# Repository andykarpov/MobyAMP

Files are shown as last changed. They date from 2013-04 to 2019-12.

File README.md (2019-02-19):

This project is a hobbyst DIY 2.1 amplifier based on TDA2030A and TDA1557Q chips.

The heart of the project is an arduino compatible custom board called "interface board" 
with atmega328 microcontroller and 16x2 (or 20x4) LCD panel, encoder, resistive keyboard and audio processor PT2322.
It is possible to make it even on a breadboard using a standard arduino and couple of wires :)

Some basic boards, such as interface board and amp boards contains both pcb design and electrical schematics.
All drawing (build/pdfs/pngs/etc) are already prepared to be printed on transarent sheets to make a final PCBs 
from the presensitized PCBs at home.

A few other things are not yet described (such as power board, connection between modules, etc, etc).
To be continued...

Custom eagle libraries are located under eagle_libraries folder.
To make a gerber / images from the command line you must have:
1. OSX (could work on other UNIX/Linux boxes)
2. eagle
3. homebrew
4. gerbv

Scripts should be changed to reflect a current Eagle installation path.

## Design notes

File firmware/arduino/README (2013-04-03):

Dependencies:

1. I2C library:  http://dsscircuits.com/articles/arduino-i2c-master-library.html
2. Encoder library: http://www.pjrc.com/teensy/td_libs_Encoder.html
3. Button library: http://playground.arduino.cc/Code/Button

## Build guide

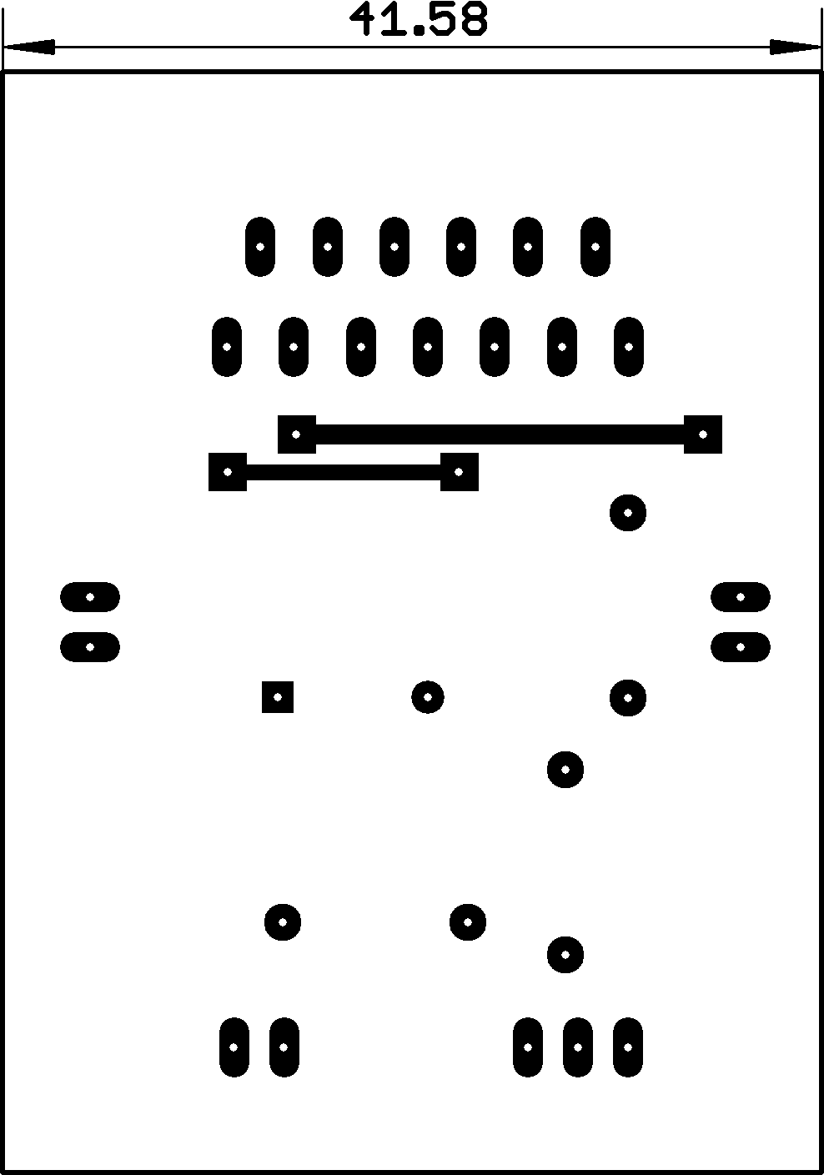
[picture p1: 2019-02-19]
build/png/tda1557q_v_1_0_pcb_top.png

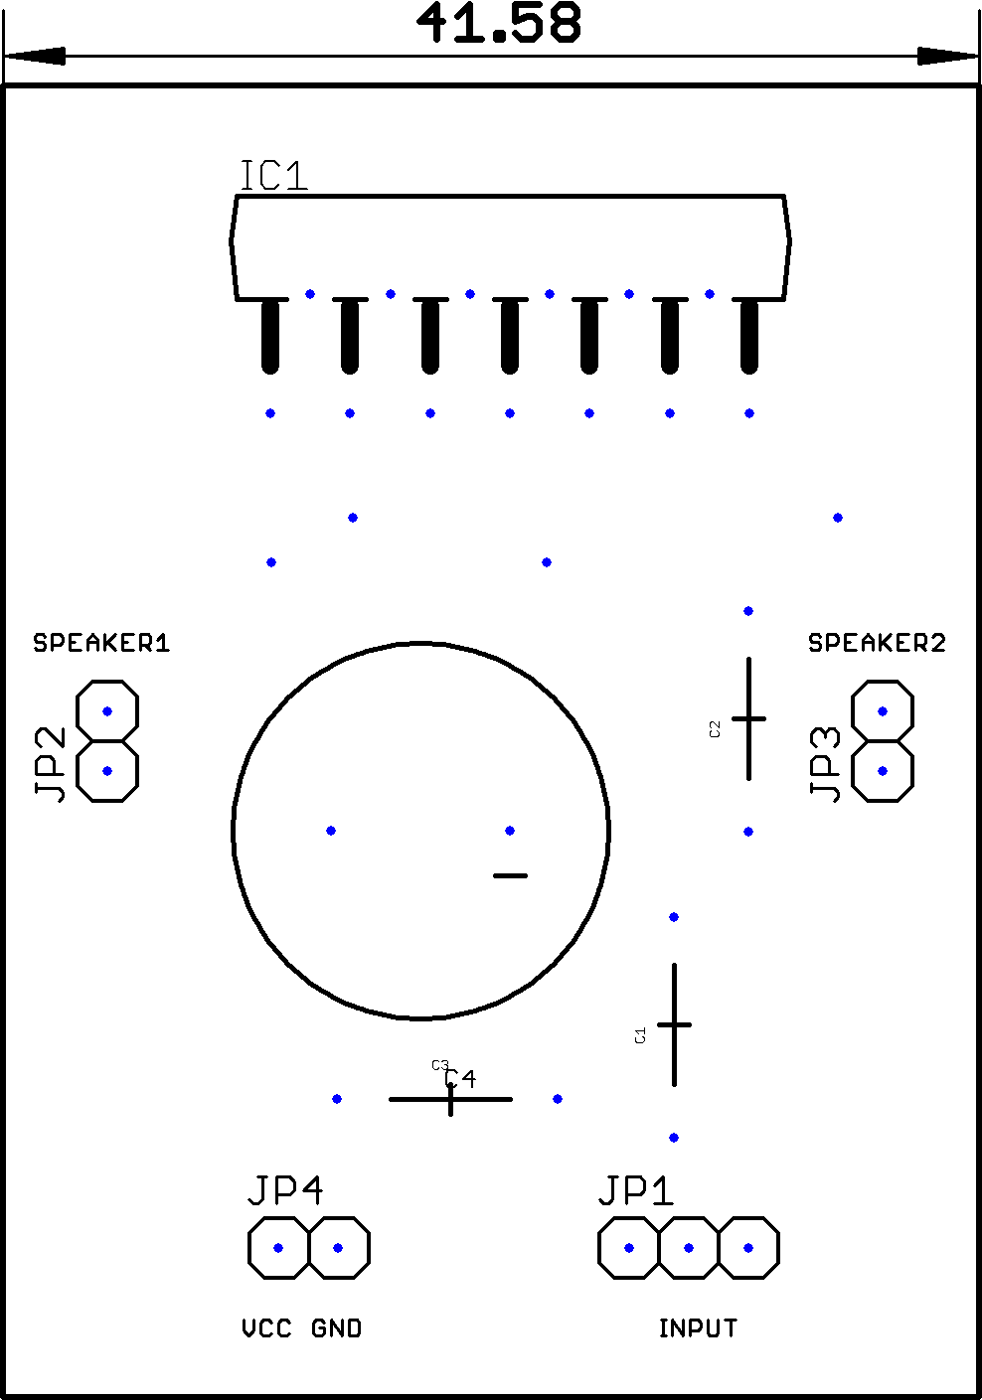
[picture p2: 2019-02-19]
build/png/tda1557q_v_1_0_pcb_cmp.png

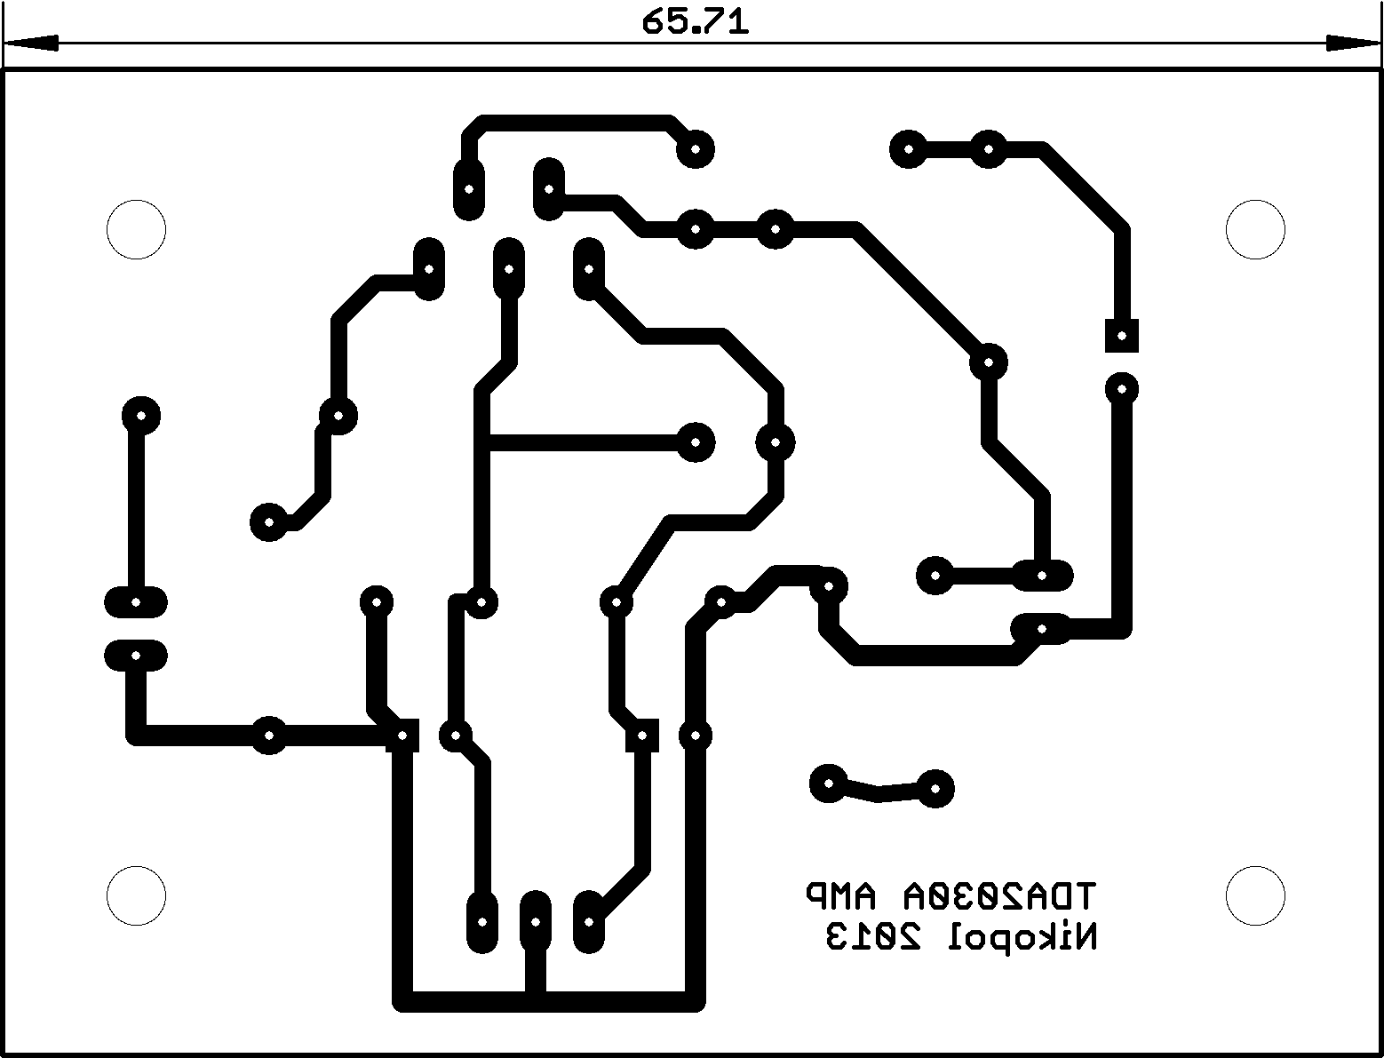
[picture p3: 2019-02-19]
build/png/tda2030a_v_1_0_pcb_bottom.png

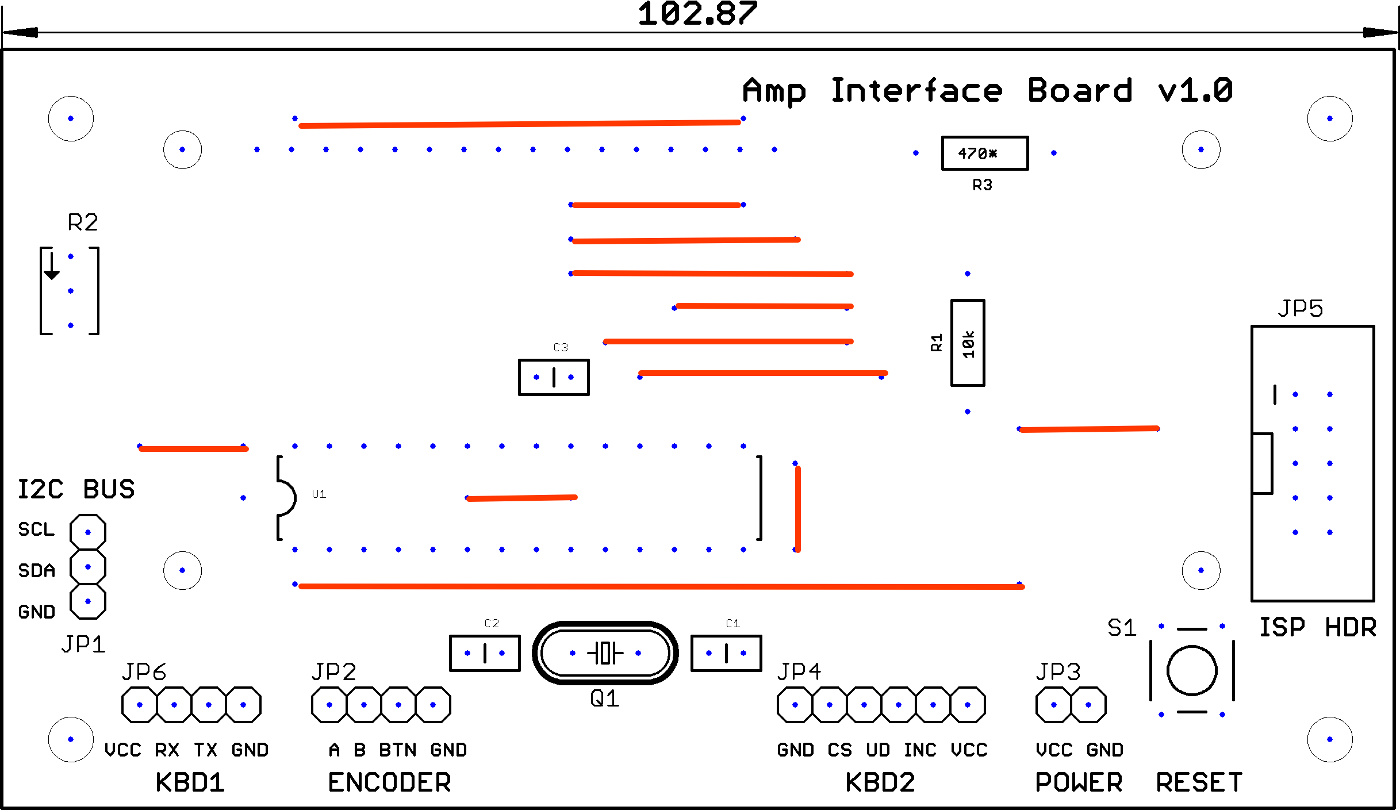
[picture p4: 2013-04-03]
build/png/interface_v_1_0_pcb_cmp_jumpered.png

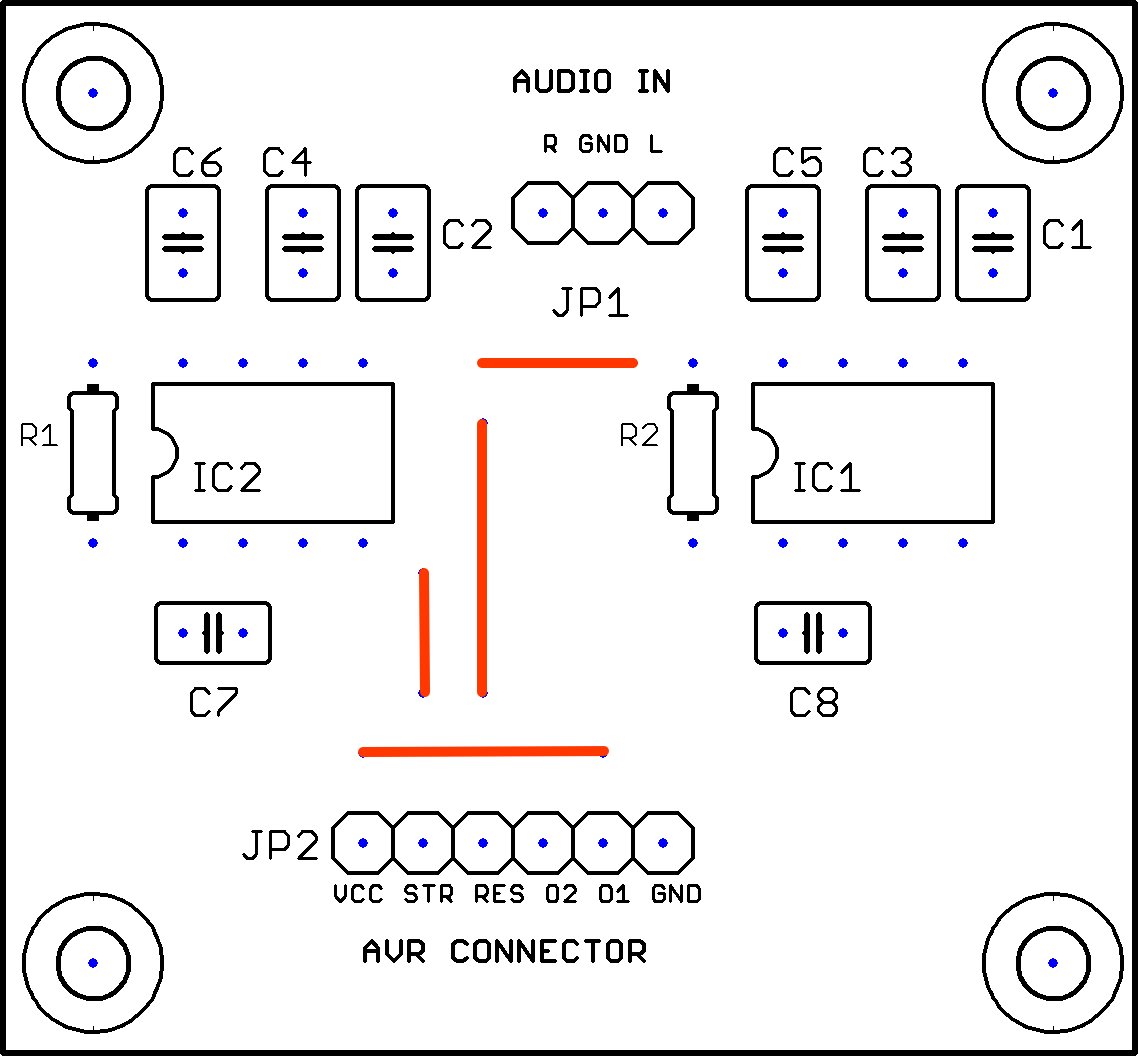
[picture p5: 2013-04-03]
build/png/msgeq7_v_1_0_pcb_cmp_jumpered.png

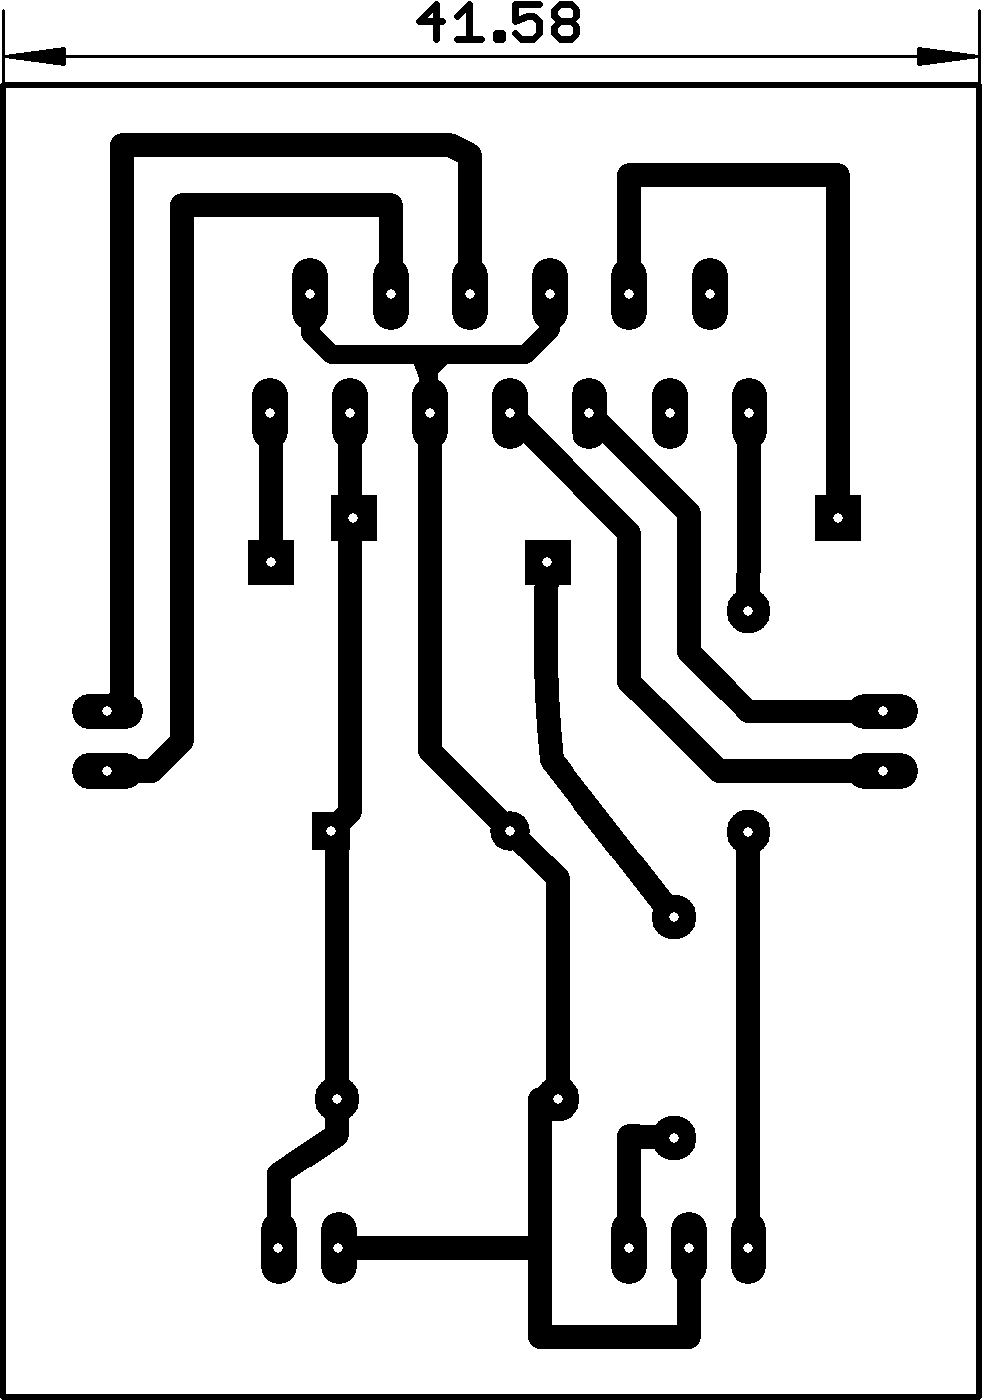
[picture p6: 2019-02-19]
build/png/tda1557q_v_1_0_pcb_bottom.png

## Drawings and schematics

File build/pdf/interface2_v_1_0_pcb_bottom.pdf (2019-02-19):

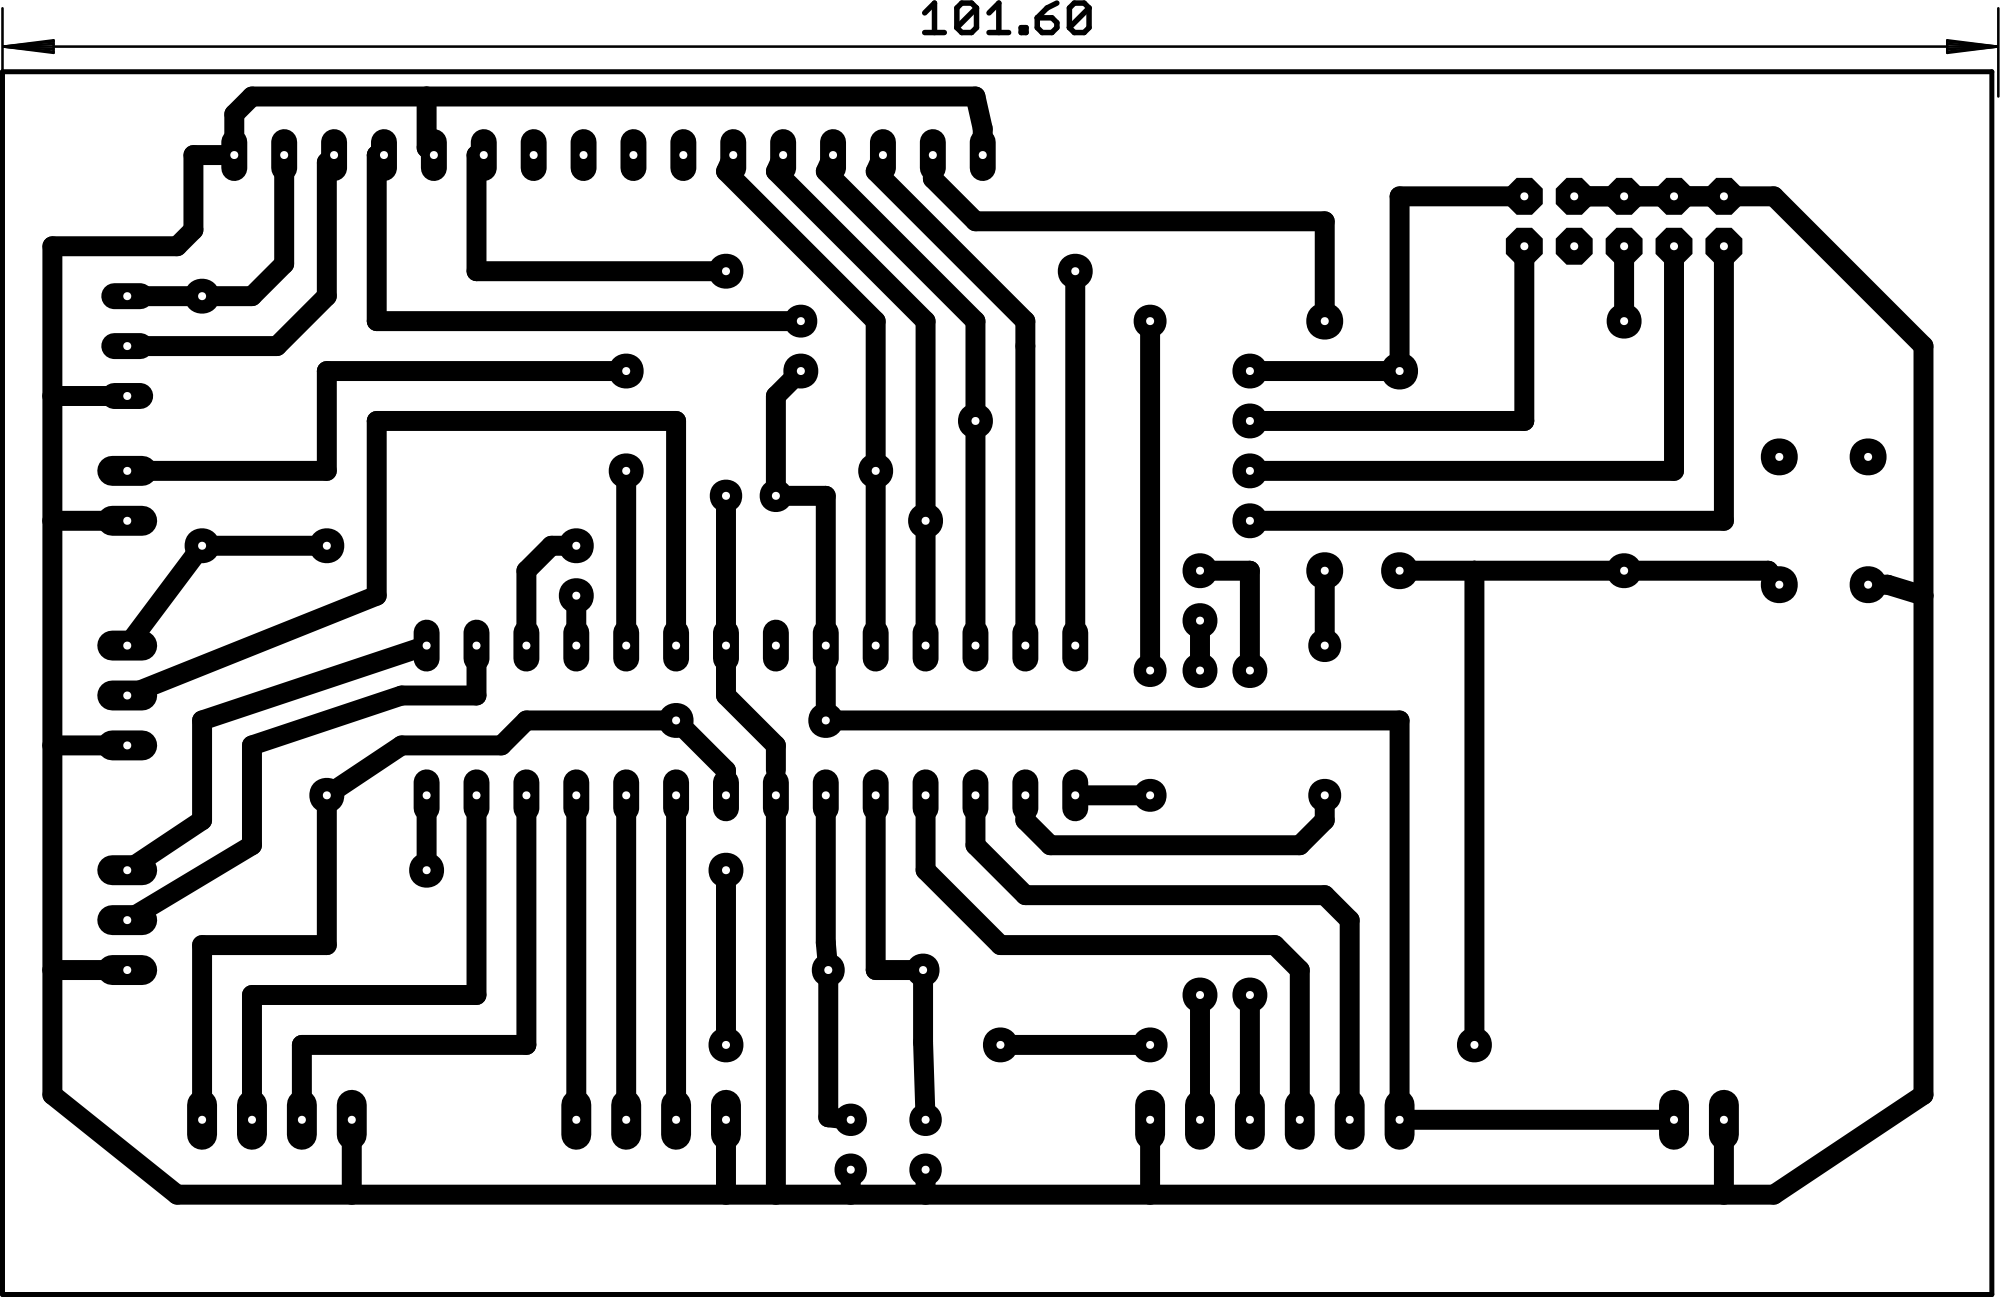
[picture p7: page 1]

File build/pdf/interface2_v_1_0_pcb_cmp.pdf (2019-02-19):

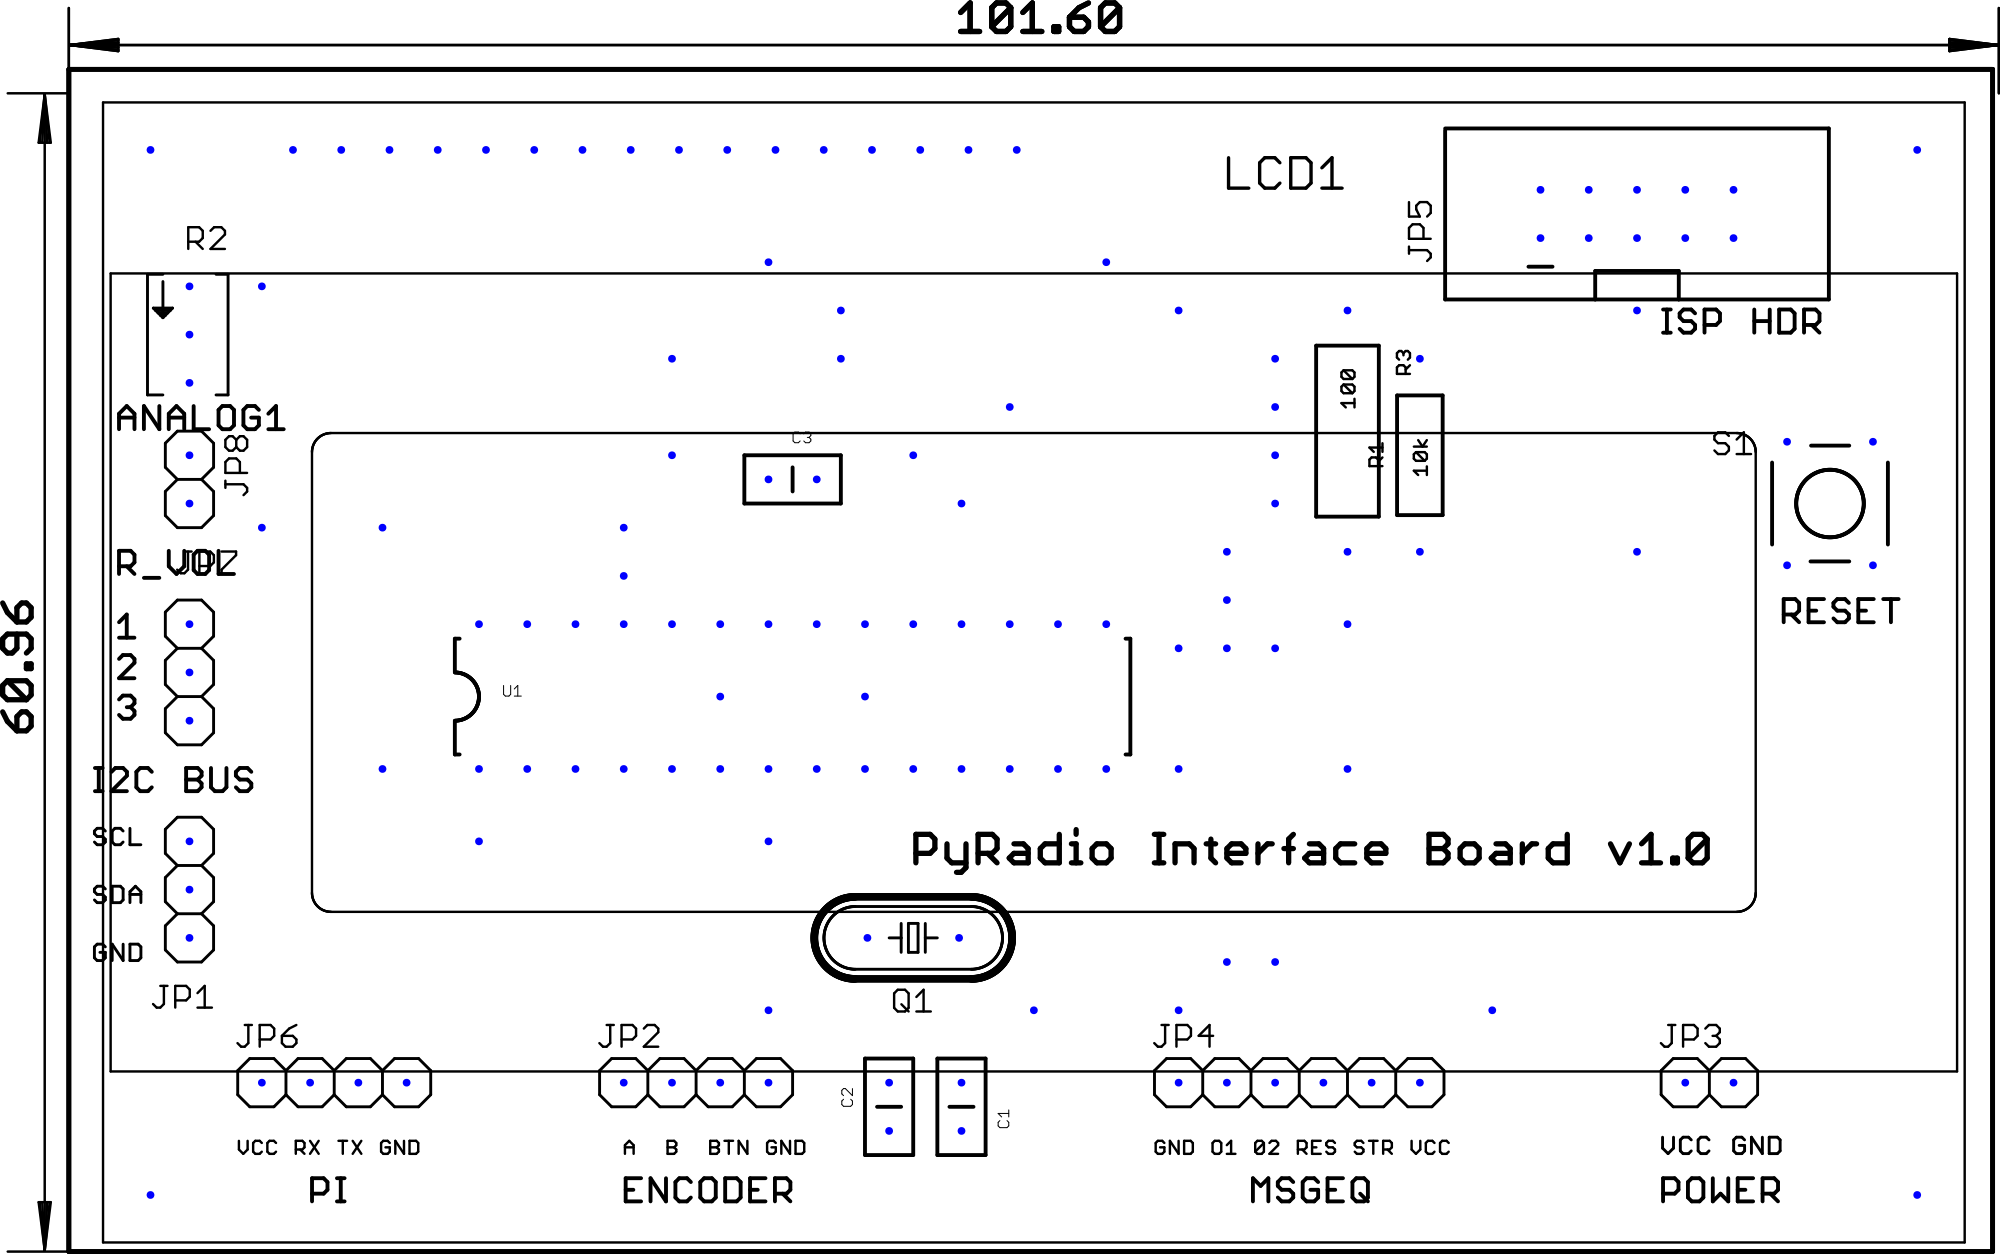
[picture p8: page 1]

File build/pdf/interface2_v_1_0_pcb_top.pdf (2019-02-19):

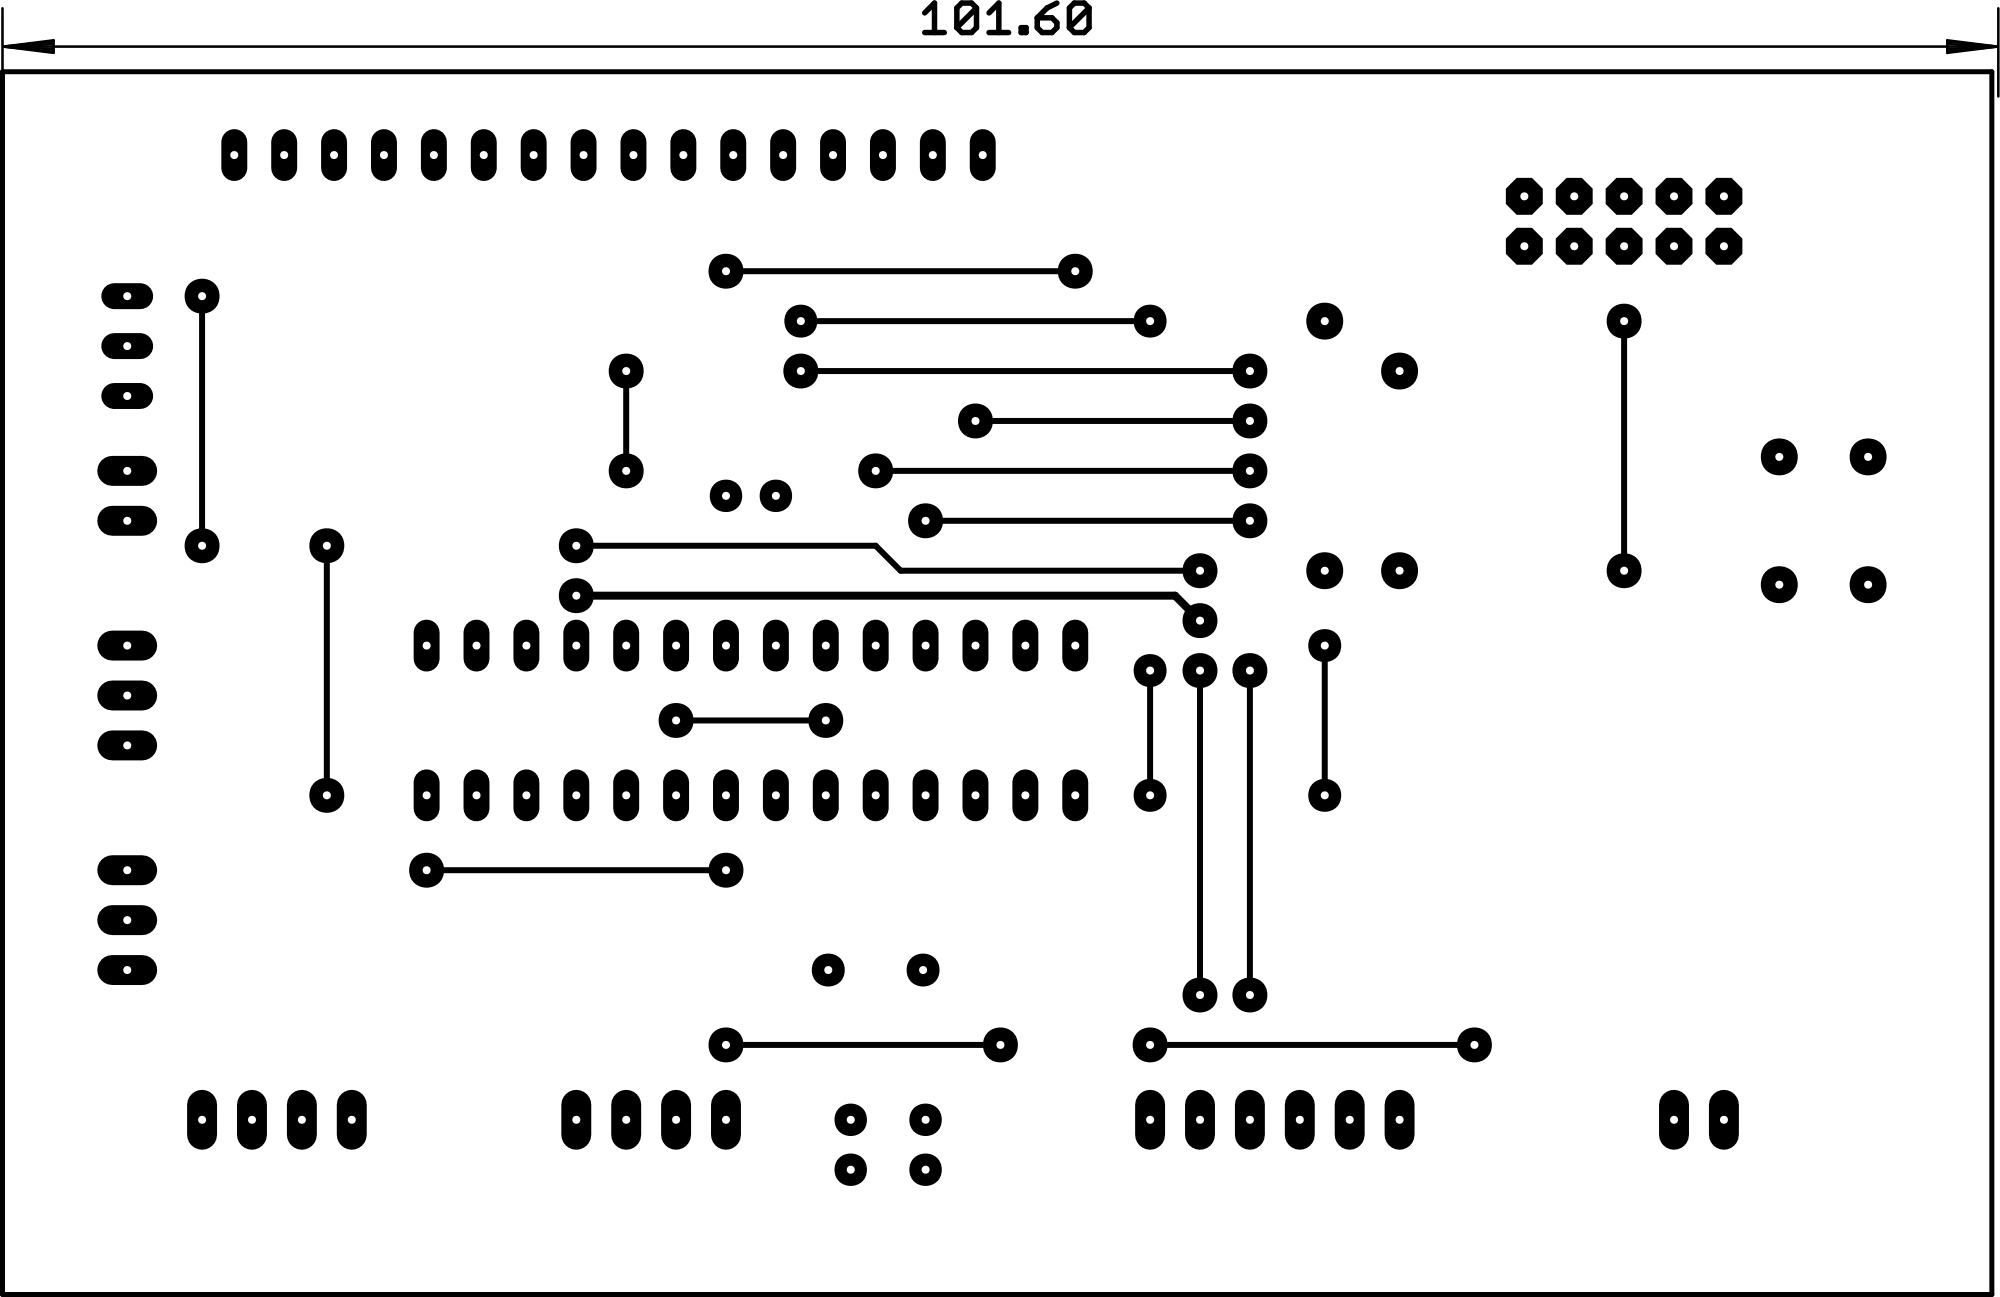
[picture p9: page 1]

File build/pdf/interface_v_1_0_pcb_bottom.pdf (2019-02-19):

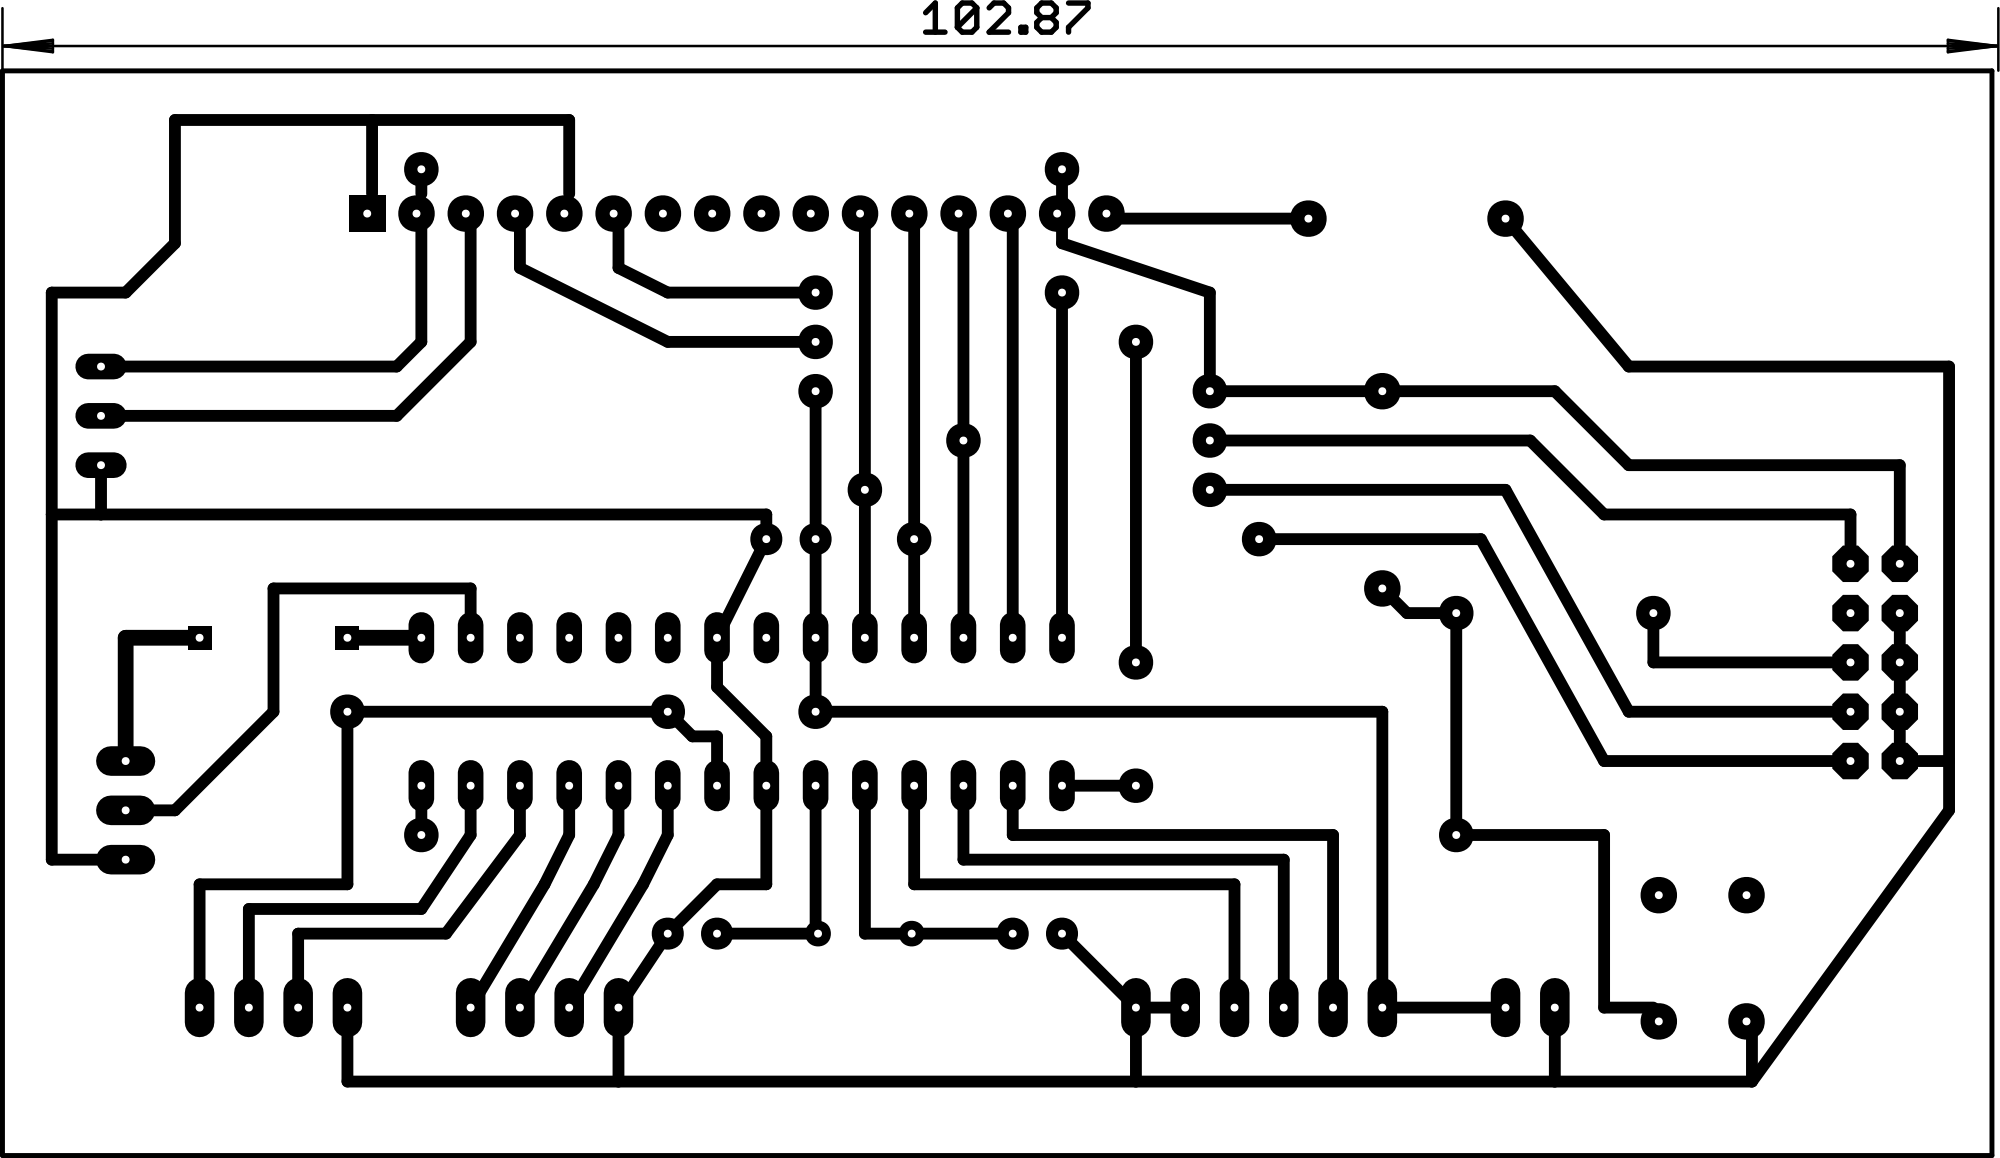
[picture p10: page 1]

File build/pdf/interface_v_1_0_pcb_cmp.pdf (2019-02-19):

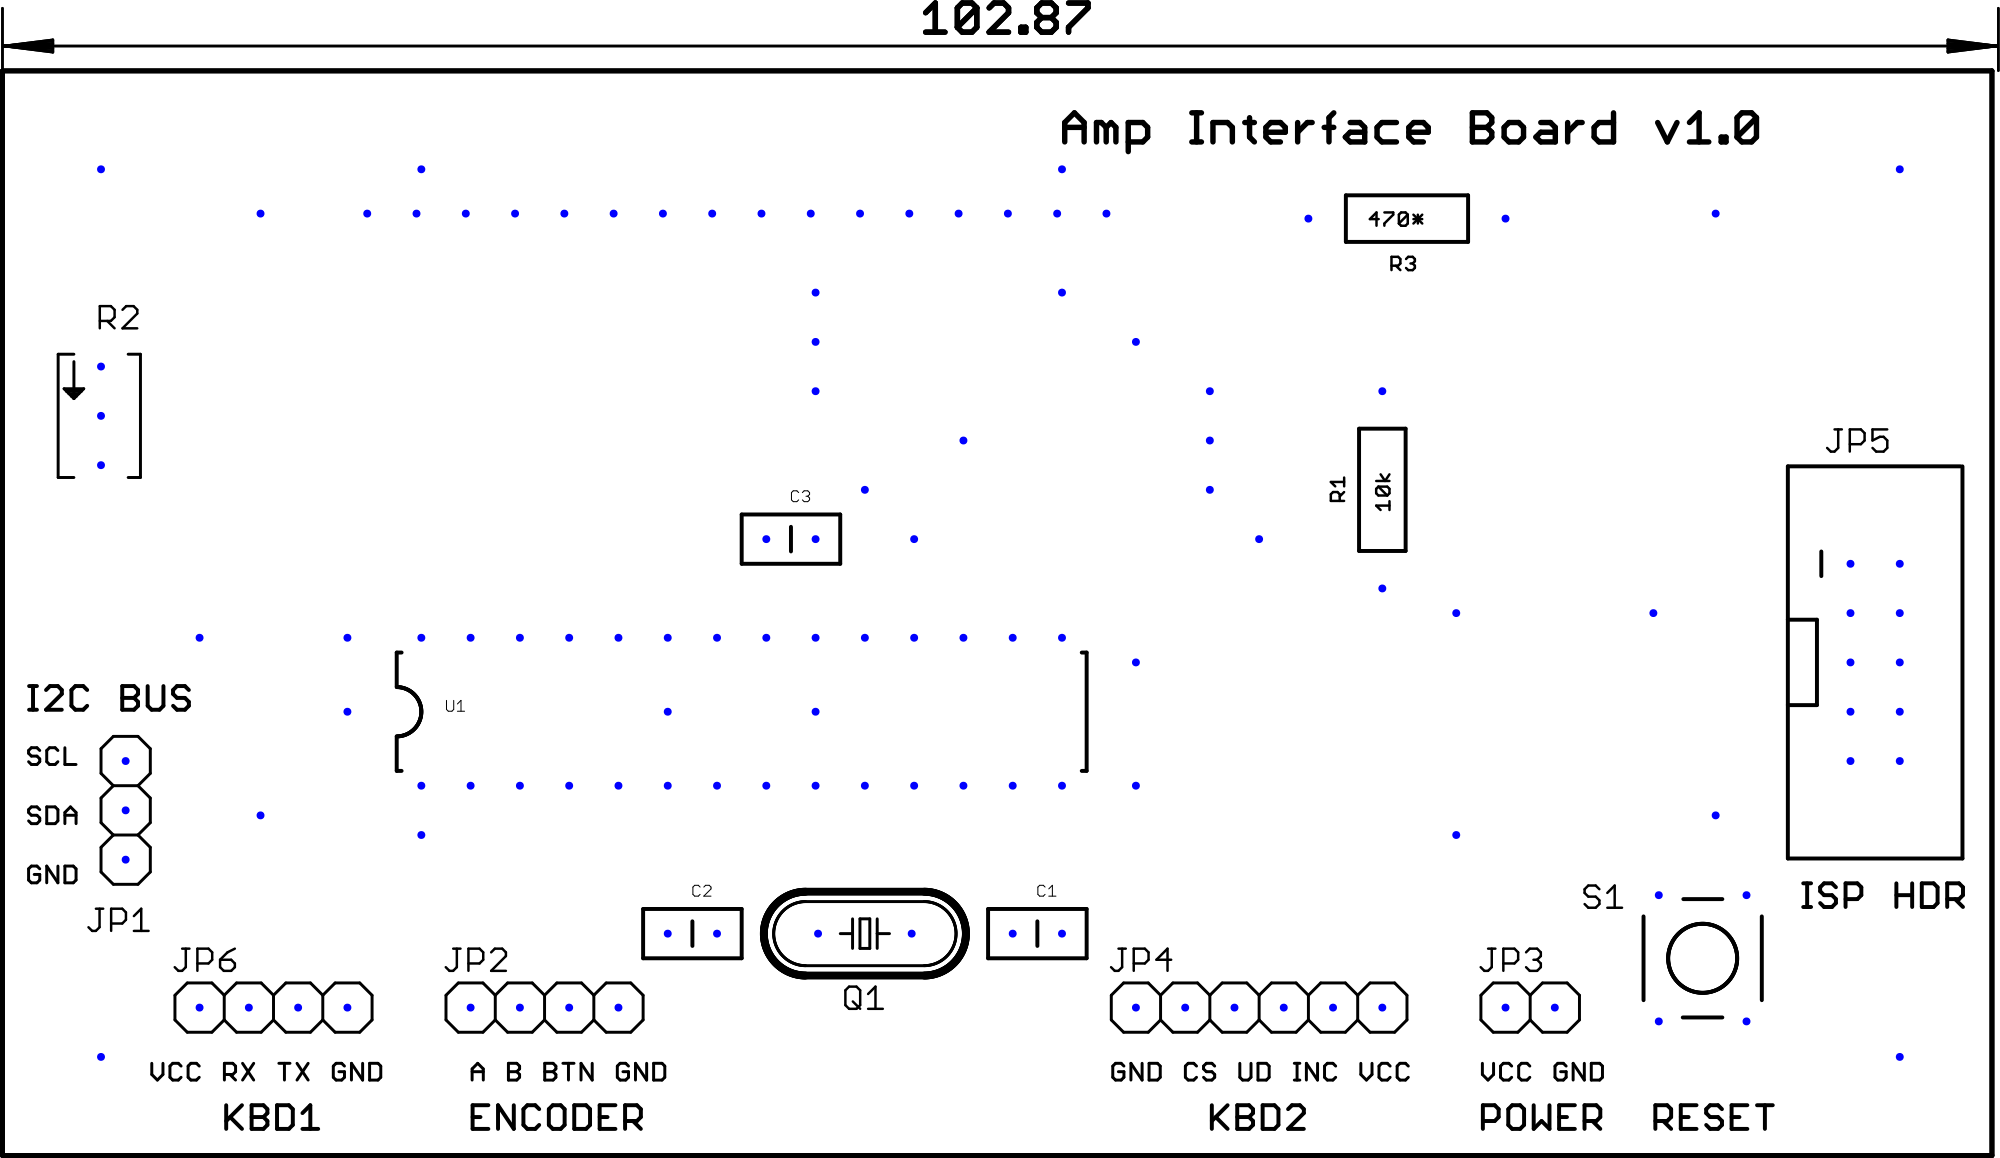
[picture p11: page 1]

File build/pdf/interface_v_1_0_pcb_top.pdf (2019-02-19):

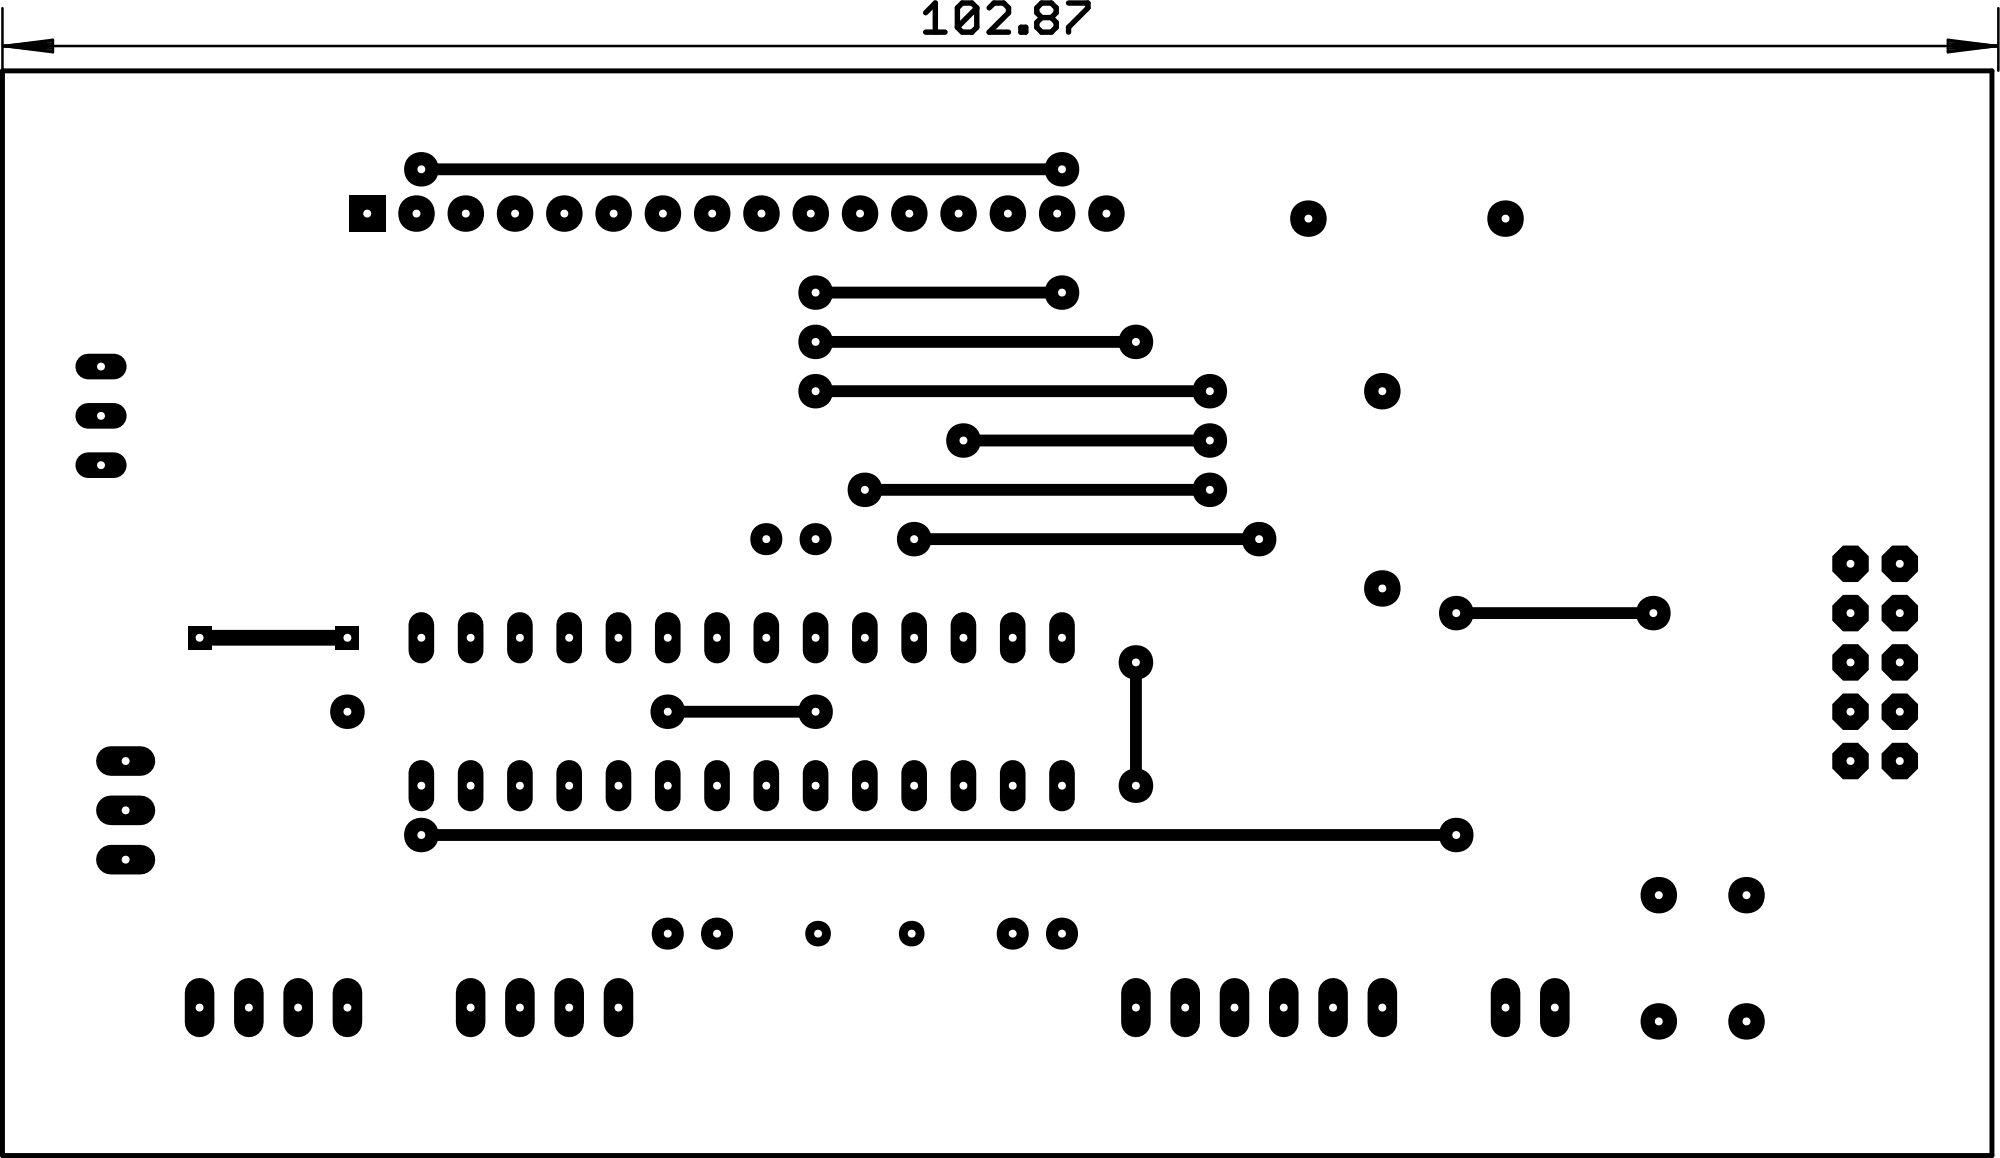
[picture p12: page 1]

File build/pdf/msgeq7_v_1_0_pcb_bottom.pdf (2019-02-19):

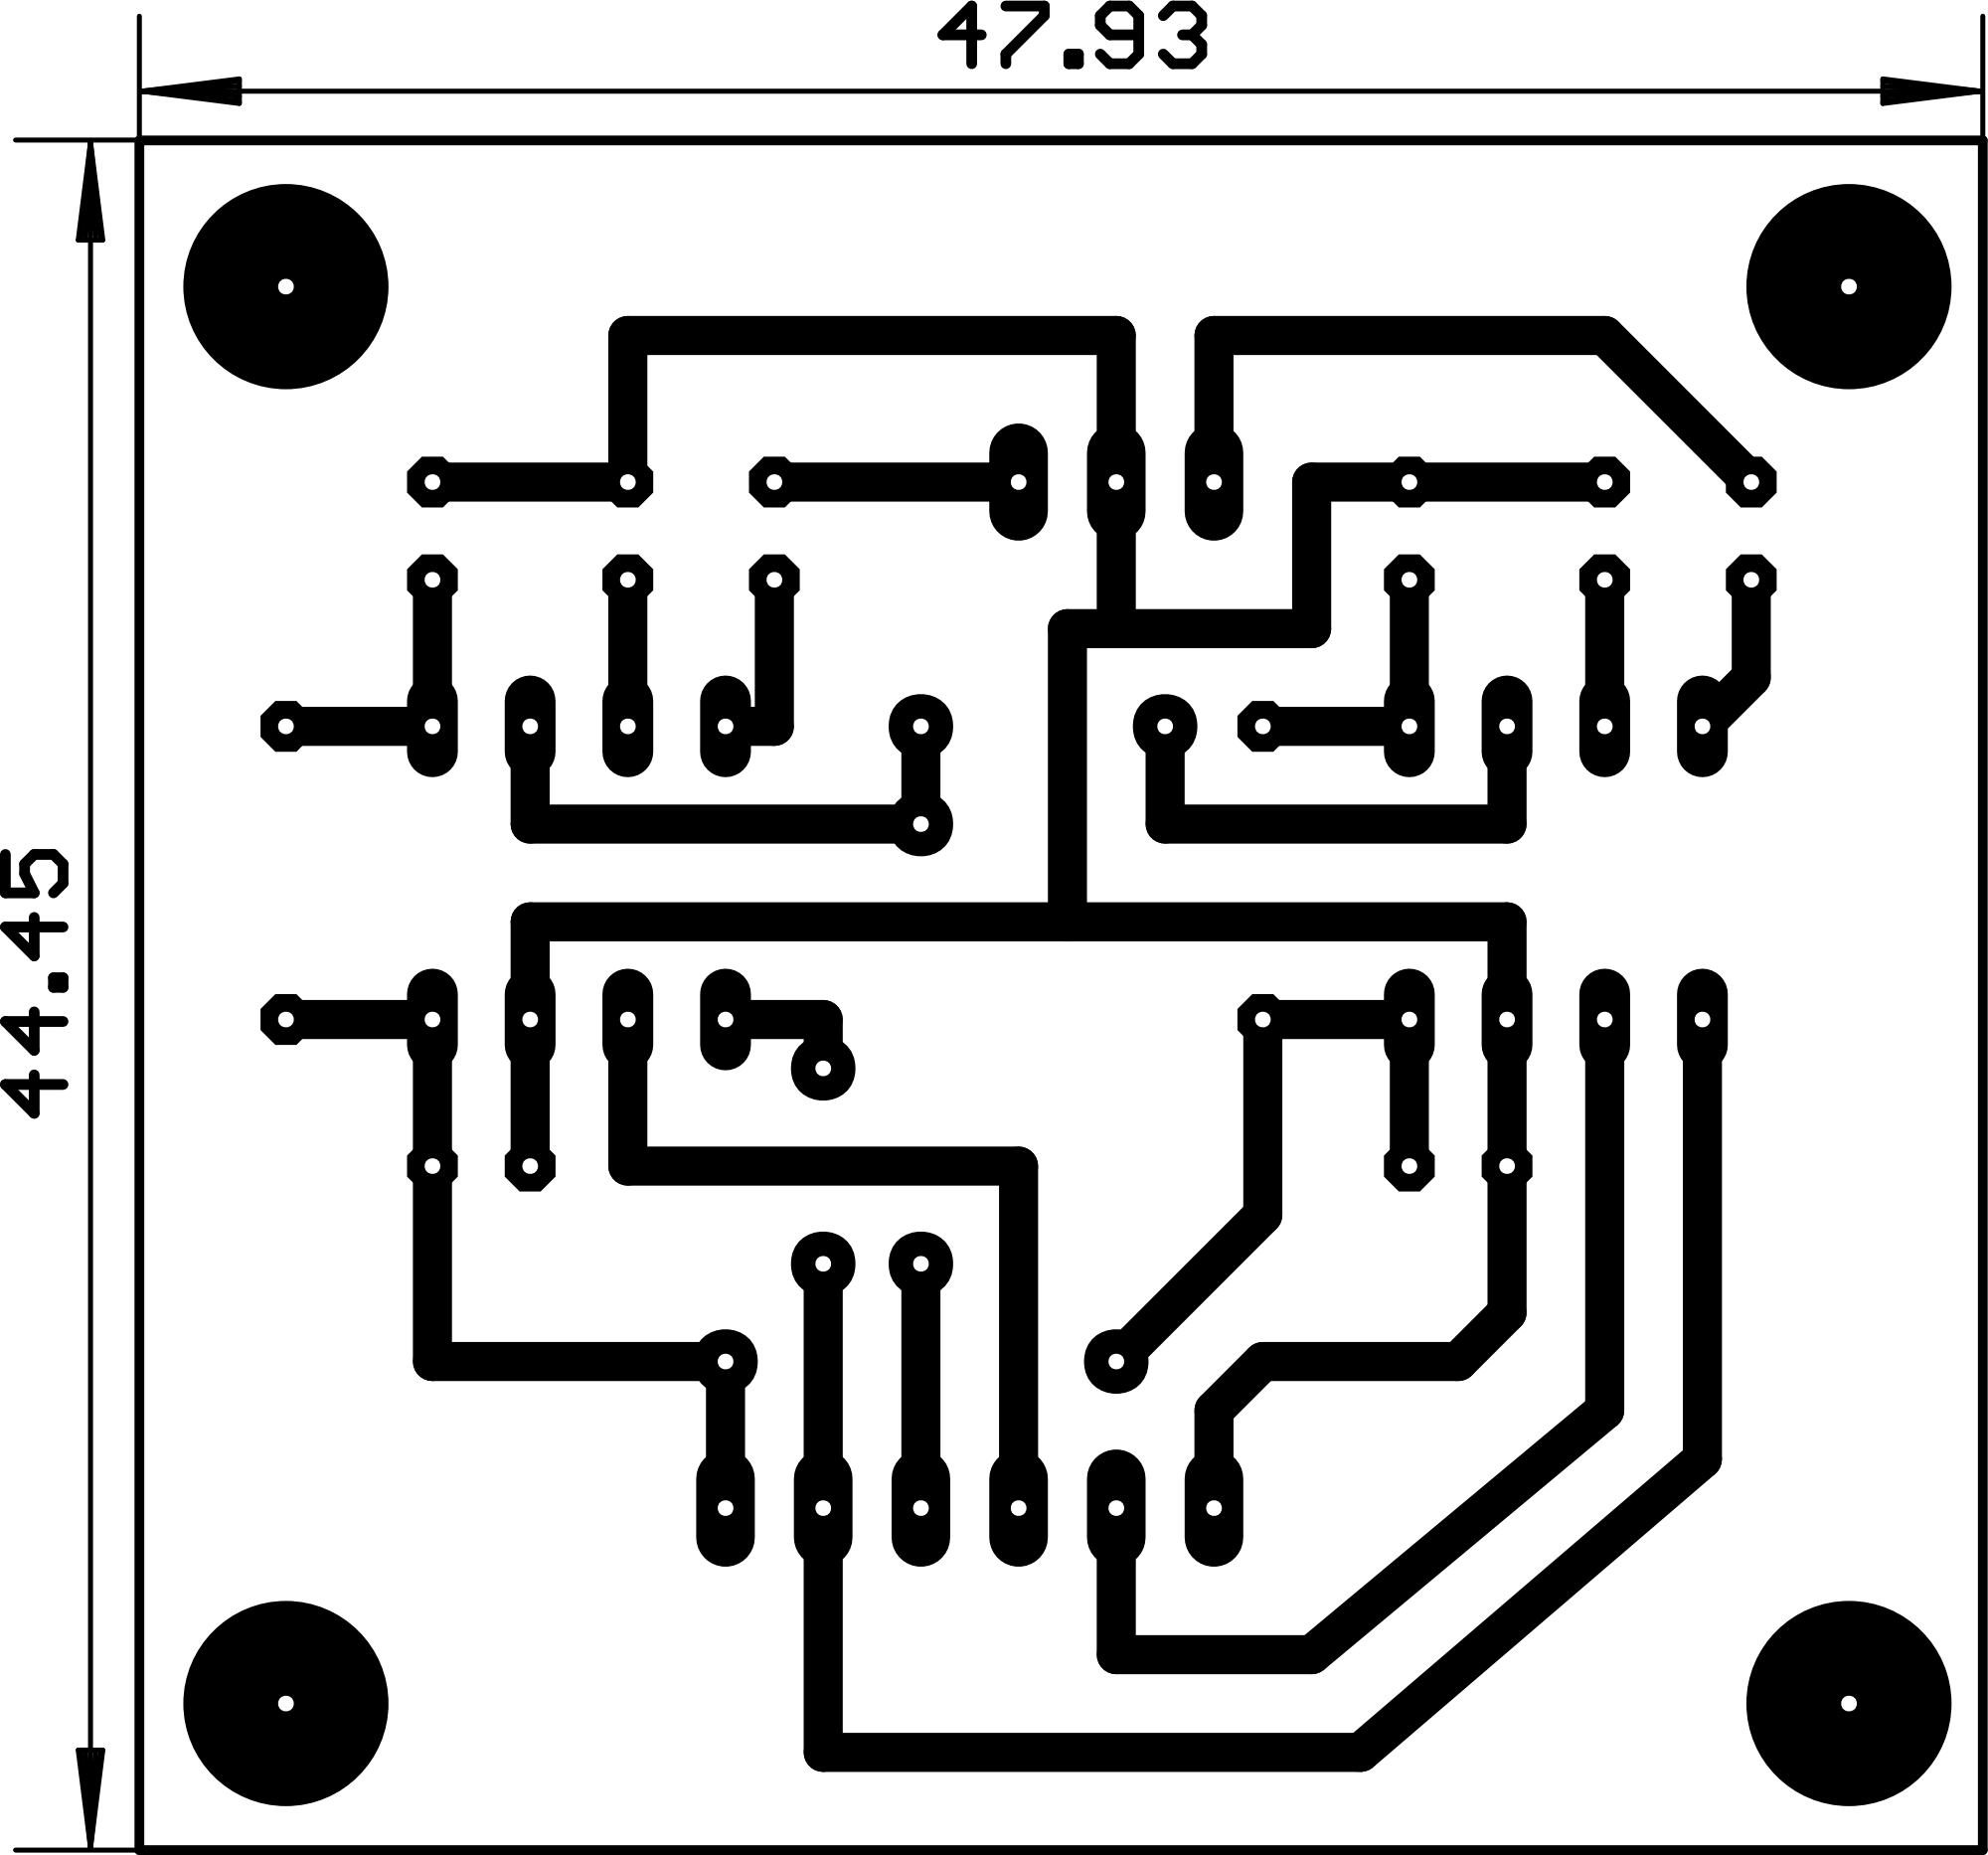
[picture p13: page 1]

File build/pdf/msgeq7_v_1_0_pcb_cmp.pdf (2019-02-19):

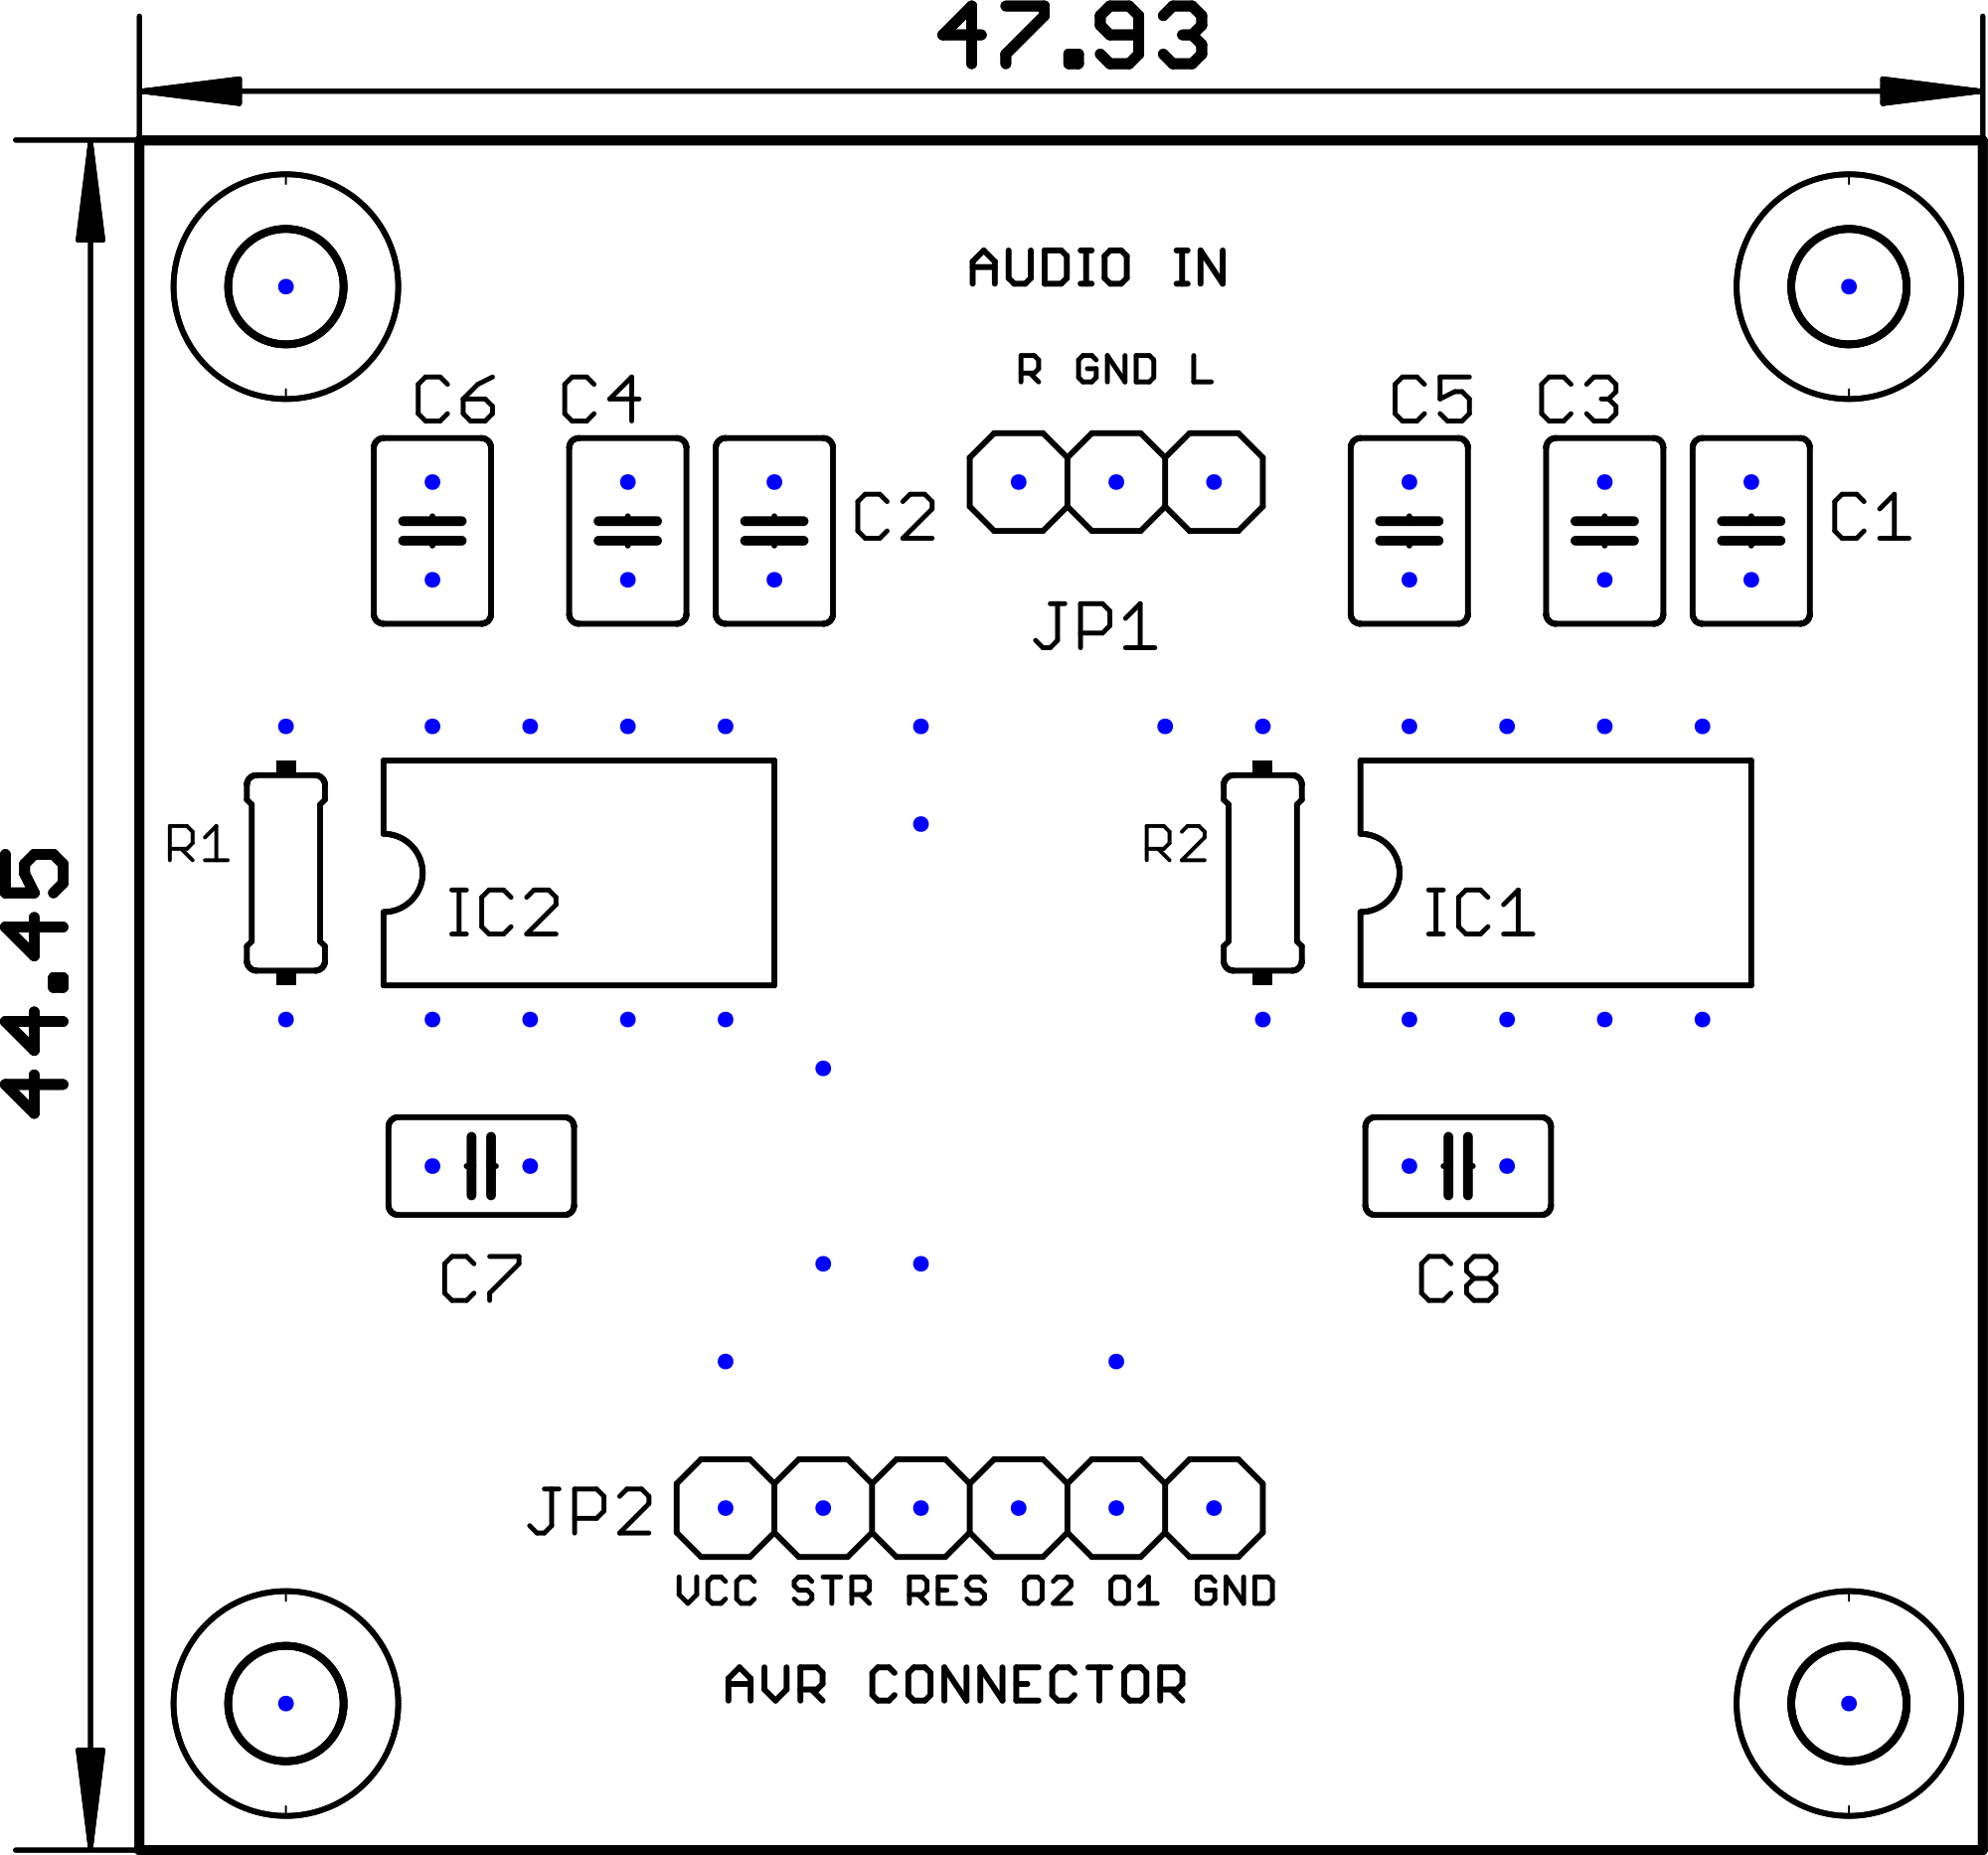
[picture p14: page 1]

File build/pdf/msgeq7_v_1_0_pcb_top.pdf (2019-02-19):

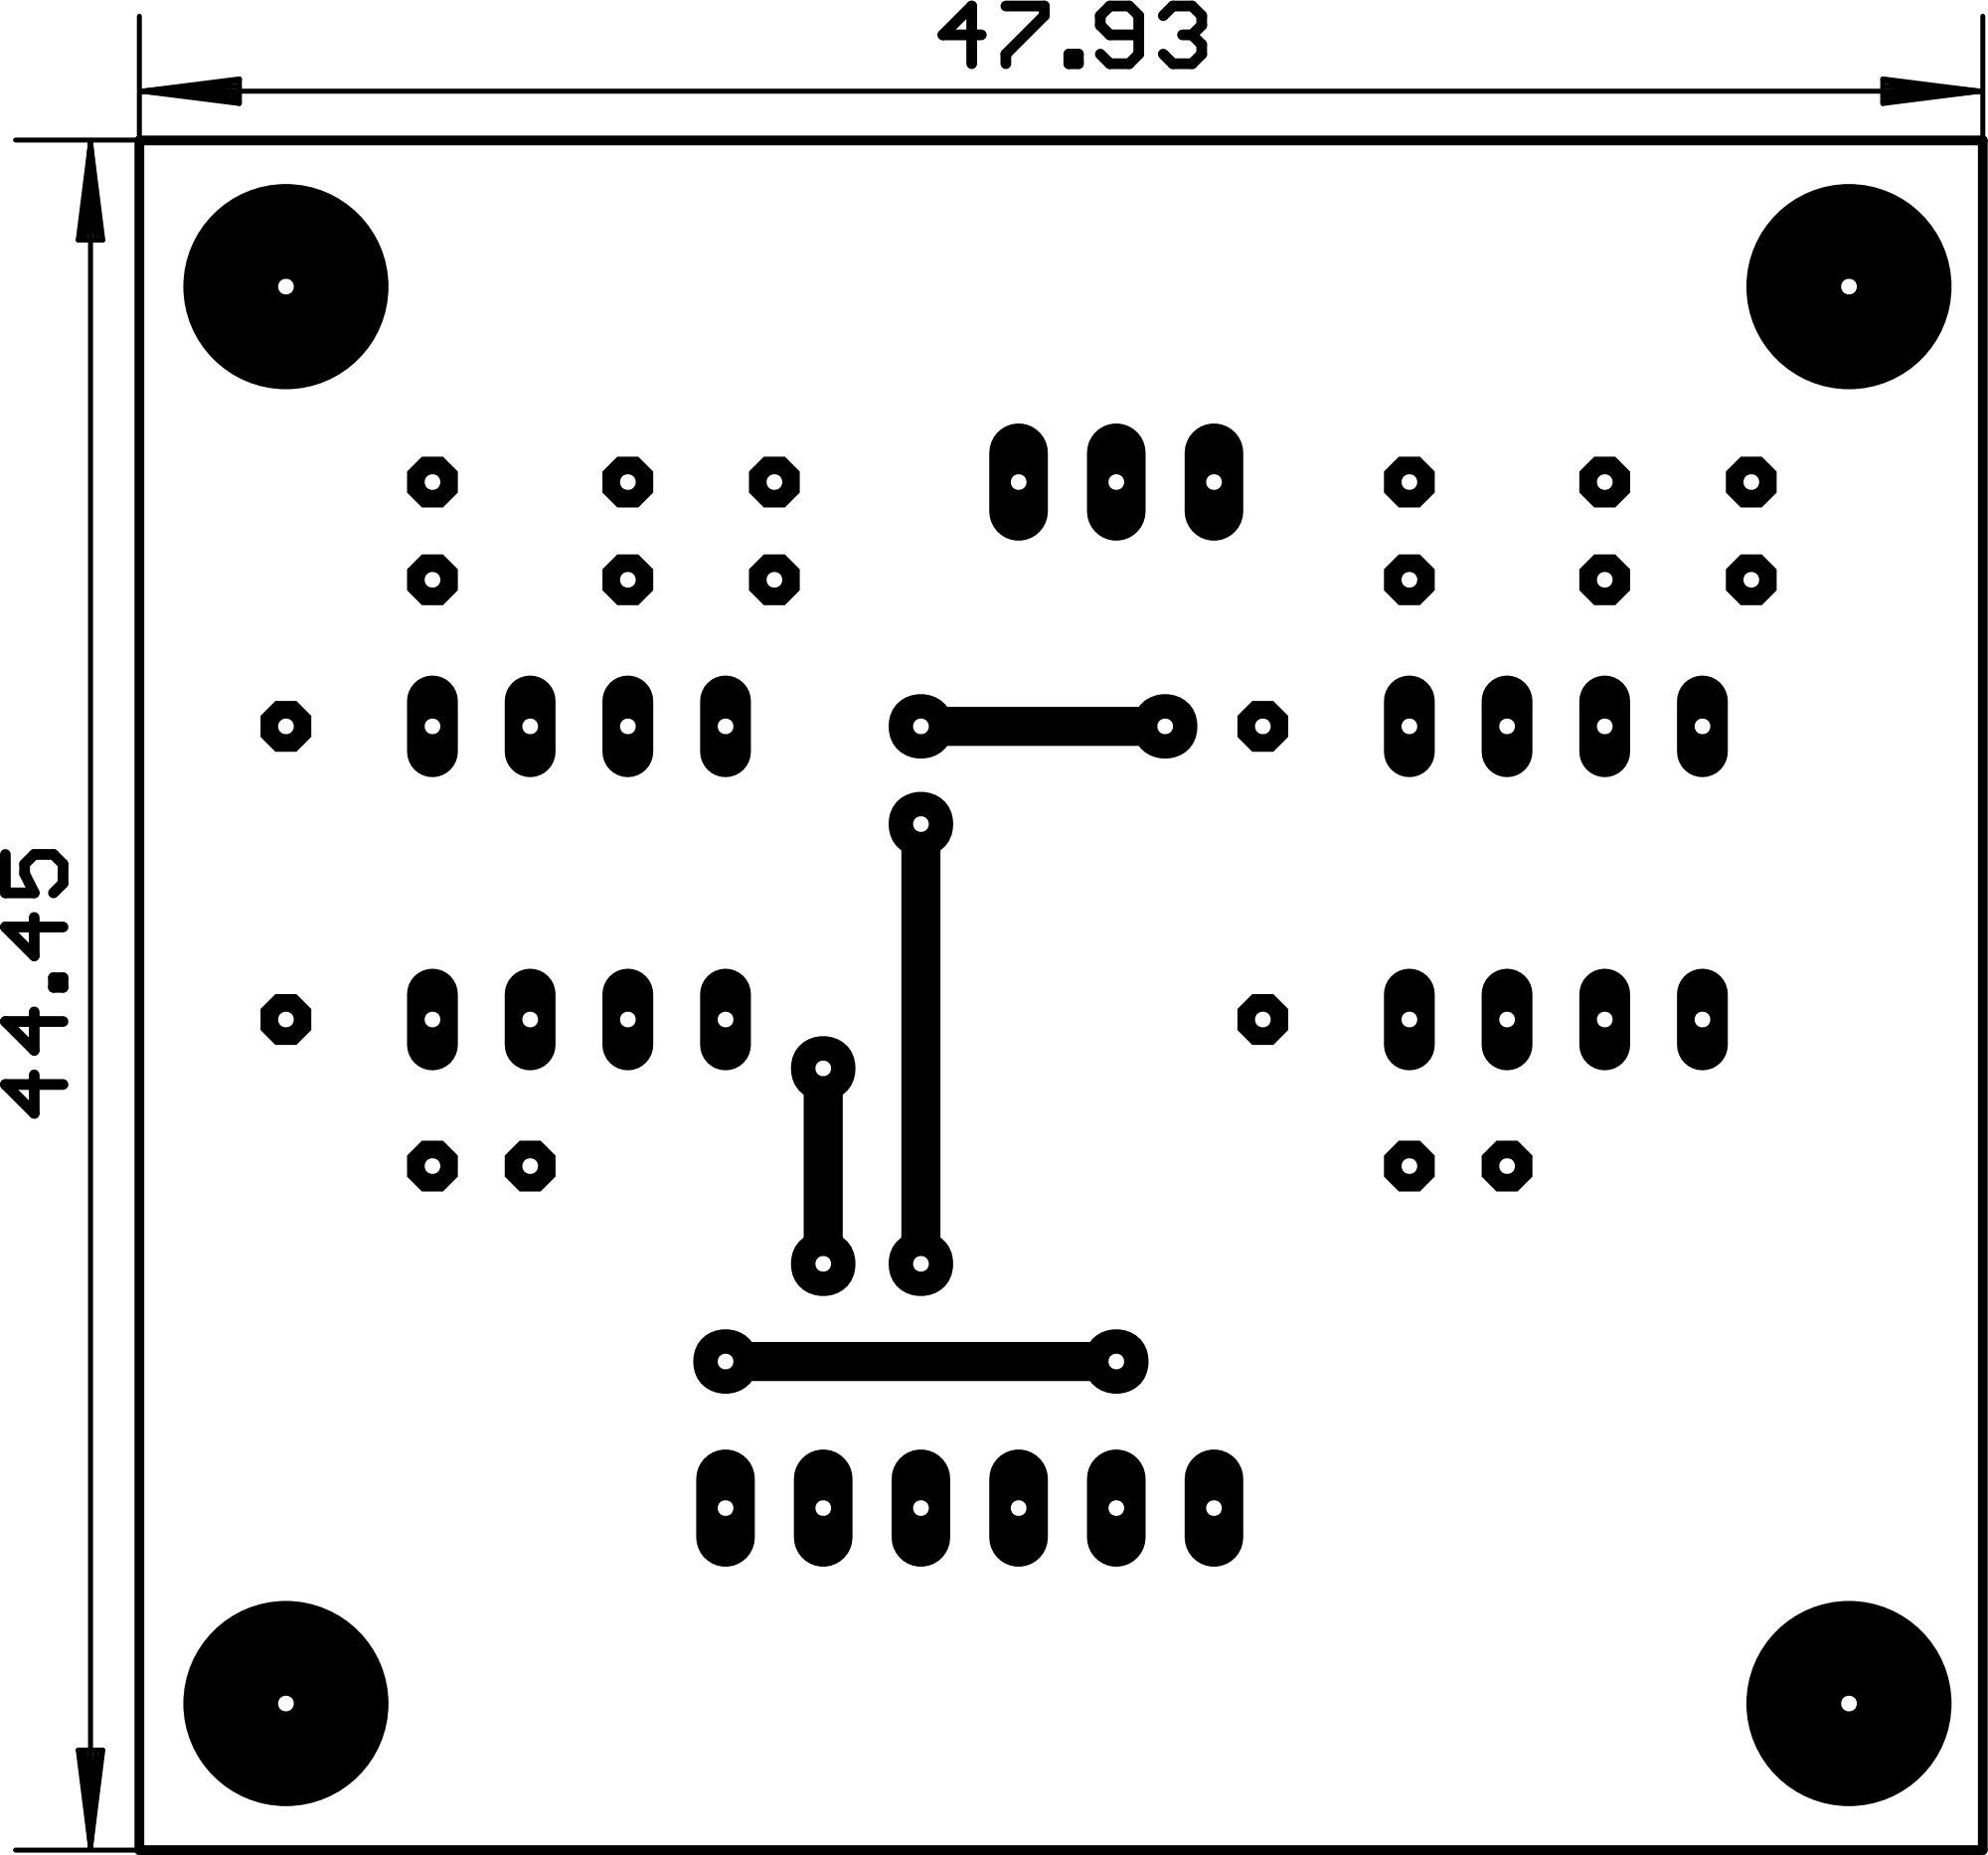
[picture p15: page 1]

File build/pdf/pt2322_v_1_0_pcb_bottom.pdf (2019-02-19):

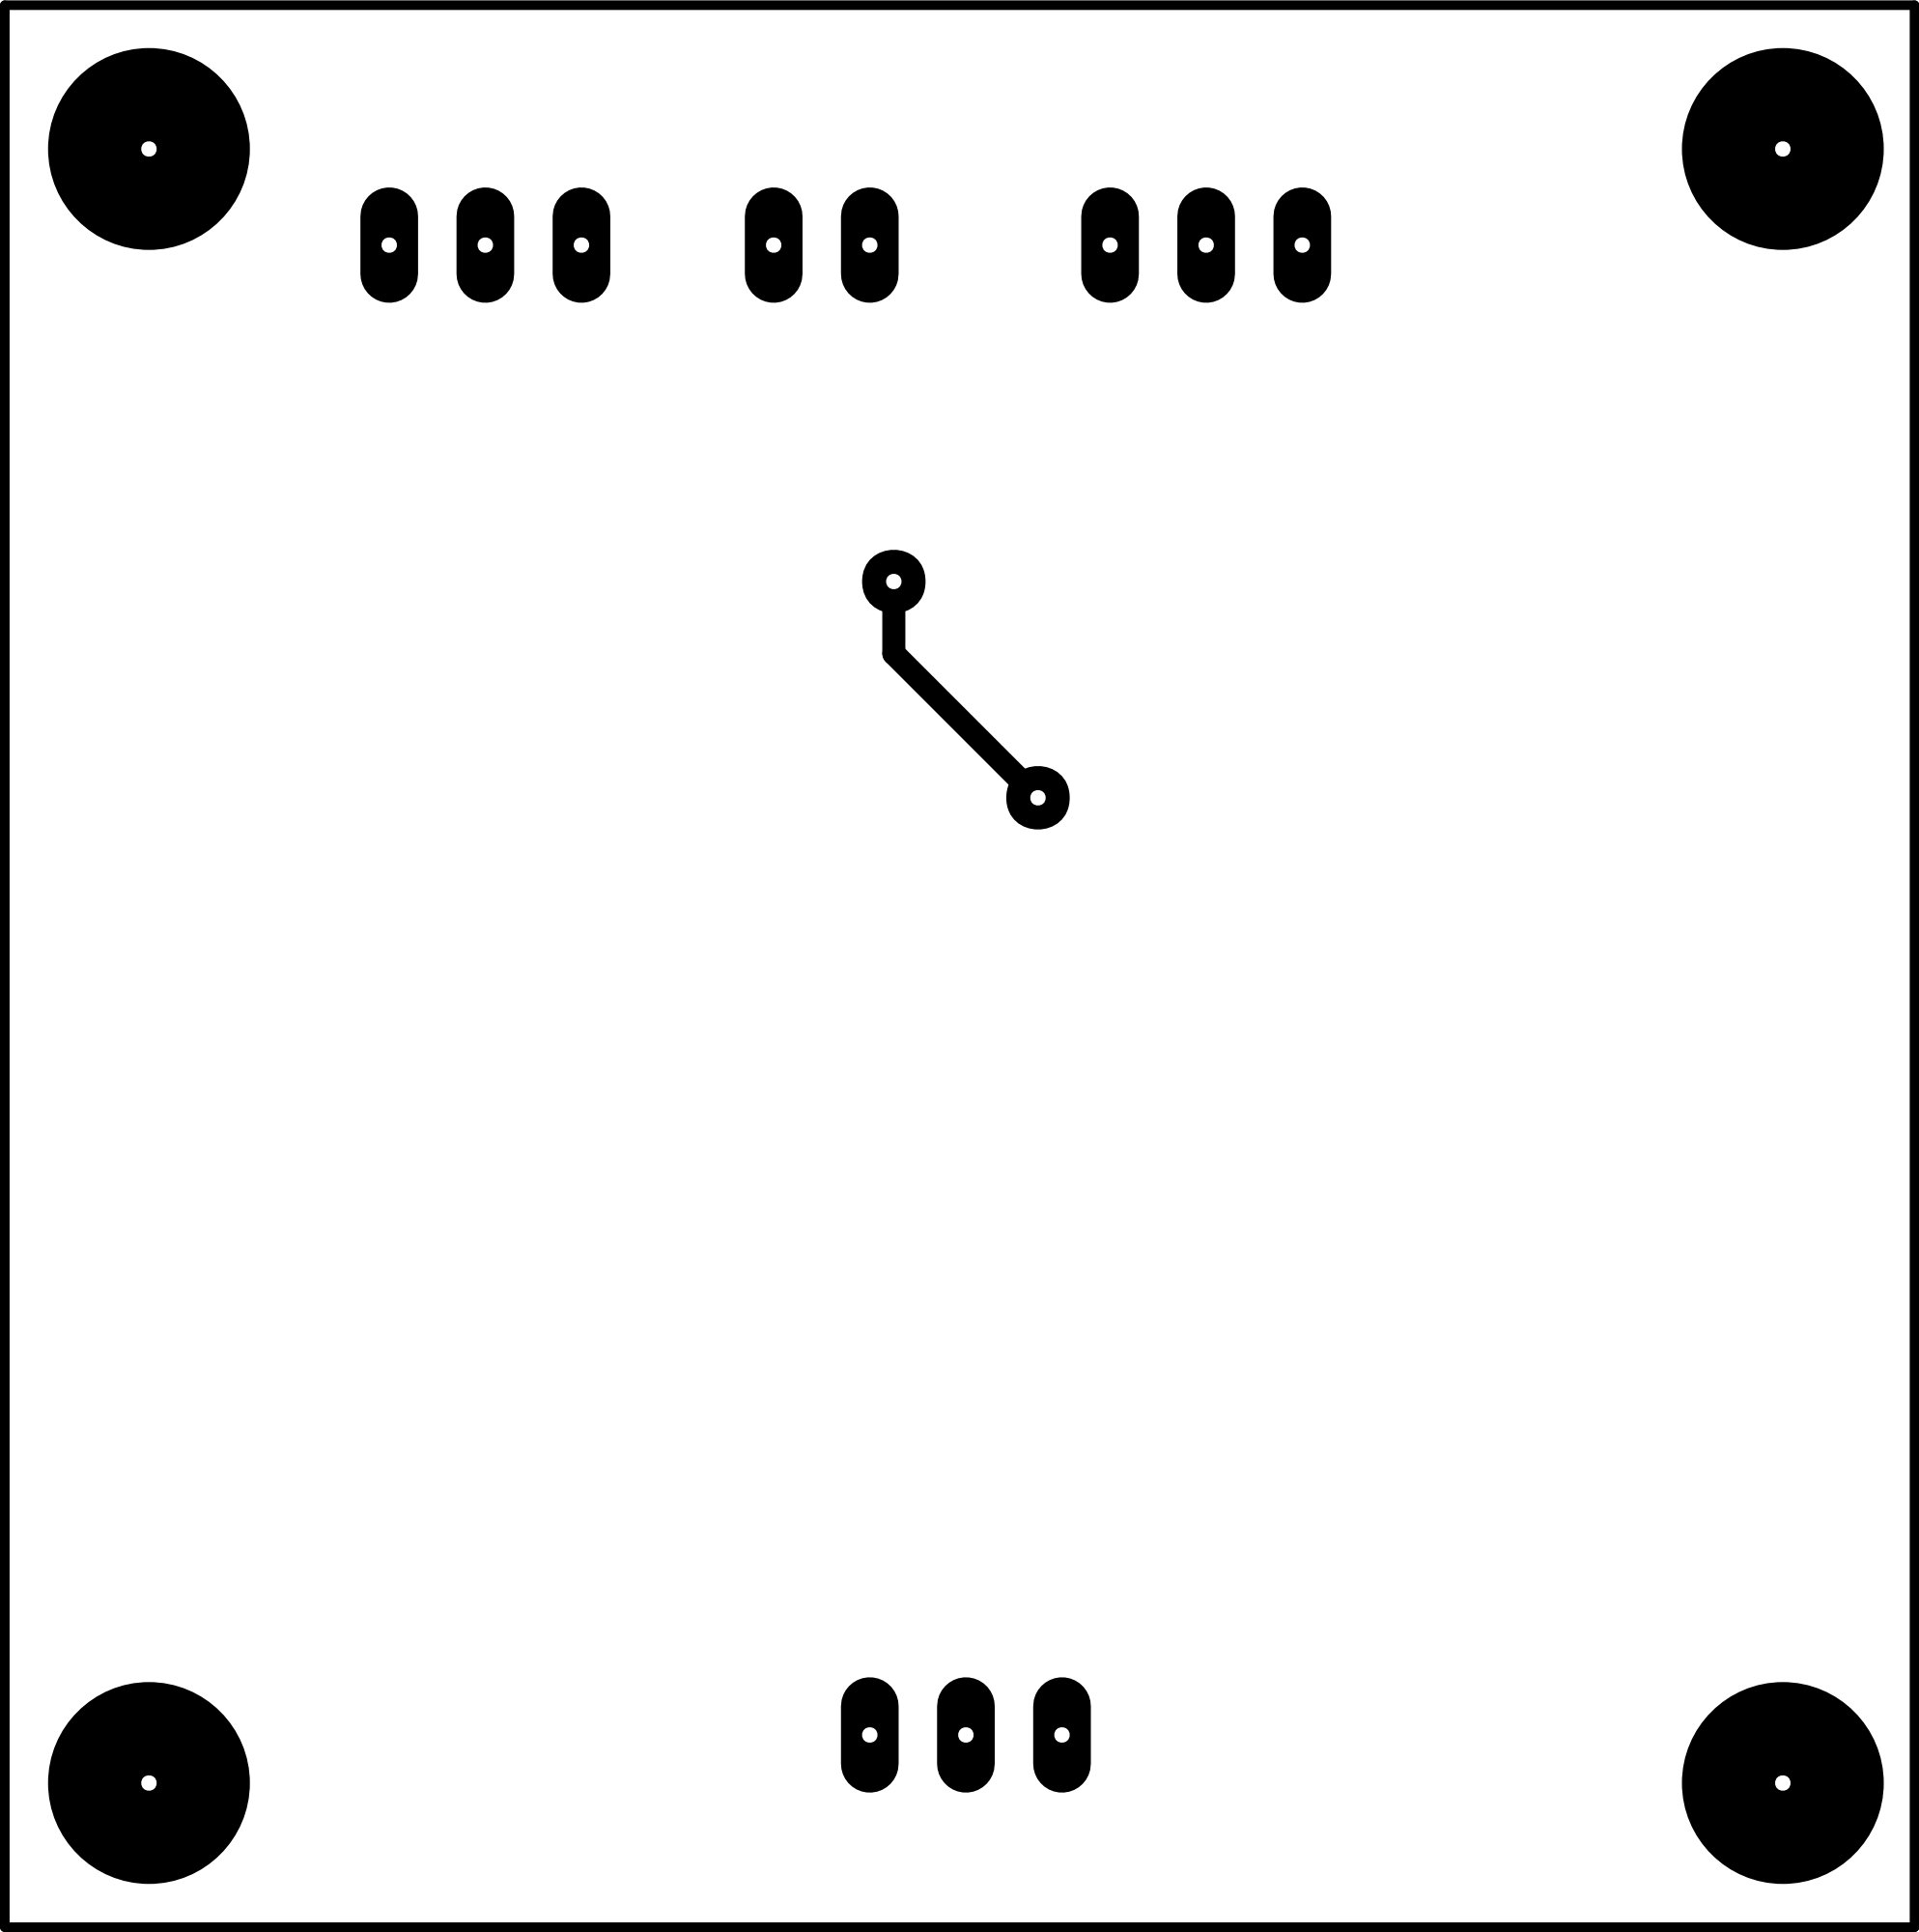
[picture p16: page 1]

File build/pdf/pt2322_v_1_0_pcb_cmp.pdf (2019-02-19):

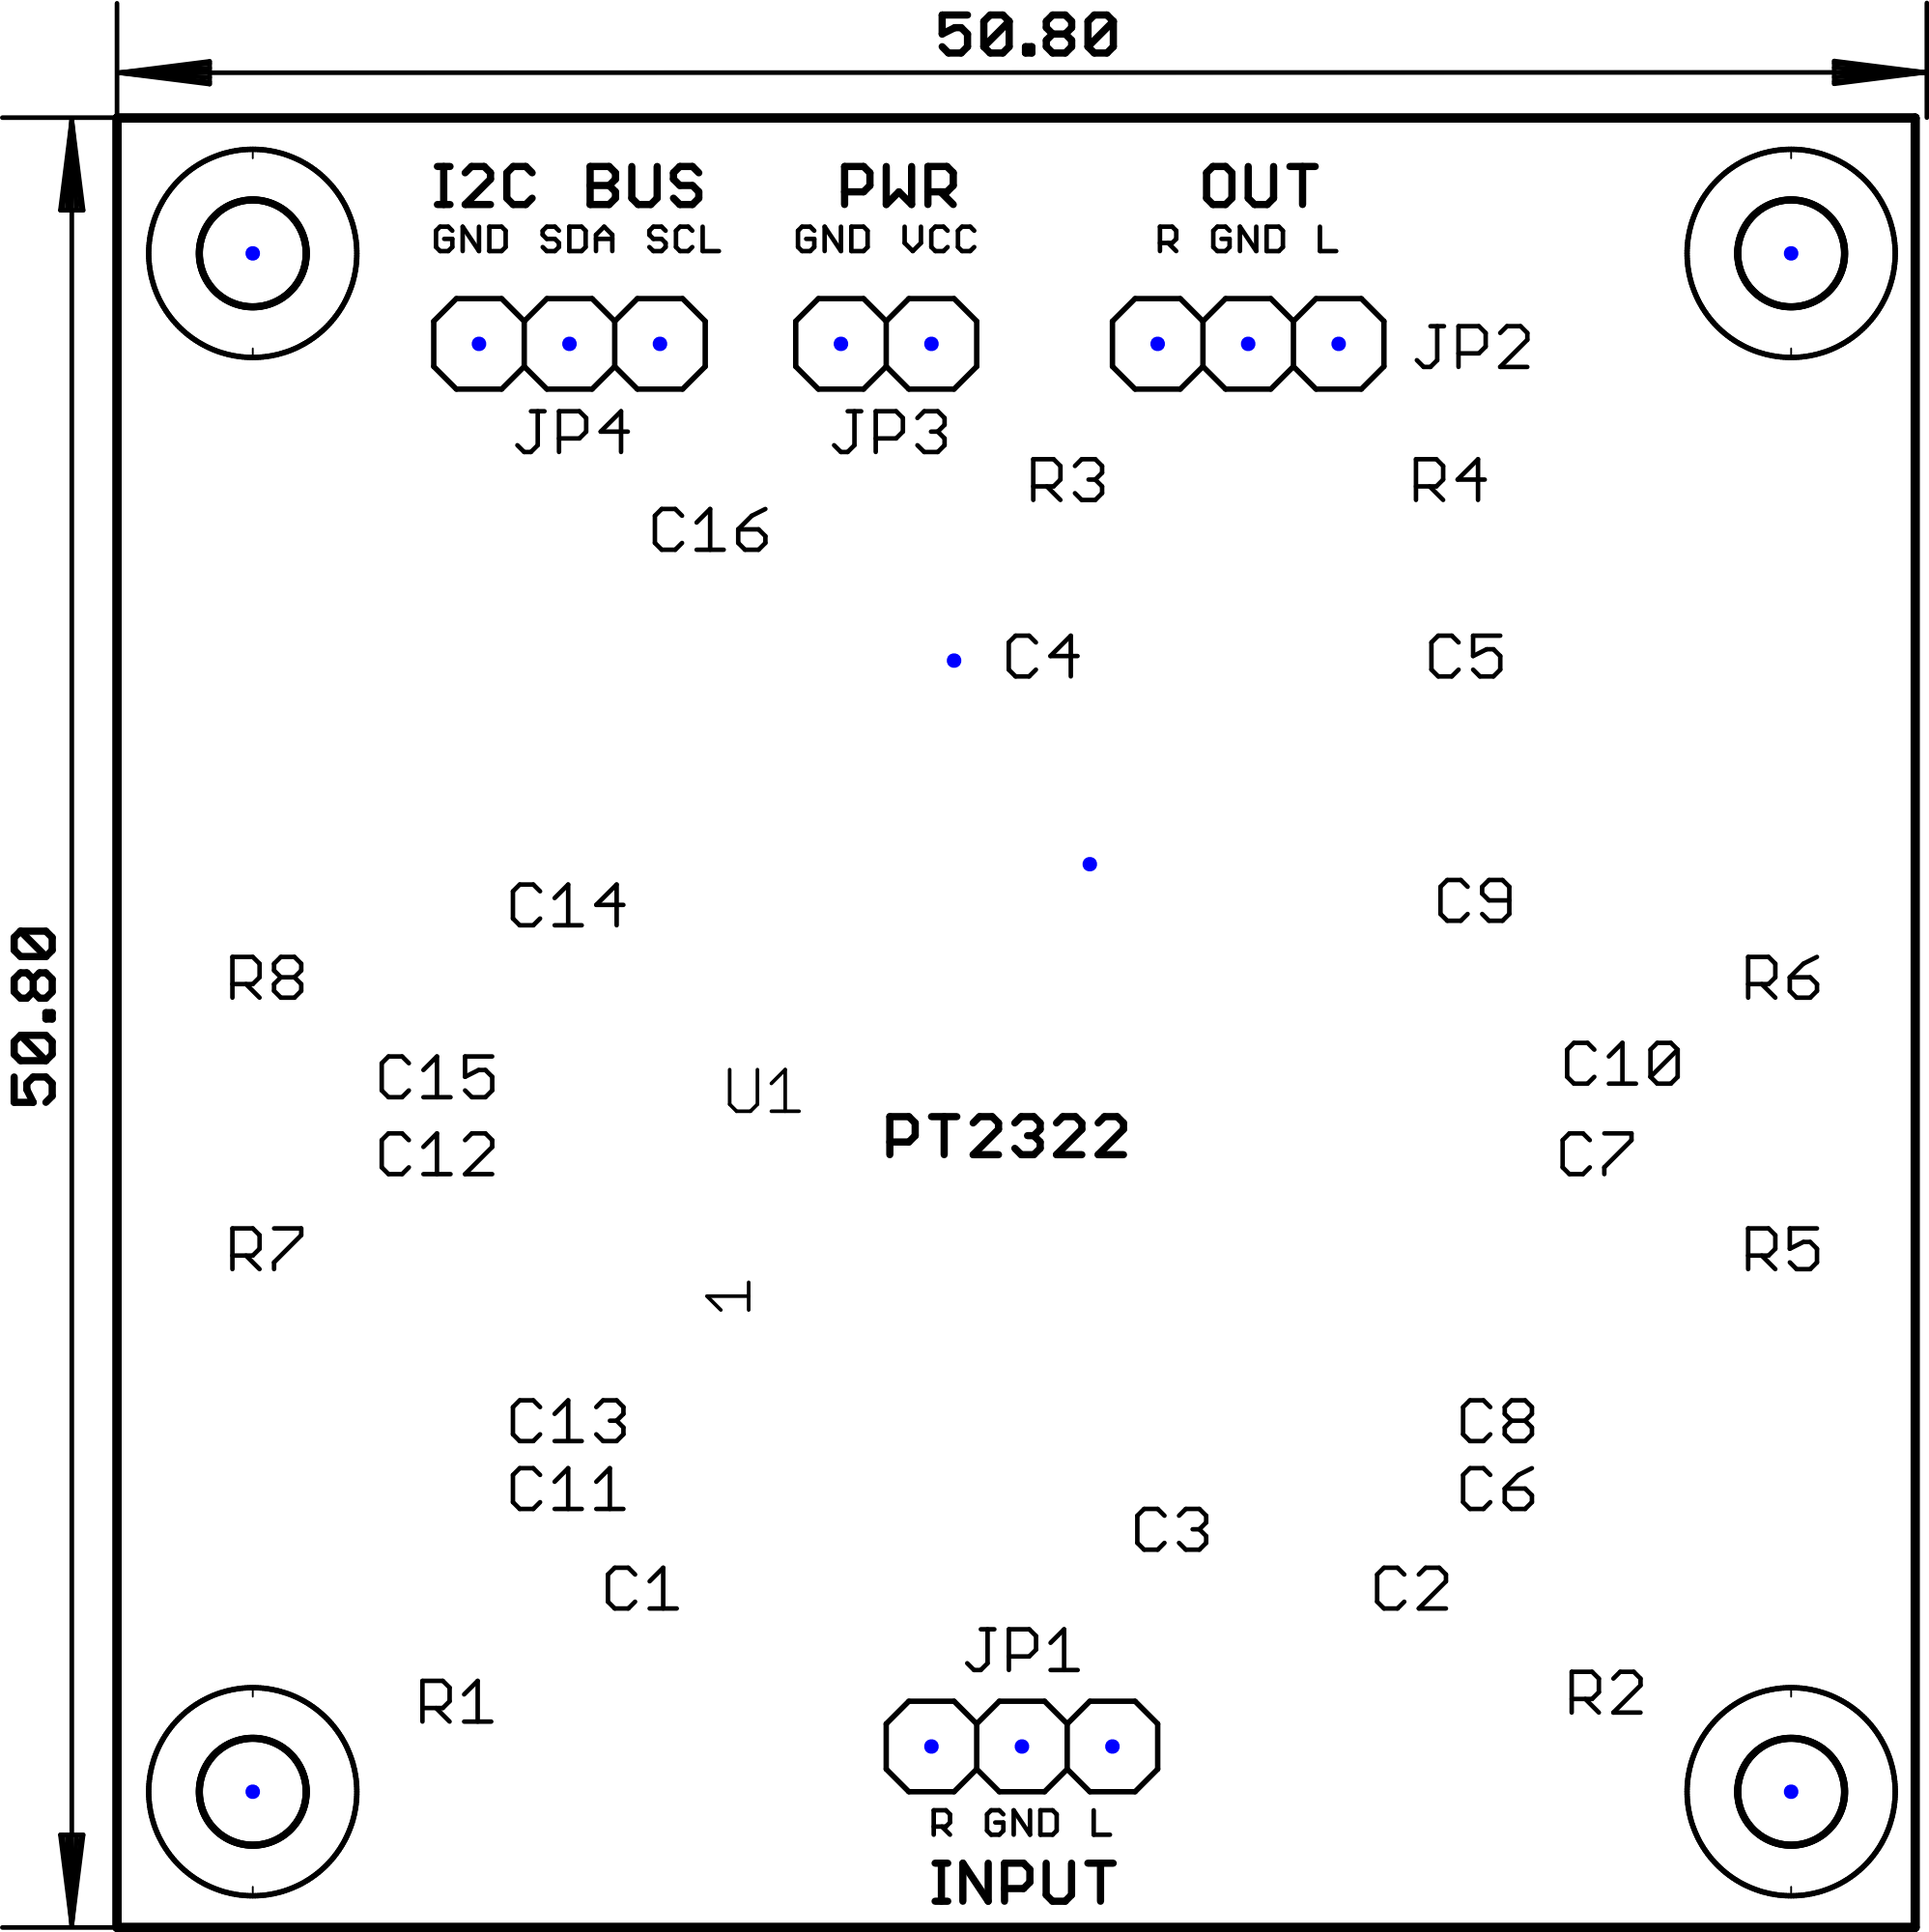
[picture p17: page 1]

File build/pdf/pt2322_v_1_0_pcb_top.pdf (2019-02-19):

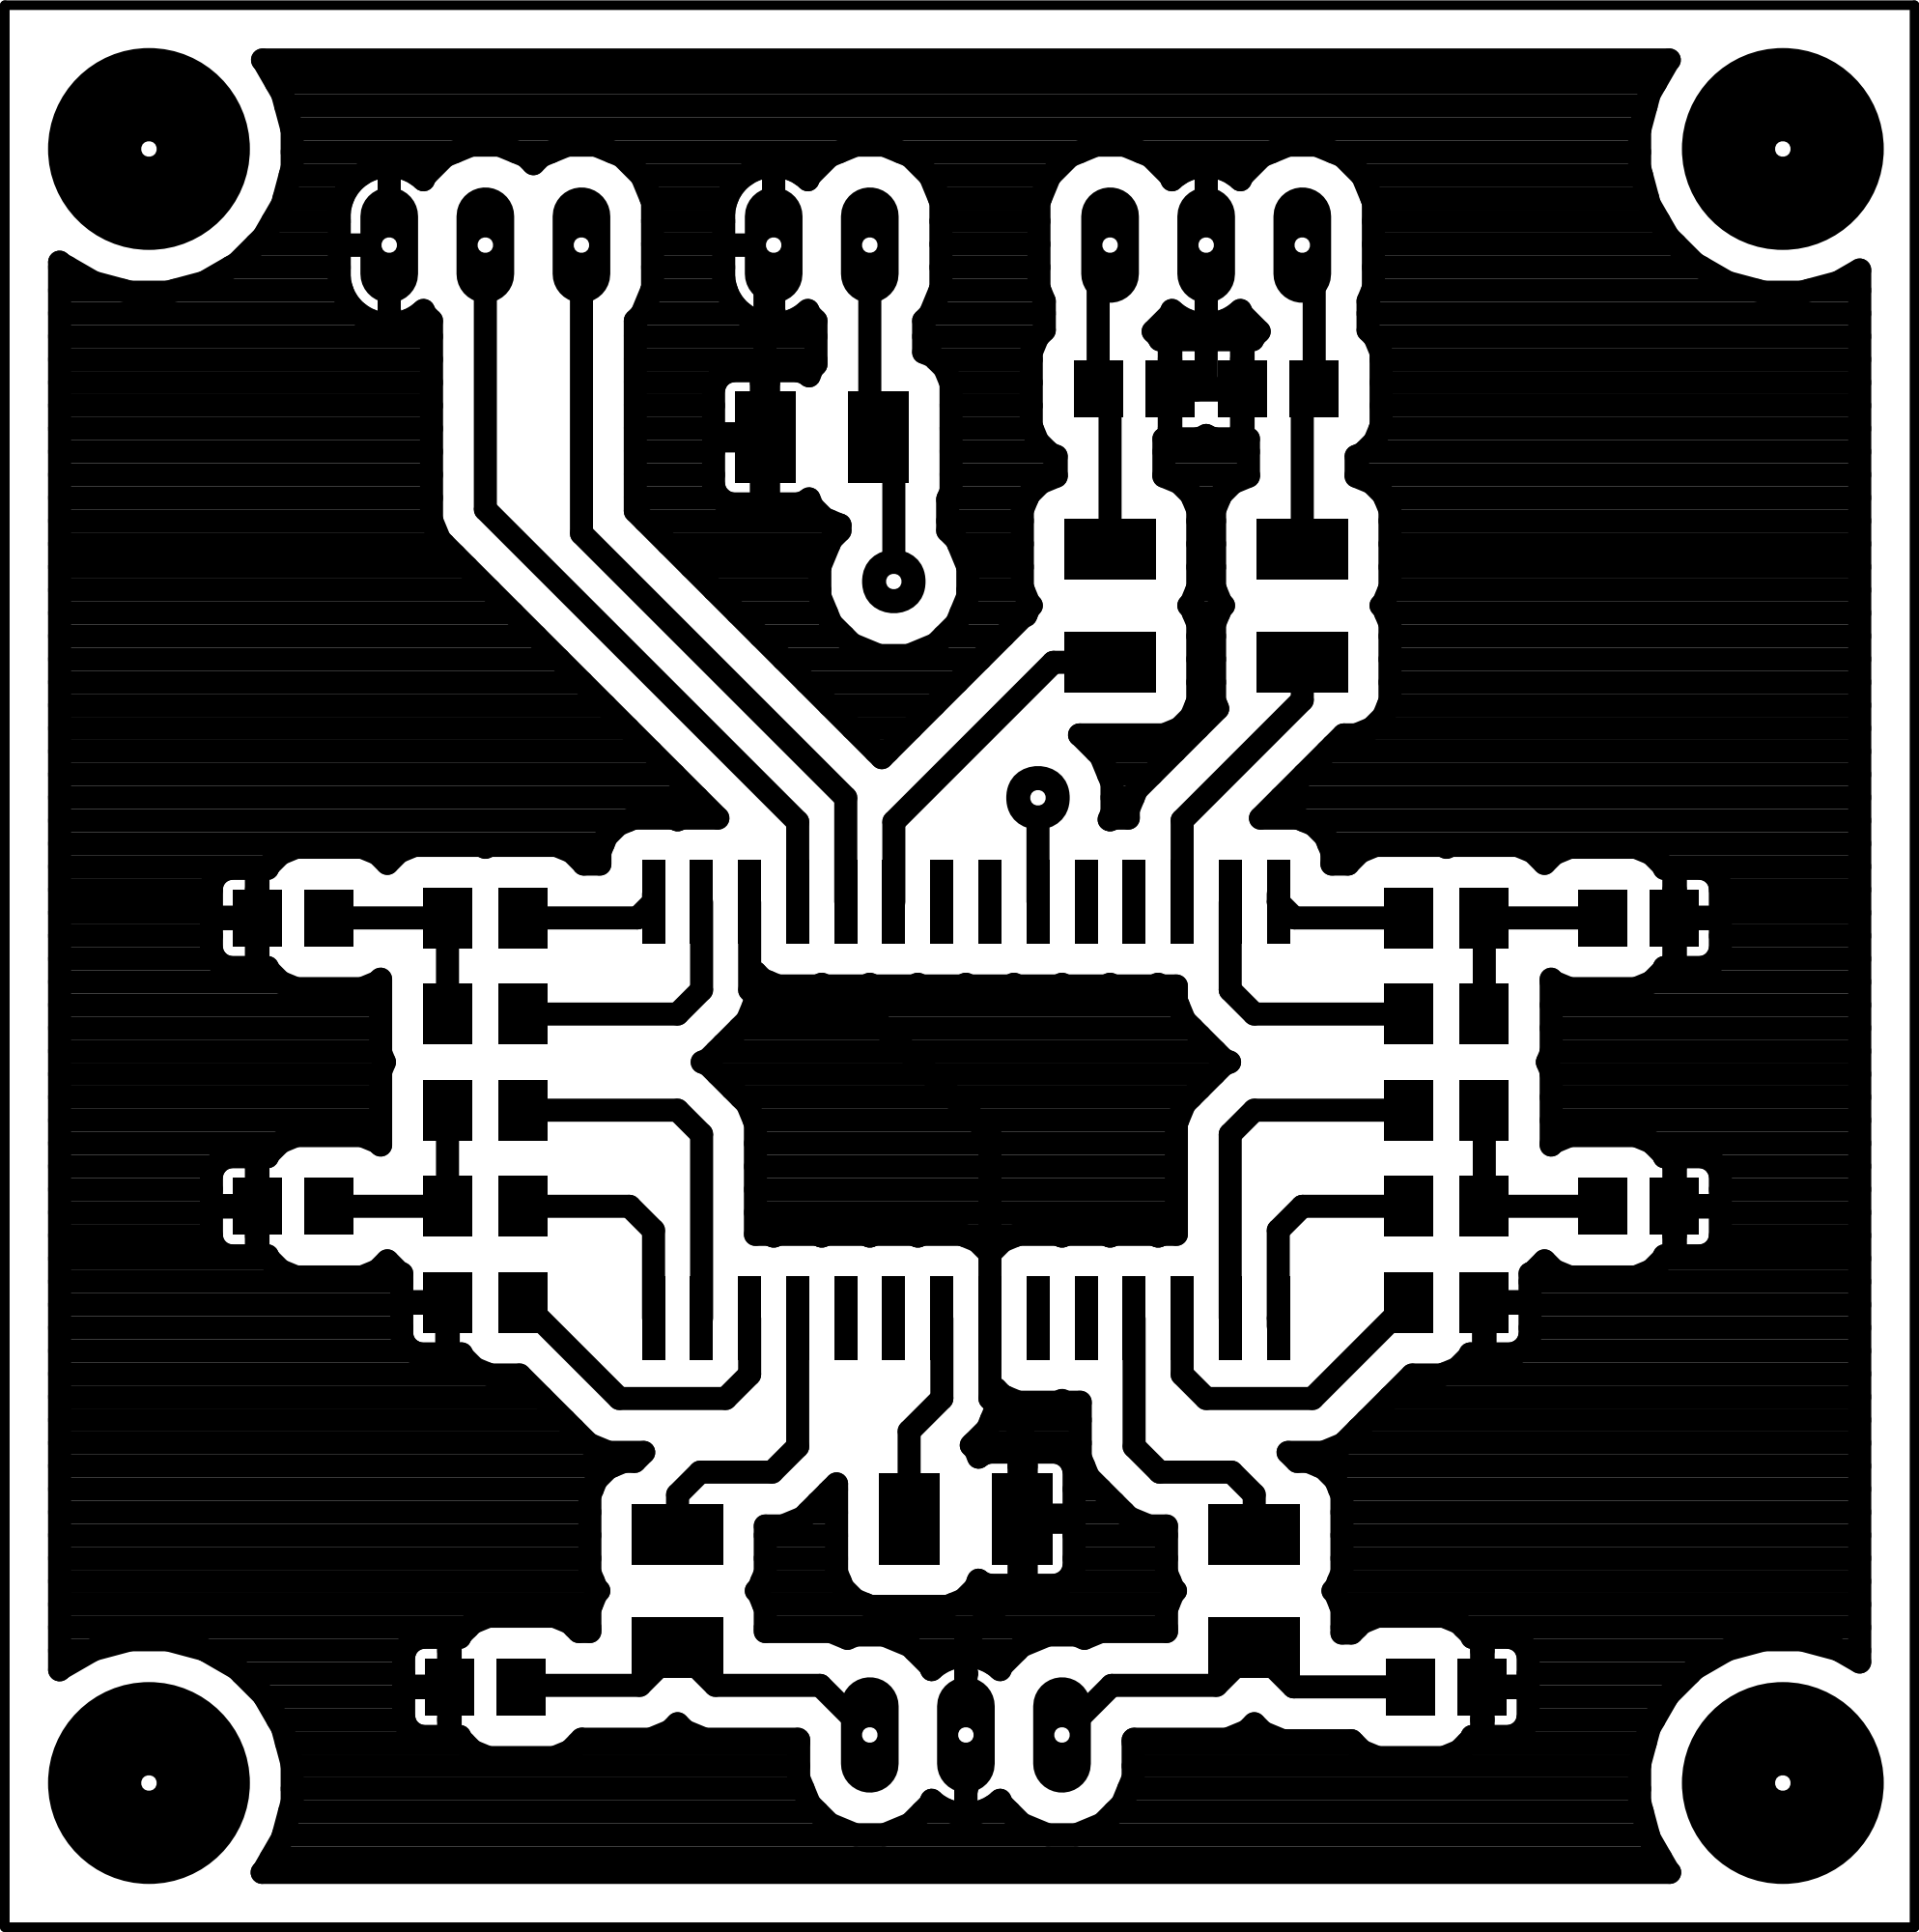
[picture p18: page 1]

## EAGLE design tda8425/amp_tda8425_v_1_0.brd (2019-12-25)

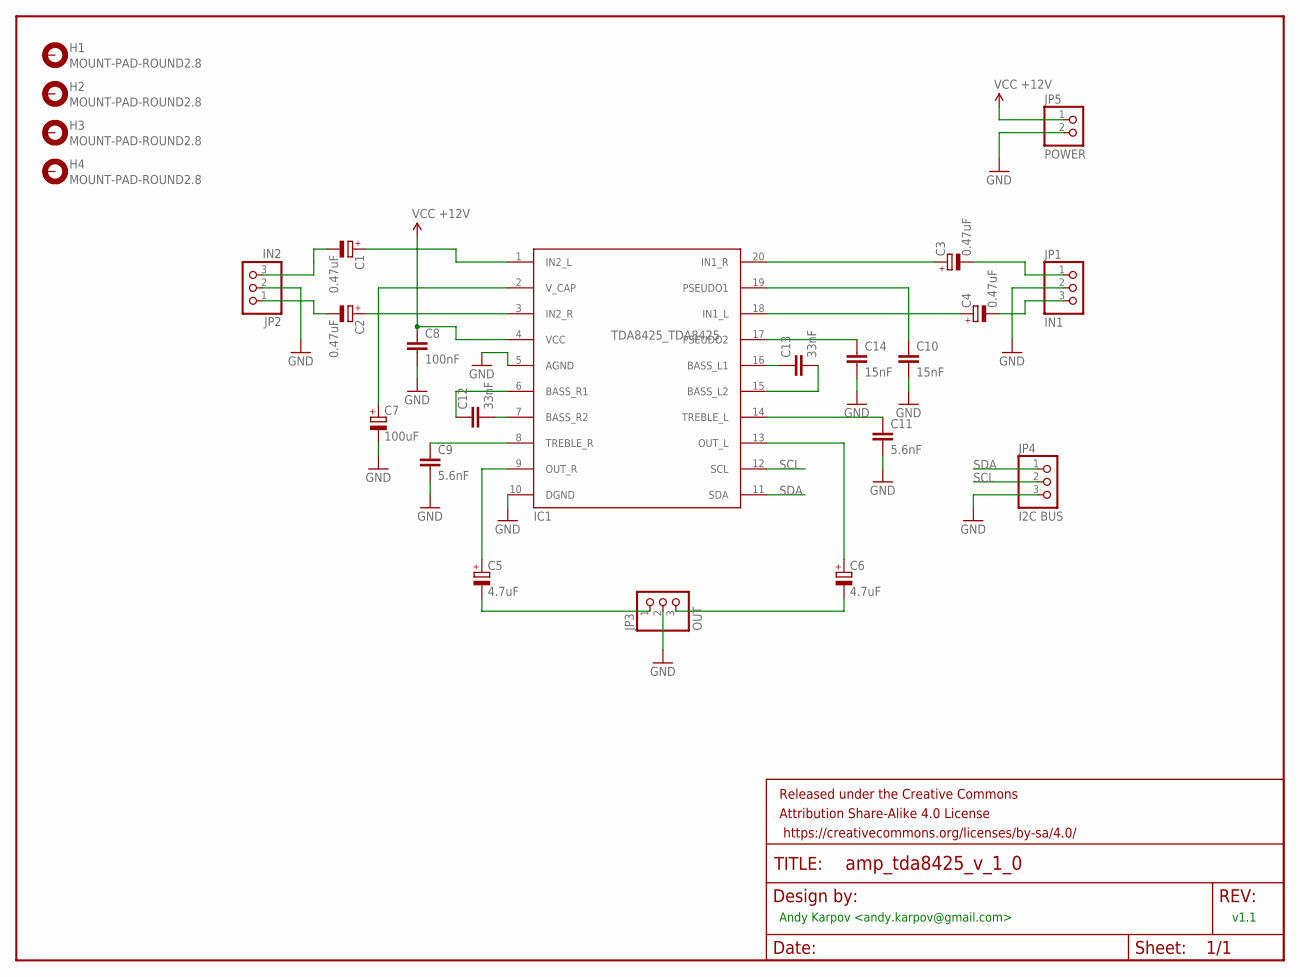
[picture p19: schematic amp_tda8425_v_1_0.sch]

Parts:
C1, C2, C3, C4: 0.47uF; E2,5-6
C5, C6: 4.7uF; E2,5-6
C7: 100uF; E2,5-6
C8: 100nF; C025-025X050
C9, C11: 5.6nF; C025-025X050
C10, C14: 15nF; C025-025X050
C12, C13: 33nF; C025-025X050
FRAME1: FRAME-LETTER; CREATIVE_COMMONS
H1, H2, H3, H4: MOUNT-PAD-ROUND2.8; 2,8-PAD
IC1: TDA8425_TDA8425; TDA8425_DIL20
JP1: IN1; 1X03
JP2: IN2; 1X03
JP3: OUT; 1X03
JP4: I2C BUS; 1X03
JP5: POWER; 1X02

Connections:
GND: C7.-, C8.2, C9.2, C10.2, C11.2, C14.2, IC1.5 (AGND), IC1.10 (DGND), JP1.2, JP2.2, JP3.2, JP4.3, JP5.2
unnamed: C1.+, IC1.1 (IN2_L)
unnamed: C1.-, JP2.3
unnamed: C2.+, IC1.3 (IN2_R)
unnamed: C2.-, JP2.1
unnamed: C3.+, IC1.20 (IN1_R)
unnamed: C4.+, IC1.18 (IN1_L)
unnamed: C3.-, JP1.1
unnamed: C4.-, JP1.3
unnamed: C7.+, IC1.2 (V_CAP)
unnamed: C12.1, IC1.6 (BASS_R1)
unnamed: C12.2, IC1.7 (BASS_R2)
unnamed: C9.1, IC1.8 (TREBLE_R)
unnamed: C5.+, IC1.9 (OUT_R)
unnamed: C5.-, JP3.1
unnamed: C6.+, IC1.13 (OUT_L)
unnamed: C6.-, JP3.3
unnamed: C13.1, IC1.16 (BASS_L1)
unnamed: C13.2, IC1.15 (BASS_L2)
unnamed: C14.1, IC1.17 (PSEUDO2)
unnamed: C11.1, IC1.14 (TREBLE_L)
unnamed: C10.1, IC1.19 (PSEUDO1)
SCL: IC1.12 (SCL), JP4.2
SDA: IC1.11 (SDA), JP4.1
VCC: C8.1, IC1.4 (VCC), JP5.1

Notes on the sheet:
Andy Karpov <andy.karpov@gmail.com>
v1.1

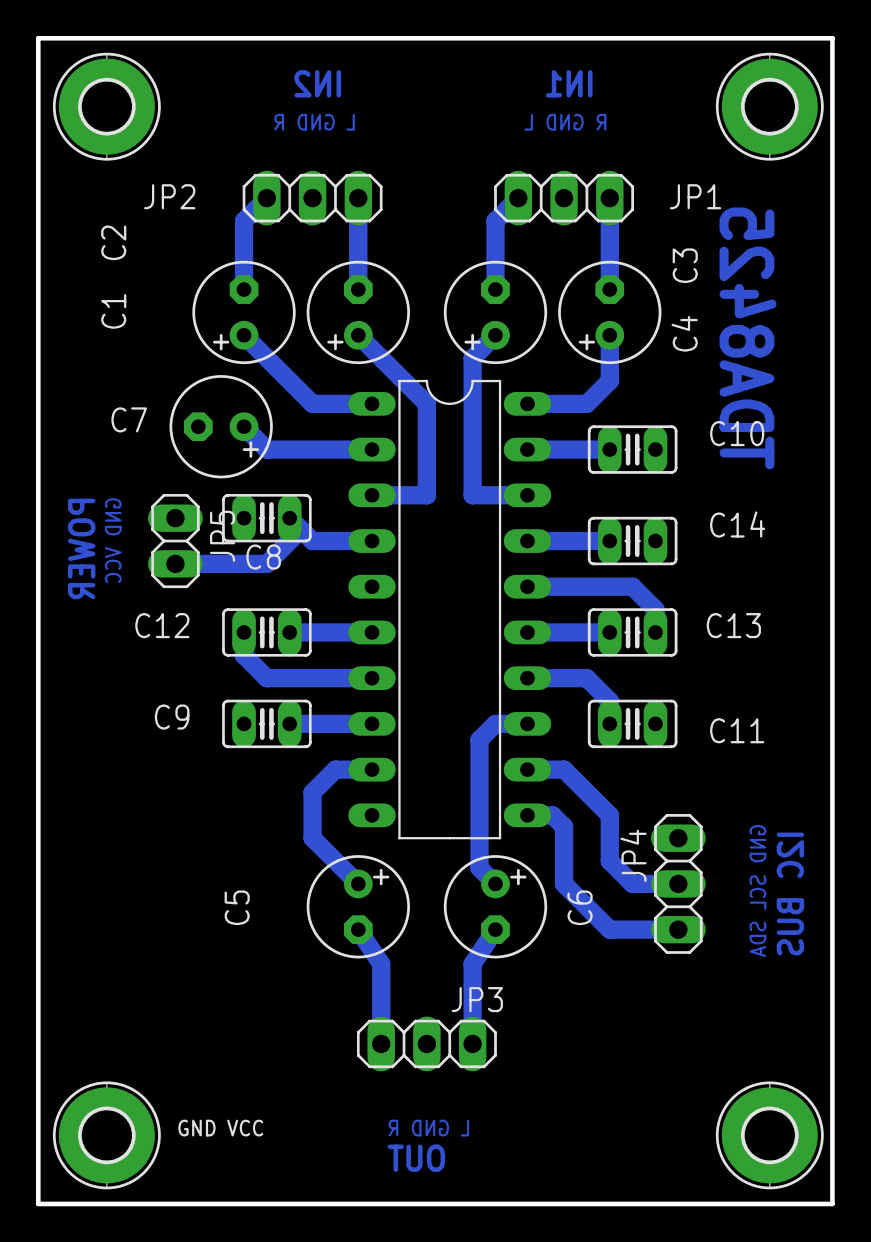
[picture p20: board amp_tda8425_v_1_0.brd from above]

Board: 2 copper layers, 44.1 x 64.8 mm, 25 parts (0 on the bottom side), 25 nets.

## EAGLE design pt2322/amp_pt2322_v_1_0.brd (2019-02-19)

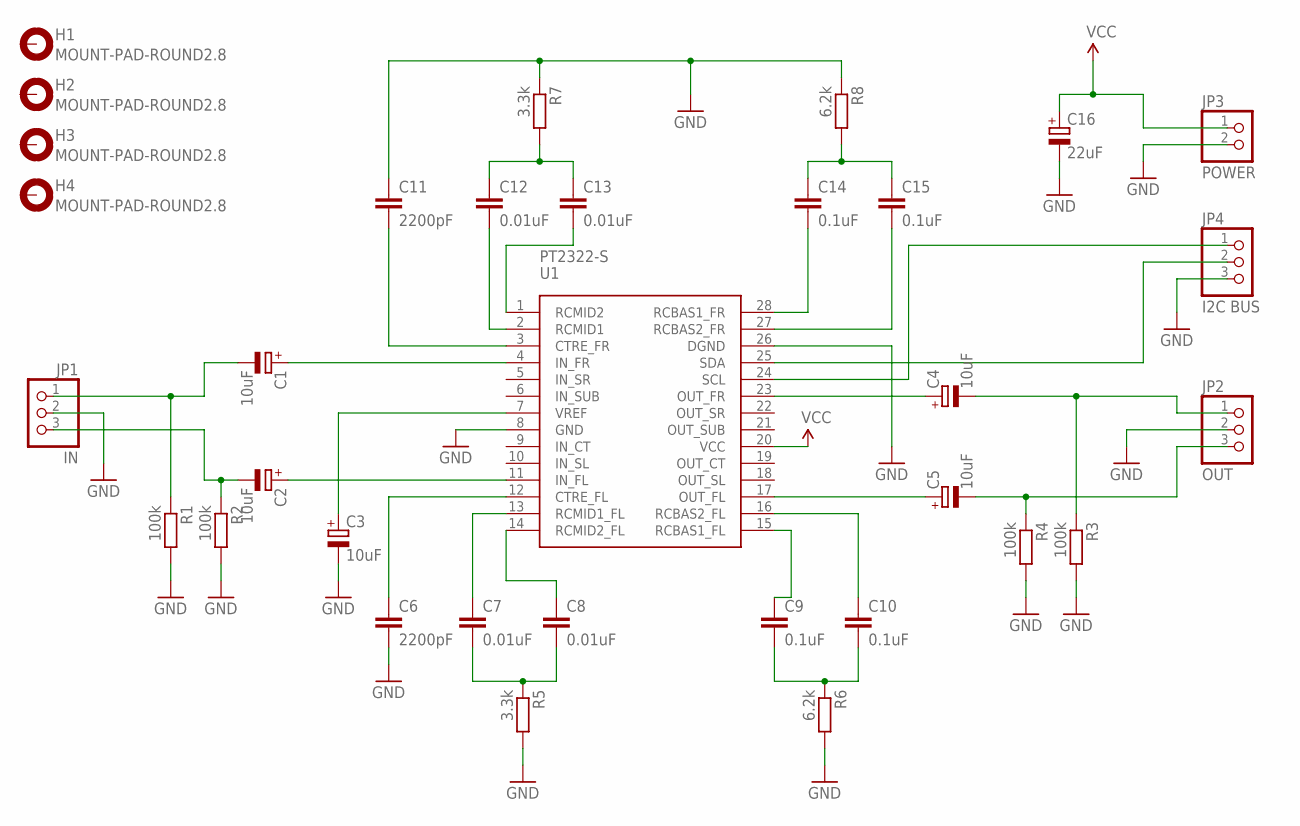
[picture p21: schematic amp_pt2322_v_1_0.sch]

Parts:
C1, C2, C3, C4, C5: 10uF; SMC_B
C6, C11: 2200pF; C0805K
C7, C8, C12, C13: 0.01uF; C0805K
C9, C10, C14, C15: 0.1uF; C0805K
C16: 22uF; SMC_B
H1, H2, H3, H4: MOUNT-PAD-ROUND2.8; 2,8-PAD
JP1: IN; 1X03
JP2: OUT; 1X03
JP3: POWER; 1X02
JP4: I2C BUS; 1X03
R1, R2, R3, R4: 100k; R0805
R5, R7: 3.3k; R0805
R6, R8: 6.2k; R0805
U1: PT2322-S; SOP28

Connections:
GND: C3.-, C6.2, C11.1, C16.-, JP1.2, JP2.2, JP3.2, JP4.3, R1.2, R2.2, R3.2, R4.2, R5.2, R6.2, R7.1, R8.1, U1.8 (GND), U1.26 (DGND)
unnamed: C1.+, U1.4 (IN_FR)
unnamed: C2.+, U1.11 (IN_FL)
unnamed: C1.-, JP1.1, R1.1
unnamed: C2.-, JP1.3, R2.1
unnamed: C3.+, U1.7 (VREF)
unnamed: C6.1, U1.12 (CTRE_FL)
unnamed: C7.1, U1.13 (RCMID1_FL)
unnamed: C8.1, U1.14 (RCMID2_FL)
unnamed: C7.2, C8.2, R5.1
unnamed: C10.1, U1.16 (RCBAS2_FL)
unnamed: C9.1, U1.15 (RCBAS1_FL)
unnamed: C9.2, C10.2, R6.1
unnamed: C13.2, U1.1 (RCMID2)
unnamed: C12.2, U1.2 (RCMID1)
unnamed: C11.2, U1.3 (CTRE_FR)
unnamed: C12.1, C13.1, R7.2
unnamed: C14.2, U1.28 (RCBAS1_FR)
unnamed: C15.2, U1.27 (RCBAS2_FR)
unnamed: C14.1, C15.1, R8.2
unnamed: C4.+, U1.23 (OUT_FR)
unnamed: C5.+, U1.17 (OUT_FL)
unnamed: C4.-, JP2.1, R3.1
unnamed: C5.-, JP2.3, R4.1
unnamed: JP4.1, U1.24 (SCL)
unnamed: JP4.2, U1.25 (SDA)
VCC: C16.+, JP3.1, U1.20 (VCC)

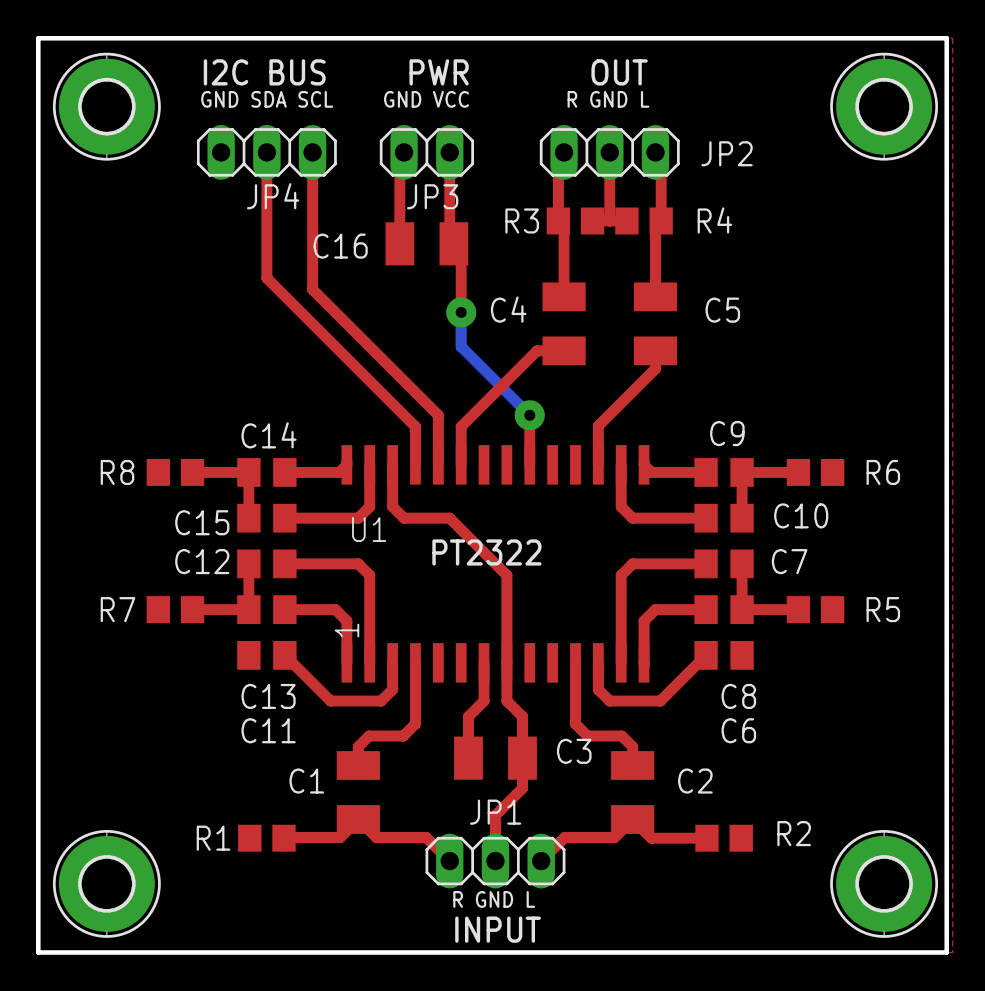
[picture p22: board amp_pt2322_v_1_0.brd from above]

Board: 2 copper layers, 50.5 x 50.8 mm, 33 parts (0 on the bottom side), 27 nets.

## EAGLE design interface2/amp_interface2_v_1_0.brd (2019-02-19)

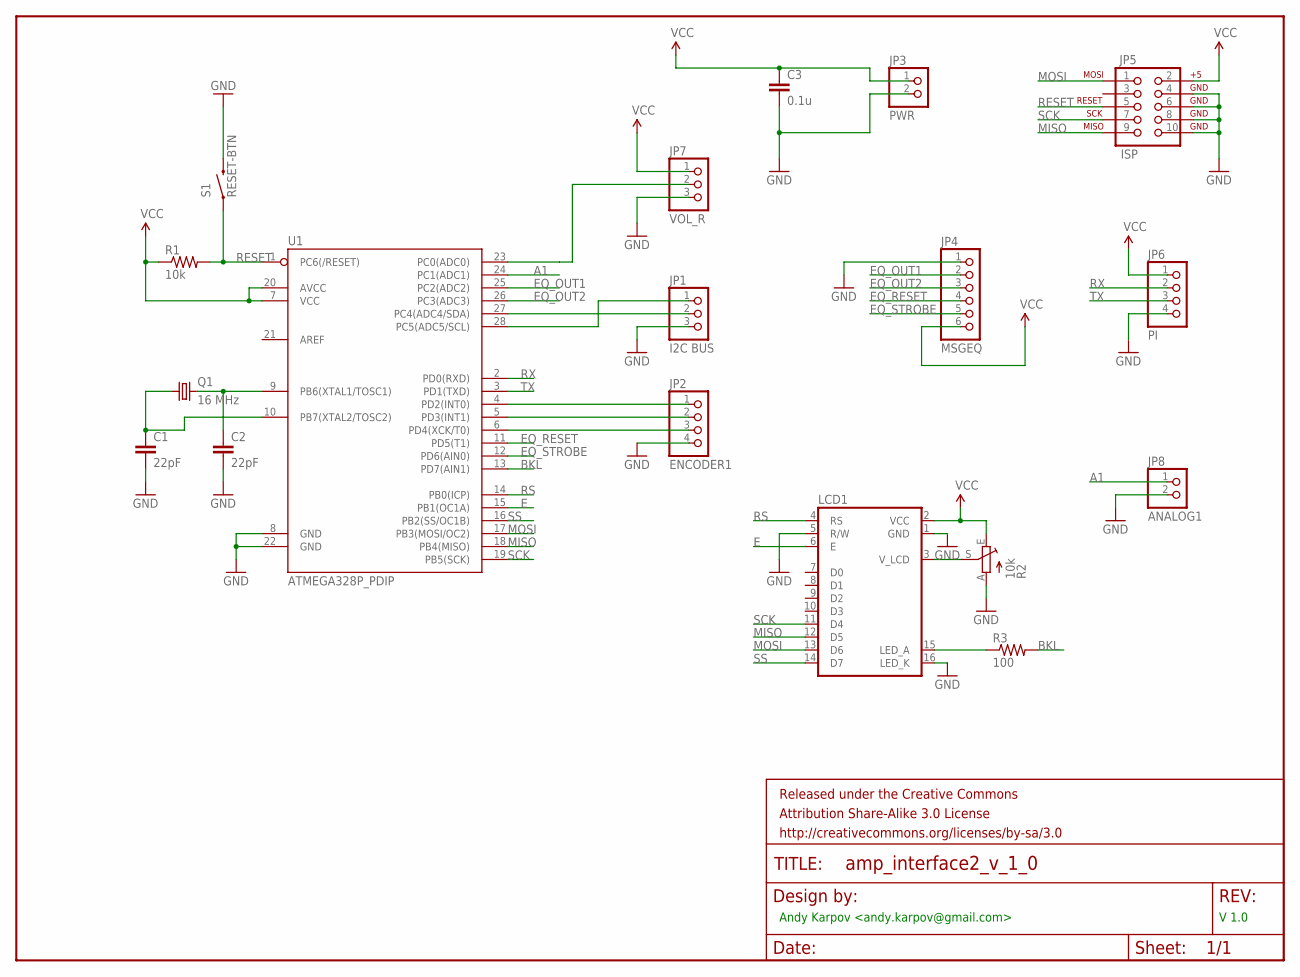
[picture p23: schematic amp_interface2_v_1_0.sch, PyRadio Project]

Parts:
C1, C2: 22pF; CAP-PTH-SMALL2
C3: 0.1u; CAP-PTH-SMALL2
FRAME1: FRAME-LETTER; CREATIVE_COMMONS
JP1: I2C BUS; 1X03
JP2: ENCODER1; 1X04
JP3: PWR; 1X02
JP4: MSGEQ; 1X06
JP5: ISP; 2X5-SHROUDED
JP6: PI; 1X04
JP7: VOL_R; 1X03
JP8: ANALOG1; 1X02
LCD1: LCD-4X20
Q1: 16 MHz; HC49/S
R1: 10k; AXIAL-0.4
R2: 10k; B64Y
R3: 100; AXIAL-0.5
S1: RESET-BTN; TACTILE-PTH
U1: ATMEGA328P_PDIP; DIL28-3

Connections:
A1: JP8.1, U1.24 (PC1(ADC1))
BKL: R3.P$2 (2), U1.13 (PD7(AIN1))
E: LCD1.6 (E), U1.15 (PB1(OC1A))
EQ_OUT1: JP4.2, U1.25 (PC2(ADC2))
EQ_OUT2: JP4.3, U1.26 (PC3(ADC3))
EQ_RESET: JP4.4, U1.11 (PD5(T1))
EQ_STROBE: JP4.5, U1.12 (PD6(AIN0))
GND: C1.2, C2.2, C3.2, JP1.3, JP2.4, JP3.2, JP4.1, JP5.4, JP5.6, JP5.8, JP5.10, JP6.4, JP7.3, JP8.2, LCD1.1 (GND), LCD1.5 (R/W), LCD1.16 (LED_K), R2.A, S1.3 (2), U1.8 (GND), U1.22 (GND)
MISO: JP5.9, LCD1.12 (D5), U1.18 (PB4(MISO))
MOSI: JP5.1, LCD1.13 (D6), U1.17 (PB3(MOSI/OC2))
unnamed: C2.1, Q1.2, U1.9 (PB6(XTAL1/TOSC1))
unnamed: C1.1, Q1.1, U1.10 (PB7(XTAL2/TOSC2))
unnamed: LCD1.3 (V_LCD), R2.S
unnamed: JP1.2, U1.27 (PC4(ADC4/SDA))
unnamed: JP1.1, U1.28 (PC5(ADC5/SCL))
unnamed: LCD1.15 (LED_A), R3.P$1 (1)
unnamed: JP2.3, U1.6 (PD4(XCK/T0))
unnamed: JP2.1, U1.4 (PD2(INT0))
unnamed: JP2.2, U1.5 (PD3(INT1))
PC0: JP7.2, U1.23 (PC0(ADC0))
RESET: JP5.5, R1.P$2 (2), S1.1, U1.1 (PC6(/RESET))
RS: LCD1.4 (RS), U1.14 (PB0(ICP))
RX: JP6.2, U1.2 (PD0(RXD))
SCK: JP5.7, LCD1.11 (D4), U1.19 (PB5(SCK))
SS: LCD1.14 (D7), U1.16 (PB2(SS/OC1B))
TX: JP6.3, U1.3 (PD1(TXD))
VCC: C3.1, JP3.1, JP4.6, JP5.2, JP6.1, JP7.1, LCD1.2 (VCC), R1.P$1 (1), R2.E, U1.7 (VCC), U1.20 (AVCC)

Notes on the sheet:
Andy Karpov <andy.karpov@gmail.com>
V 1.0

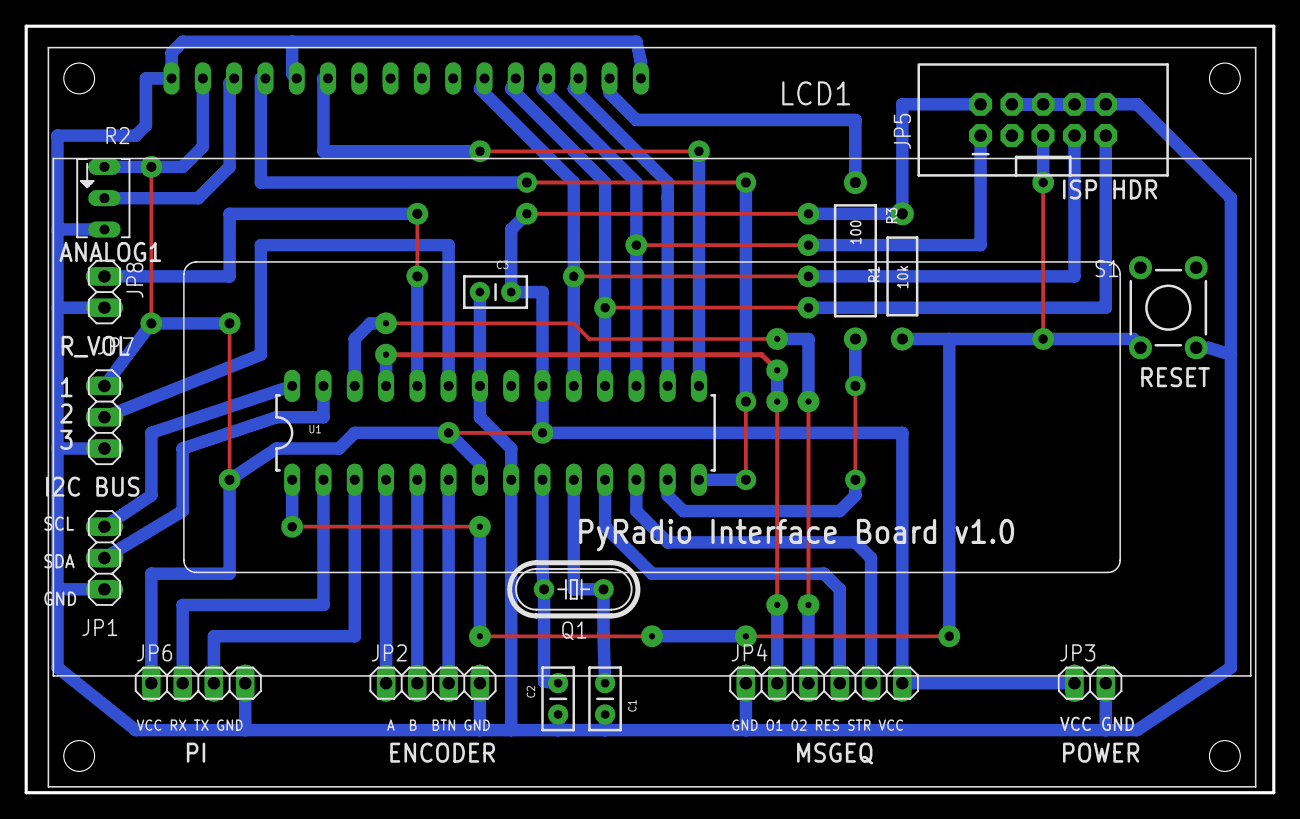
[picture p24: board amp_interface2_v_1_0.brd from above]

Board: 2 copper layers, 101.3 x 62.2 mm, 19 parts (0 on the bottom side), 27 nets.

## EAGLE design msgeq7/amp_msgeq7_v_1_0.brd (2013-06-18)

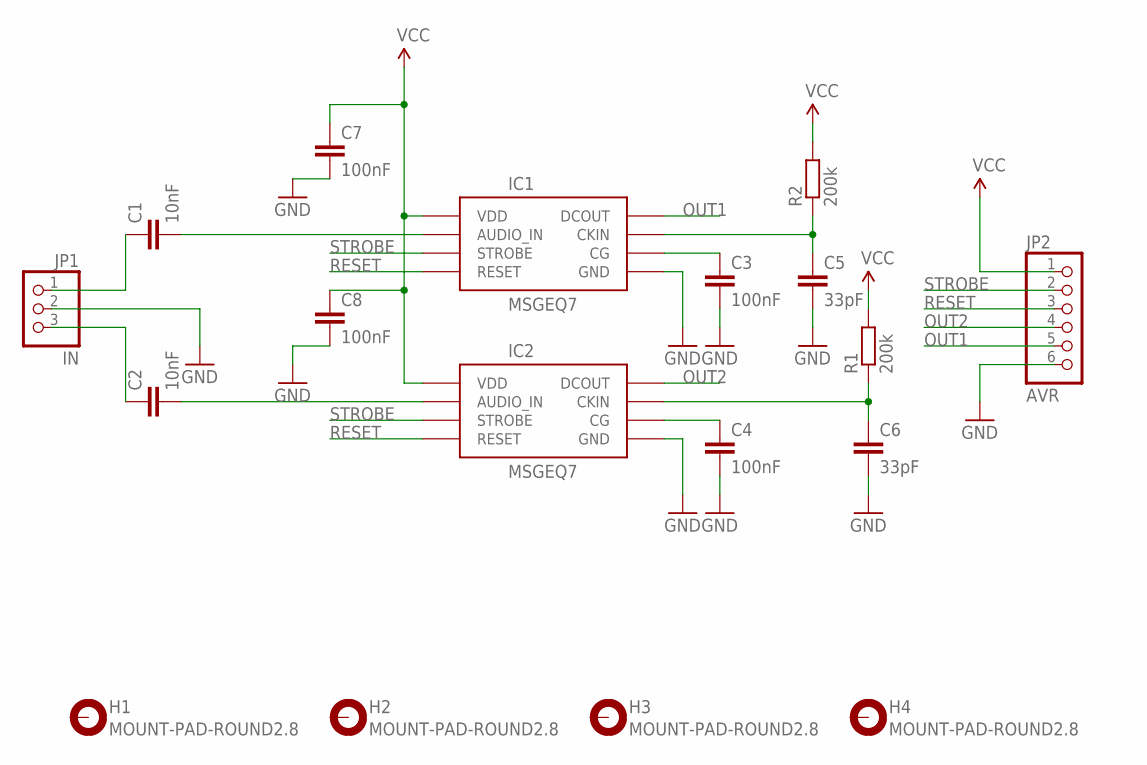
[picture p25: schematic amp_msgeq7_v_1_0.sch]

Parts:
C1, C2: 10nF; C025-030X050
C3, C4: 100nF; C025-030X050
C5, C6: 33pF; C025-030X050
C7, C8: 100nF; C025-025X050
H1, H2, H3, H4: MOUNT-PAD-ROUND2.8; 2,8-PAD
IC1, IC2: MSGEQ7DIP; DIL08
JP1: IN; 1X03
JP2: AVR; 1X06
R1, R2: 200k; 0204/7

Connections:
GND: C3.2, C4.2, C5.2, C6.2, C7.2, C8.2, IC1.2 (GND), IC2.2 (GND), JP1.2, JP2.6
unnamed: C1.1, JP1.1
unnamed: C1.2, IC1.5 (AUDIO_IN)
unnamed: C2.1, JP1.3
unnamed: C2.2, IC2.5 (AUDIO_IN)
unnamed: C3.1, IC1.6 (CG)
unnamed: C4.1, IC2.6 (CG)
unnamed: C5.1, IC1.8 (CKIN), R2.1
unnamed: C6.1, IC2.8 (CKIN), R1.1
OUT1: IC1.3 (DCOUT), JP2.5
OUT2: IC2.3 (DCOUT), JP2.4
RESET: IC1.7 (RESET), IC2.7 (RESET), JP2.3
STROBE: IC1.4 (STROBE), IC2.4 (STROBE), JP2.2
VCC: C7.1, C8.1, IC1.1 (VDD), IC2.1 (VDD), JP2.1, R1.2, R2.2

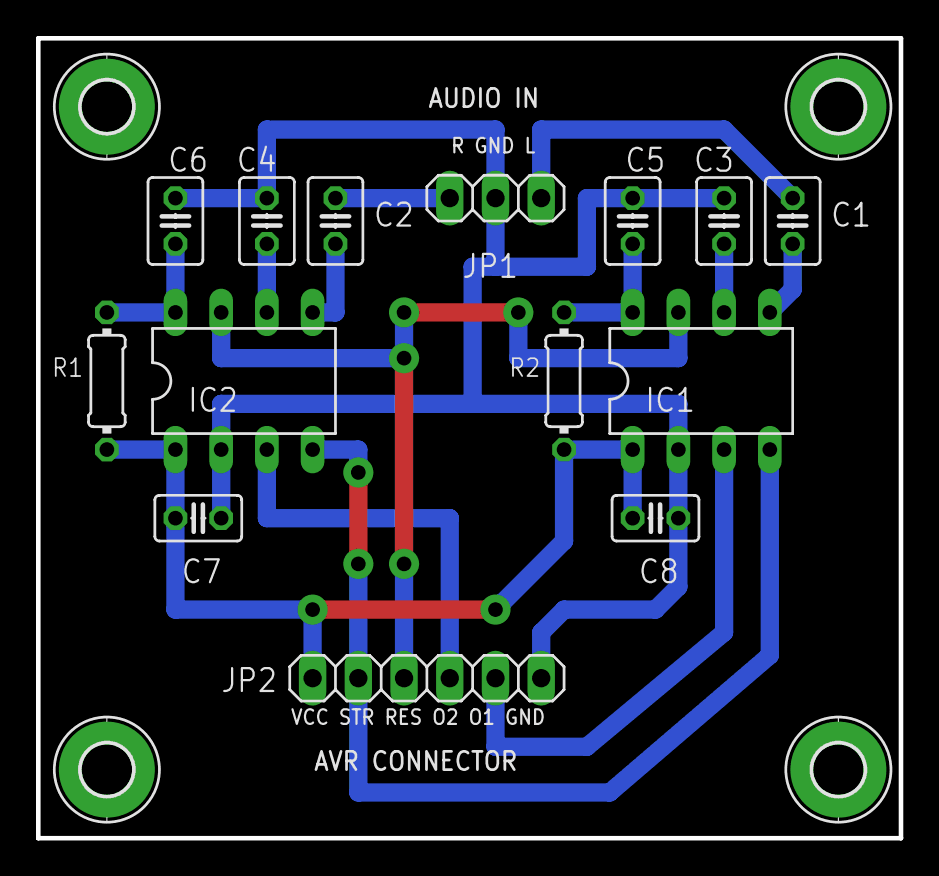
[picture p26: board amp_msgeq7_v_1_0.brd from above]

Board: 2 copper layers, 47.9 x 44.4 mm, 18 parts (0 on the bottom side), 14 nets.

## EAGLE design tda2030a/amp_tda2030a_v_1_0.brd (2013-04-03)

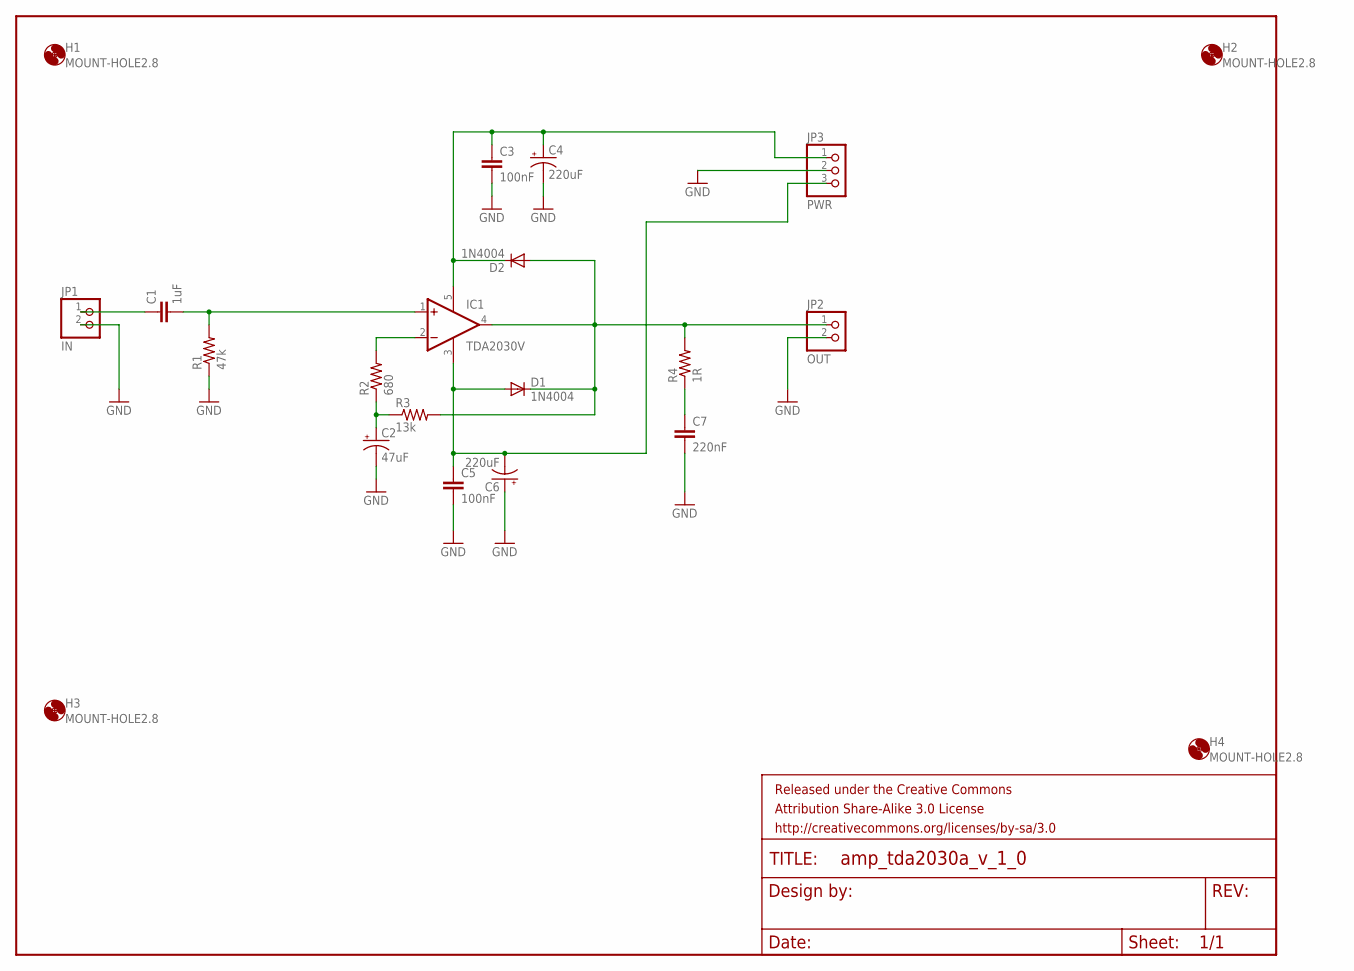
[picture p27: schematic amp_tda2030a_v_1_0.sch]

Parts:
C1: 1uF; CAP-PTH-LARGE
C2: 47uF; CPOL-RADIAL-100UF-25V
C3, C5: 100nF; CAP-PTH-5MM
C4, C6: 220uF; CPOL-RADIAL-100UF-25V
C7: 220nF; CAP-PTH-LARGE
D1, D2: 1N4004; DO41-10
FRAME1: FRAME-LETTER; CREATIVE_COMMONS
H1, H2, H3, H4: MOUNT-HOLE2.8; 2,8
IC1: TDA2030V; CB360
JP1: IN; 1X02
JP2: OUT; 1X02
JP3: PWR; 1X03
R1: 47k; AXIAL-0.4
R2: 680; AXIAL-0.4
R3: 13k; AXIAL-0.4
R4: 1R; AXIAL-0.4

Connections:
GND: C2.2 (-), C3.2, C4.2 (-), C5.2, C6.1 (+), C7.2, JP1.2, JP2.2, JP3.2, R1.P$1 (1)
unnamed: C1.1, JP1.1
unnamed: C1.2, IC1.1 (+IN), R1.P$2 (2)
unnamed: IC1.2 (-IN), R2.P$2 (2)
unnamed: C2.1 (+), R2.P$1 (1), R3.P$1 (1)
unnamed: C5.1, C6.2 (-), D1.A, IC1.3 (GND), JP3.3
unnamed: D1.C, D2.A, IC1.4 (OUT), JP2.1, R3.P$2 (2), R4.P$2 (2)
unnamed: C7.1, R4.P$1 (1)
unnamed: C3.1, C4.1 (+), D2.C, IC1.5 (V+), JP3.1

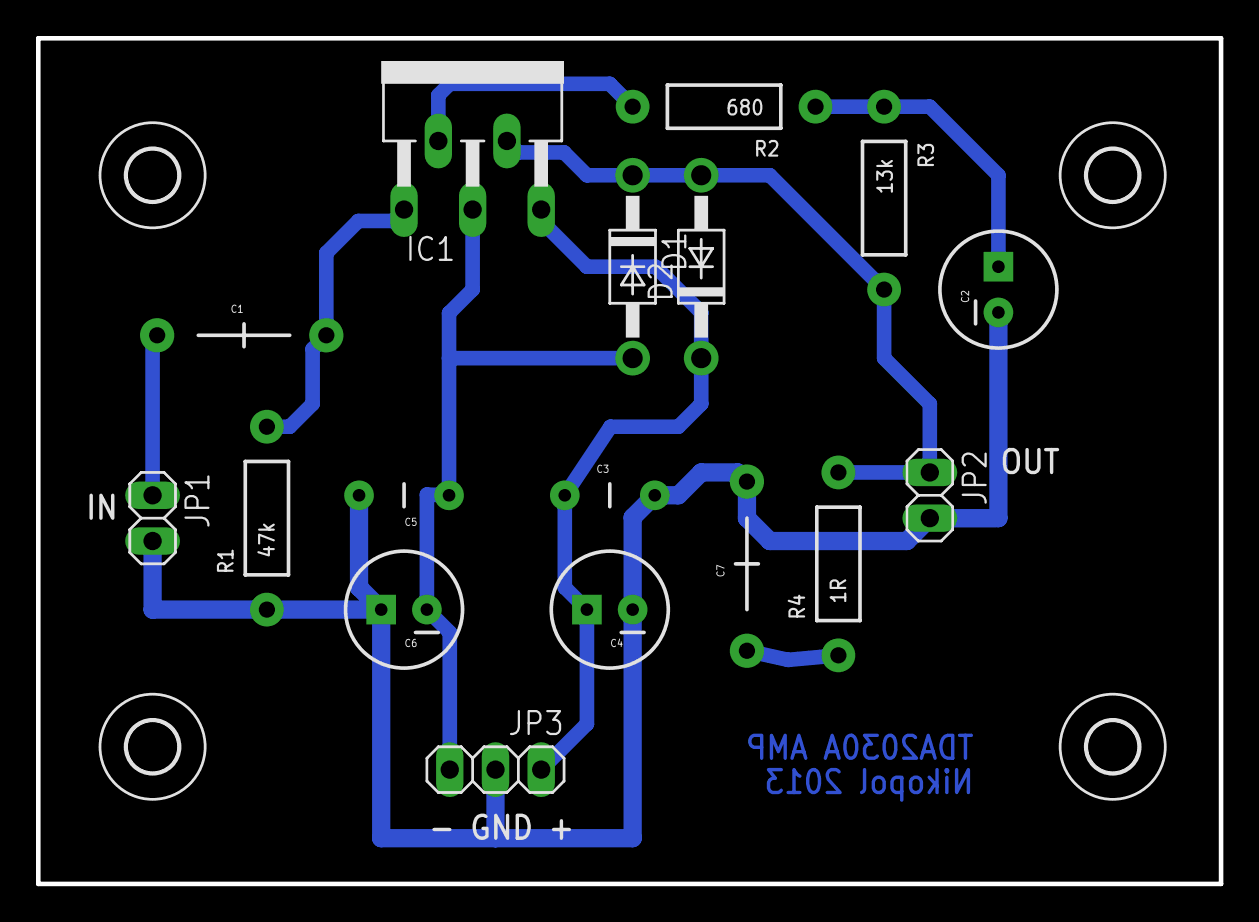
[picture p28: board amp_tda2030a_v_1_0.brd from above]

Board: 2 copper layers, 65.7 x 47.0 mm, 22 parts (0 on the bottom side), 9 nets.

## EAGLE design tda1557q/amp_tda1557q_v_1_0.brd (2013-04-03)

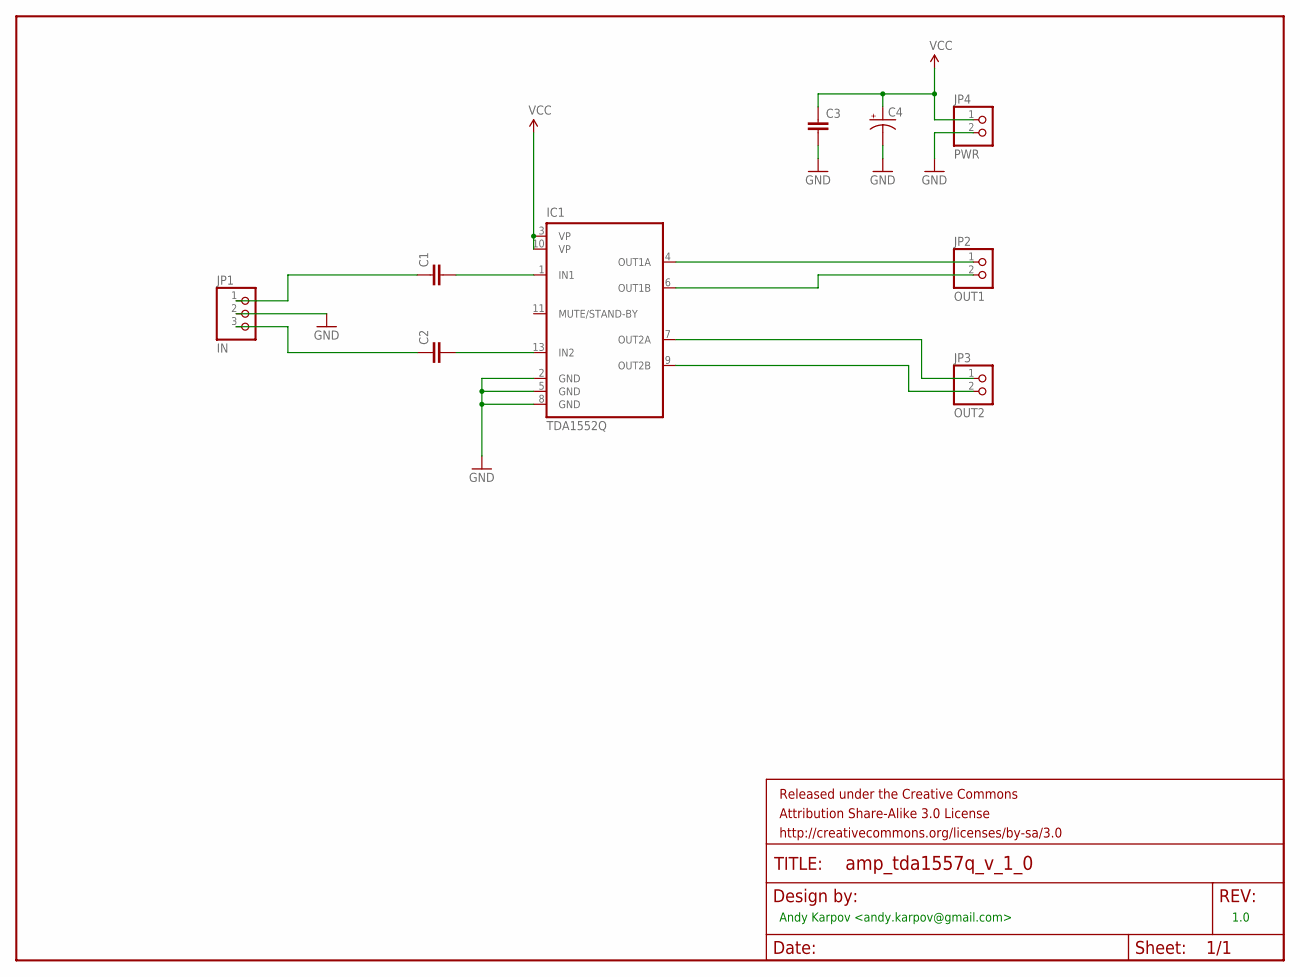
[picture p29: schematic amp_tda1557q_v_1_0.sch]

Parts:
C1, C2, C3: CAPPTH3; CAP-PTH-LARGE
C4: CAP_POLPTH3; CPOL-RADIAL-1000UF-63V
FRAME1: FRAME-LETTER; CREATIVE_COMMONS
IC1: TDA1552Q; MULTIWAT-SIL13
JP1: IN; 1X03
JP2: OUT1; 1X02
JP3: OUT2; 1X02
JP4: PWR; 1X02

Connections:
GND: C3.2, C4.2 (-), IC1.2 (GND), IC1.5 (GND), IC1.8 (GND), JP1.2, JP4.2
unnamed: C1.1, JP1.1
unnamed: C1.2, IC1.1 (IN1)
unnamed: C2.1, JP1.3
unnamed: C2.2, IC1.13 (IN2)
unnamed: IC1.4 (OUT1A), JP2.1
unnamed: IC1.6 (OUT1B), JP2.2
unnamed: IC1.7 (OUT2A), JP3.1
unnamed: IC1.9 (OUT2B), JP3.2
VCC: C3.1, C4.1 (+), IC1.3 (VP), IC1.10 (VP), JP4.1

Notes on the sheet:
Andy Karpov <andy.karpov@gmail.com>
1.0

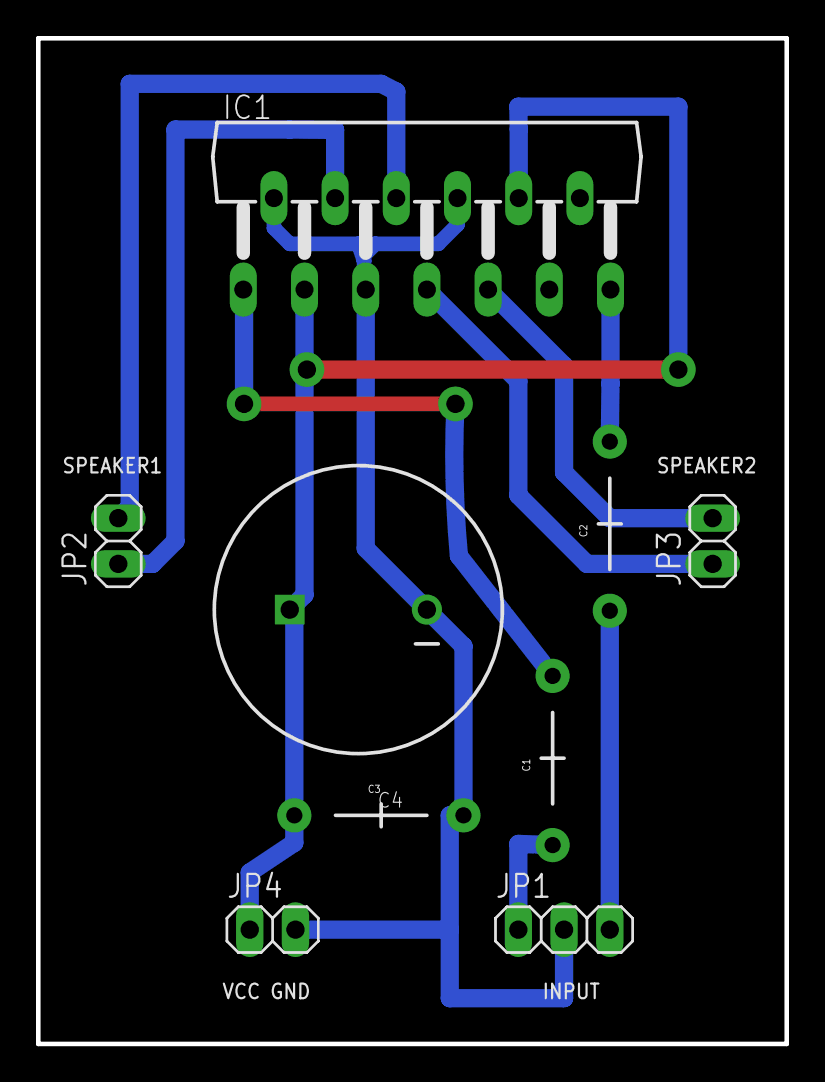
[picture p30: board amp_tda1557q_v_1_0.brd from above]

Board: 2 copper layers, 41.6 x 55.9 mm, 10 parts (0 on the bottom side), 10 nets.

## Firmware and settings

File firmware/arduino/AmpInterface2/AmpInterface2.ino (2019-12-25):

/*
   Moby AMP interface 2.53

   Arduino based front-end using 20x4 LCD, encoder, 5 push buttons, 2x MSGEQ7 ics,
   PT2322 audio processor, PCF8574 with additional signals for input multiplexer and relay switches,
   HT16k33 led matrix to drive 4 digit 7 segment display, etc.

   @author Andrey Karpov <andy.karpov@gmail.com>
   @copyright 2013, 2019 Andrey Karpov
*/

#include <LiquidCrystal.h>
#include <NewEncoder.h>
#include <Button.h>
#include <Led.h>
#include <EEPROM.h>
#include <Wire.h>
#include <PT2322.h>
#include <jm_PCF8574.h>
#include <Adafruit_GFX.h>
#include "Adafruit_LEDBackpack.h"

const uint8_t ROWS = 4; // number of display rows
const uint8_t COLS = 20; // number of display columns

const uint8_t ENC_INCREMENT = 5; // encoder increment
#define ENC_PINA 2
#define ENC_PINB 3
#define ENC_TYPE FULL_PULSE

#define MSGEQ_STROBE 6 // В6
#define MSGEQ_RESET 5 // D5
#define MSGEQ_OUT_L 2 // A2
#define MSGEQ_OUT_R 3 // A3

#define PIN_RELAY1 0 // D0
#define PIN_RELAY2 1 // D1

const unsigned long BOOT_DELAY = 5000; // ms

#define PT2322_MIN_VOLUME -79 // dB
#define PT2322_MAX_VOLUME 0 // dB
#define PT2322_MIN_TONE -14 // db
#define PT2322_MAX_TONE 14 // db

#define NUM_MODES 9 // number of app modes

#define EEPROM_ADDRESS_OFFSET 400 // address offset to start reading/wring to the EEPROM 

const int DELAY_MODE = 400; // mode switch debounce delay
const unsigned long DELAY_EEPROM = 10000; // delay to store to the EEPROM
const unsigned long DELAY_EQ_MODE = 5000; // delay for autoswitch to eq mode

#define PCF_I2C_ADR1 0x20 // 0x20 is the default address for the PCF8574 with all three input pins tied to ground.
#define PCF_I2C_ADR2 0x38 // 0x38 is the default address for the PCF8574A with all three input pins tied to ground.

#define PCF2_I2C_ADR1 0x22 // 0x22 is the address for the PCF8574 with A0=0, A1=1, A2=0
#define PCF2_I2C_ADR2 0x3A // 0x3A is the address for the PCF8574A with A0=0, A1=1, A2=0

#define PCF_I2C_P7  ((uint8_t) 0b10000000)  // P7
#define PCF_I2C_P6  ((uint8_t) 0b01000000)  // P6
#define PCF_I2C_P5  ((uint8_t) 0b00100000)  // P5
#define PCF_I2C_P4  ((uint8_t) 0b00010000)  // P4
#define PCF_I2C_P3  ((uint8_t) 0b00001000)  // P3
#define PCF_I2C_P2  ((uint8_t) 0b00000100)  // P2
#define PCF_I2C_P1  ((uint8_t) 0b00000010)  // P1
#define PCF_I2C_P0  ((uint8_t) 0b00000001)  // P0

#define MATRIX_ADR 0x70 // ht16k33 address
#define MATRIX_BRIGHTNESS 0 // 0 ... 15

PT2322 audio; // PT2322 board connected to i2c bus (GND, A4, A5)
LiquidCrystal lcd(8, 9, 13, 12, 11, 10); // lcd connected to D8, D9, D13, D12, D11, D10 pins
NewEncoder enc(ENC_PINA, ENC_PINB, 0, 100, 0, ENC_TYPE, ENC_INCREMENT);

Button btn(4); // mode button
Led backlight(7); // LCD backlight connected to GND and D7

jm_PCF8574 pcf8574; // I2C port extender (switches, relays)
jm_PCF8574 pcf8574c; // I2C port extender (7-segment channel code)
Adafruit_7segment matrix = Adafruit_7segment(); // 4 digits 7 segment led display, common cathode, connected via HT16K33

int eq_L[7] = {0, 0, 0, 0, 0, 0, 0}; // 7-band equalizer values for left channel
int eq_R[7] = {0, 0, 0, 0, 0, 0, 0}; // 7-band equalizer values for right channel

// enum with application states
enum app_mode_e {
  mode_volume = 0,
  mode_balance, // first in the loop of mode switch
  mode_bass,
  mode_middle,
  mode_treble,
  mode_brightness, // last in the looop of mode switch
  mode_channel,
  mode_passthru,
  mode_mono,
  mode_mute
};

// enum with keyboard buttons
enum app_buttons_e {
  btn_none = 0,
  btn_mute,
  btn_ch_prev,
  btn_ch_next,
  btn_menu_prev,
  btn_menu_next,
  btn_mono_selector,
  btn_eq_selector
};

int values[NUM_MODES];
int prev_values[NUM_MODES];

bool now_mute = false;
bool prev_mute = false;

int current_mode;
int prev_mode;
int prev_encoder_value;
bool power_done = false;
bool need_store = false;
bool eq_mode = false;
bool info_mode = false;
int char_loaded = 0;
bool current_mode_is_tones = false;
bool current_mode_is_switches = false;

unsigned long last_key_pressed = 0;
unsigned long last_btn_pressed = 0;
unsigned long last_changed = 0;

// custom LCD characters (volume bars)
byte p1[8] = { 0b10000, 0b10000, 0b10000, 0b10100, 0b10100, 0b10000, 0b10000, 0b10000 };
byte p2[8] = { 0b10100, 0b10100, 0b10100, 0b10100, 0b10100, 0b10100, 0b10100, 0b10100 };
byte p3[8] = { 0b10101, 0b10101, 0b10101, 0b10101, 0b10101, 0b10101, 0b10101, 0b10101 };
byte p4[8] = { 0b00101, 0b00101, 0b00101, 0b00101, 0b00101, 0b00101, 0b00101, 0b00101 };
byte p5[8] = { 0b00001, 0b00001, 0b00001, 0b00101, 0b00101, 0b00001, 0b00001, 0b00001 };
byte p6[8] = { 0b00000, 0b00000, 0b00000, 0b00100, 0b00100, 0b00000, 0b00000, 0b00000 };
byte p7[8] = { 0b00000, 0b00001, 0b00011, 0b00111, 0b00111, 0b00011, 0b00001, 0b00000 };
byte p8[8] = { 0b00000, 0b10000, 0b11000, 0b11100, 0b11100, 0b11000, 0b10000, 0b00000 };

// custom LCD characters (eq bars)
byte e1[8] = { 0b00000, 0b00000, 0b00000, 0b00000, 0b00000, 0b00000, 0b11111, 0b11111 };
byte e2[8] = { 0b00000, 0b00000, 0b00000, 0b11111, 0b11111, 0b00000, 0b11111, 0b11111 };
byte e3[8] = { 0b11111, 0b11111, 0b00000, 0b11111, 0b11111, 0b00000, 0b11111, 0b11111 };
byte e4[8] = { 0b00000, 0b00000, 0b00000, 0b00000, 0b00000, 0b00000, 0b00000, 0b00000 };

// custom LCD characters (channels)
byte c1[8] = { 0b00000, 0b00000, 0b00000, 0b00000, 0b00000, 0b00000, 0b00000, 0b11111 };
byte c2[8] = { 0b00000, 0b00000, 0b00000, 0b01110, 0b01110, 0b01110, 0b00000, 0b11111 };

/**
   Load custom LCD characters for volume control
*/
void loadVolumeCharacters() {
  char_loaded = 1;
  lcd.clear();
  lcd.createChar(1, p1);
  lcd.createChar(2, p2);
  lcd.createChar(3, p3);
  lcd.createChar(4, p4);
  lcd.createChar(5, p5);
  lcd.createChar(6, p6);
  lcd.createChar(7, p7);
  lcd.createChar(8, p8);
  lcd.clear();
}

/**
   Load custom LCD characters for graphical equalizer bars
*/
void loadEqualizerCharacters() {
  char_loaded = 2;
  lcd.clear();
  lcd.createChar(1, e1);
  lcd.createChar(2, e2);
  lcd.createChar(3, e3);
  lcd.createChar(4, e4);
  lcd.clear();
}

/**
   Load custom LCD characters for channel selector
*/
void loadChannelCharacters() {
  char_loaded = 3;
  lcd.clear();
  lcd.createChar(1, c1);
  lcd.createChar(2, c2);
  lcd.clear();
}

/**
   Arduino setup routine
*/
void setup() {

  pinMode(PIN_RELAY1, OUTPUT);
  pinMode(PIN_RELAY2, OUTPUT);

  digitalWrite(PIN_RELAY1, LOW);
  digitalWrite(PIN_RELAY2, LOW);

  Wire.begin();

  // setup lcd
  lcd.begin(COLS, ROWS);
  lcd.clear();
  loadVolumeCharacters();
  backlight.begin();
  backlight.on();

  // defaults
  for (int i = 0; i < NUM_MODES; i++) {
    values[i] = 0;
    prev_values[i] = 0;
  }

  current_mode = mode_volume;
  prev_mode = mode_volume;

  restoreValues();

  audio.init();

  // send volume and tones to the PT2322 board
  sendPT2322All(true);
  lcd.print("send");

  // try to init pcf8574 with 2 different addresses (8574 vs 8574A)
  if (!pcf8574.begin(PCF_I2C_ADR1)) {
    pcf8574.begin(PCF_I2C_ADR2);
  }

  // try to init pcf8574c with 2 different addresses (8574 vs 8574A)
  if (!pcf8574c.begin(PCF2_I2C_ADR1)) {
    pcf8574c.begin(PCF2_I2C_ADR2);
  }  

  // clear All port extender values
  pcf8574.pinMode( PCF_I2C_P0, OUTPUT );
  pcf8574.pinMode( PCF_I2C_P1, OUTPUT );
  pcf8574.pinMode( PCF_I2C_P2, OUTPUT );
  pcf8574.pinMode( PCF_I2C_P3, OUTPUT );
  pcf8574.pinMode( PCF_I2C_P4, OUTPUT );
  pcf8574.pinMode( PCF_I2C_P5, OUTPUT );
  pcf8574.pinMode( PCF_I2C_P6, OUTPUT );
  pcf8574.pinMode( PCF_I2C_P7, OUTPUT );

  pcf8574.digitalWrite( PCF_I2C_P0, LOW );
  pcf8574.digitalWrite( PCF_I2C_P1, LOW );
  pcf8574.digitalWrite( PCF_I2C_P2, LOW );
  pcf8574.digitalWrite( PCF_I2C_P3, HIGH ); // disable mux
  pcf8574.digitalWrite( PCF_I2C_P4, LOW ); // disable mono A
  pcf8574.digitalWrite( PCF_I2C_P5, LOW ); // disable mono B
  pcf8574.digitalWrite( PCF_I2C_P6, LOW ); // disable mono A+B
  pcf8574.digitalWrite( PCF_I2C_P7, LOW ); // disable EQ passthru

  // clear All port extender 2 values
  pcf8574c.pinMode( PCF_I2C_P0, OUTPUT );
  pcf8574c.pinMode( PCF_I2C_P1, OUTPUT );
  pcf8574c.pinMode( PCF_I2C_P2, OUTPUT );
  pcf8574c.pinMode( PCF_I2C_P3, OUTPUT );

  pcf8574c.digitalWrite( PCF_I2C_P0, LOW );
  pcf8574c.digitalWrite( PCF_I2C_P1, LOW );
  pcf8574c.digitalWrite( PCF_I2C_P2, LOW );
  pcf8574c.digitalWrite( PCF_I2C_P3, LOW );

  sendPcf();

  matrix.begin(MATRIX_ADR);
  sendMatrix();

  // setup MSGEQ board
  pinMode(MSGEQ_STROBE, OUTPUT);
  pinMode(MSGEQ_RESET, OUTPUT);
  analogReference(DEFAULT);
  pinMode(A2, INPUT);
  pinMode(A3, INPUT);
  pinMode(4, INPUT_PULLUP);

  pinMode(A0, INPUT_PULLUP);
  digitalWrite(A0, HIGH);

  pinMode(A1, INPUT_PULLUP);
  digitalWrite(A1, HIGH);

  if (!power_done) {
    powerUp();
    power_done = true;
  }

  enc.configure(ENC_PINA, ENC_PINB, 0, 100, values[mode_volume], ENC_TYPE, ENC_INCREMENT); // set encoder bounds
  enc.begin();
  enc.setValue(values[mode_volume]); // set encoder value

}

/**
   Main app loop
*/
void loop() {

  unsigned long current = millis();

  // encoder button switch between eq / info mode
  if (btn.pressed() && current - last_btn_pressed > DELAY_MODE) {
    last_btn_pressed = current;
    lcd.clear();
    if (eq_mode) {
      info_mode = !info_mode;
    }
  }

  // read and process buttons
  int kbd_btn = readKeyboard();
  if (kbd_btn > 0 && current - last_key_pressed > DELAY_MODE) {
    switch (kbd_btn) {
      case btn_mute:
        now_mute = !now_mute;
        last_key_pressed = current;
        break;
      case btn_ch_prev:
        last_key_pressed = current;
        //if (current_mode != mode_channel) {
          current_mode = mode_channel;
        //} else {
          values[mode_channel]--;
          if (values[mode_channel] < 0) values[mode_channel] = 7;
        //}
      break;
      case btn_ch_next:
        last_key_pressed = current;
        //if (current_mode != mode_channel) {
          current_mode = mode_channel;
        //} else {
          values[mode_channel]++;
          if (values[mode_channel] > 7) values[mode_channel] = 0;
        //}
      break;
      case btn_menu_prev:
        if (current_mode > mode_balance && current_mode <= mode_brightness) {
          current_mode--;
        } else {
          current_mode = mode_brightness;
        }
        last_key_pressed = current;
      break;
      case btn_menu_next:
        if (current_mode >= mode_balance && current_mode < mode_brightness) {
          current_mode++;
        } else {
          current_mode = mode_balance;
        }
        last_key_pressed = current;
      break;
      case btn_mono_selector:
        last_key_pressed = current;
        if (current_mode != mode_mono) {      
          current_mode = mode_mono;
        } else {
          values[mode_mono]++;
          if (values[mode_mono] > 4) values[mode_mono] = 0;
        }
      break;
      case btn_eq_selector:
        last_key_pressed = current;
        if (current_mode != mode_passthru) {
          current_mode = mode_passthru;
        } else {
          values[mode_passthru]++;
          if (values[mode_passthru] > 1) values[mode_passthru] = 0;
        }
      break;
    }
  }

  // flags
  current_mode_is_tones = (current_mode == mode_volume || current_mode == mode_balance || current_mode == mode_bass || current_mode == mode_treble || current_mode == mode_middle || current_mode == mode_brightness) ? true : false;
  current_mode_is_switches = (current_mode == mode_channel || current_mode == mode_passthru || current_mode == mode_mono) ? true : false;

  // if mode changed -> clear lcd and set encoder value
  if (prev_mode != current_mode) {
    lcd.clear();
    prev_mode = current_mode;

    if (current_mode_is_tones) {
        enc.setValue(values[current_mode]);
    } else if (current_mode_is_switches) {
        enc.setValue(values[mode_volume]);
    }
  }

  // read encoder
  if (current_mode_is_tones) {
    values[current_mode] = readEncoder();
  } else if (current_mode_is_switches) {
    values[mode_volume] = readEncoder();
  }

  // store settings in EEPROM with 10s delay to reduce number of write cycles
  if (need_store && current - last_changed >= 10000) {
    storeValues();
    need_store = false;
  }

  if ((current - last_changed >= 5000) && (current - last_key_pressed >= 5000)) {
    eq_mode = true;
    if (current_mode != mode_volume) {
      current_mode = mode_volume;
      prev_mode = mode_volume;
      enc.setValue(values[mode_volume]);
    }
  } else {
    eq_mode = false;
  }

  // process current value change (except channel / passthru / mono)
  if (current_mode_is_tones && prev_values[current_mode] != values[current_mode]) {
    last_changed = current;
    need_store = true;
    prev_values[current_mode] = values[current_mode];
    sendPT2322Value(current_mode, values[current_mode]);
    sendMatrix();
    eq_mode = false;
  }

  // process volume in switch mode
  if (current_mode_is_switches && prev_values[mode_volume] != values[mode_volume]) {
    last_changed = current;
    need_store = true;
    prev_values[mode_volume] = values[mode_volume];
    sendPT2322Value(mode_volume, values[mode_volume]);
    sendMatrix();
  }

  // process input switch / passthru / mono
  if (current_mode_is_switches && prev_values[current_mode] != values[current_mode]) {
    last_changed = current;
    need_store = true;
    prev_values[current_mode] = values[current_mode];
    sendPcf();
    eq_mode = false;
  }

  // process mute change
  if (prev_mute != now_mute) {
    last_changed = current;
    need_store = true;
    prev_mute = now_mute;
    sendPT2322All(false);
    sendMatrix();
    eq_mode = false;
  }

  if (eq_mode && char_loaded != 2) {
    loadEqualizerCharacters();
  }

  if (!eq_mode) {
    if (current_mode_is_switches && char_loaded != 3) {
      loadChannelCharacters();
    } 
    else if (current_mode_is_tones && char_loaded != 1) {
      loadVolumeCharacters();
    }
  }

  if (eq_mode) {
    if (info_mode) {
      AppInfo();
    } else {
      AppEq();
    }
  } else {
    switch (current_mode) {
      case mode_volume:
        AppVolume();
        break;
      case mode_channel:
        AppChannel();
        break;
      case mode_passthru:
        AppPassthru();
        break;
      case mode_bass:
        AppBass();
        break;
      case mode_middle:
        AppMiddle();
        break;
      case mode_treble:
        AppTreble();
        break;
      case mode_balance:
        AppBalance();
        break;
      case mode_brightness:
        AppBrightness();
        break;
      case mode_mono:
        AppMono();
        break;
    }
  }
}

void AppVolume() {
  int i = map(values[mode_volume], 0, 100, PT2322_MIN_VOLUME, PT2322_MAX_VOLUME);
  printTitle("VOLUME", i);
  printStoreStatus();
  if (now_mute == true) {
    lcd.setCursor(0, 1);
    lcd.print((COLS == 20) ? F("------- MUTE -------") : F("----- MUTE -----"));
  } else {
    printBar(values[mode_volume]);
  }
}

void AppChannel() {
  int ch = constrain(values[mode_channel], 0, 7);
  printTitle("SOURCE", ch+1);
  printStoreStatus();
  printChannelBar(ch);
}

void AppPassthru() {
  int en = constrain(values[mode_passthru], 0, 1);
  
  lcd.setCursor(0, 0);
  lcd.print(F("EQ PASSTHRU"));

  printStoreStatus();

  lcd.setCursor(0, 1);
  lcd.write( (en == 1) ? 2 : 1);
  lcd.print(F(" enabled"));

  lcd.setCursor(0, 2);
  lcd.write( (en == 1) ? 1 : 2);
  lcd.print(F(" disabled"));

}

void AppMono() {
  int mono = constrain(values[mode_mono], 0, 4);
  
  lcd.setCursor(0, 0);
  lcd.print(F("MONO DOWNMIX"));

  printStoreStatus();

  lcd.setCursor(0, 1);
  lcd.write( (mono == 0) ? 2 : 1);
  lcd.print(F(" Stereo "));

  lcd.setCursor(0, 2);
  lcd.write( (mono == 1) ? 2 : 1);
  lcd.print(F(" Mono A  "));
  lcd.write( (mono == 2) ? 2 : 1);
  lcd.print(F(" Mono B "));
  
  lcd.setCursor(0, 3);
  lcd.write( (mono == 3) ? 2 : 1);
  lcd.print(F(" Mono AB "));
  lcd.write( (mono == 4) ? 2 : 1);
  lcd.print(F(" Reverse"));
  
}

void AppBass() {
  int i = map(values[mode_bass], 0, 100, PT2322_MIN_TONE, PT2322_MAX_TONE);
  printTitle("BASS", i);
  printStoreStatus();
  printBar(values[mode_bass]);
}

void AppMiddle() {
  int i = map(values[mode_middle], 0, 100, PT2322_MIN_TONE, PT2322_MAX_TONE);
  printTitle("MIDDLE", i);
  printStoreStatus();
  printBar(values[mode_middle]);
}

void AppTreble() {
  int i = map(values[mode_treble], 0, 100, PT2322_MIN_TONE, PT2322_MAX_TONE);
  printTitle("TREBLE", i);
  printStoreStatus();
  printBar(values[mode_treble]);
}

void AppBrightness() {
  int i = map(values[mode_brightness], 0, 100, 0, 15);
  printTitle("BRIGHTNESS", i);
  printStoreStatus();
  printBar(values[mode_brightness]);
}

void AppBalance() {
  printTitle("BALANCE", values[mode_balance]);
  printStoreStatus();
  printBalance(values[mode_balance]);
}

void AppEq() {
  readMsgeq();

  lcd.setCursor(0, ROWS - 1);
  lcd.print(F("L"));
  lcd.setCursor(COLS - 1, ROWS - 1);
  lcd.print(F("R"));

  printStoreStatus();

  for (int i = 0; i < 7; i++) {
    int val_L = map(eq_L[i], 0, 1023, 0, 8 * ROWS);
    int val_R = map(eq_R[i], 0, 1023, 0, 8 * ROWS);
    for (int j = 0; j < ROWS; j++) {
      int mx = 8 * (j + 1);
      int v_l = (val_L >= mx) ? 8 : val_L - mx + 8;
      if (v_l < 0) v_l = 0;
      int v_r = (val_R >= mx) ? 8 : val_R - mx + 8;
      if (v_r < 0) v_r = 0;

      lcd.setCursor(i + ((COLS == 20) ? 2 : 1), ROWS - j - 1);
      if (v_l == 1 || v_l == 2 || v_l == 3) lcd.write(1);
      if (v_l == 4 || v_l == 5 || v_l == 6) lcd.write(2);
      if (v_l == 7 || v_l >= 8) lcd.write(3);
      if (v_l == 0) lcd.write(4);

      lcd.setCursor(i + ((COLS == 20) ? 11 : 8), ROWS - j - 1);
      if (v_r == 1 || v_r == 2 || v_r == 3) lcd.write(1);
      if (v_r == 4 || v_r == 5 || v_r == 6) lcd.write(2);
      if (v_r == 7 || v_r >= 8) lcd.write(3);
      if (v_r == 0) lcd.write(4);
    }
    //delay(2);
  }
}

void AppInfo() {
  int volume = map(values[mode_volume], 0, 100, PT2322_MIN_VOLUME, PT2322_MAX_VOLUME);
  int balance = values[mode_balance];
  int bass = map(values[mode_bass], 0, 100, PT2322_MIN_TONE, PT2322_MAX_TONE);
  int middle = map(values[mode_middle], 0, 100, PT2322_MIN_TONE, PT2322_MAX_TONE);
  int treble = map(values[mode_treble], 0, 100, PT2322_MIN_TONE, PT2322_MAX_TONE);
  int ch = constrain(values[mode_channel], 0, 7) + 1;
  int mono = constrain(values[mode_mono], 0, 4);
  int passthrough = constrain(values[mode_passthru], 0, 1);
  
  lcd.setCursor(0,0);
  lcd.print(F("VOL ")); 
  if (now_mute == true) {
    lcd.print(F("MUTE"));
  } else {
    lcd.print(volume);
    lcd.print(F("dB"));
  }

  lcd.setCursor(10,0);
  lcd.print(F("BAL "));
  lcd.print(balance);
  lcd.print(F(" %"));

  lcd.setCursor(0,1);
  lcd.print(F("BAS ")); 
  lcd.print(bass);
  lcd.print(F("dB"));

  lcd.setCursor(10,1);
  lcd.print(F("CH "));
  lcd.print(ch);

  lcd.setCursor(0,2);
  lcd.print(F("MID ")); 
  lcd.print(middle);
  lcd.print(F("dB"));

  lcd.setCursor(10,2);
  switch (mono) {
    case 0:
      lcd.print(F("STEREO"));
    break;
    case 1:
      lcd.print(F("MONO A"));
    break;
    case 2:
      lcd.print(F("MONO B"));
    break;
    case 3:
      lcd.print(F("MONO A+B"));
    break;
    case 4:
      lcd.print(F("REVERSE"));
    break;
  }

  lcd.setCursor(0,3);
  lcd.print(F("TRE ")); 
  lcd.print(treble);
  lcd.print(F("dB"));

  lcd.setCursor(10,3);
  switch (passthrough) {
    case 0:
      lcd.print(F("EQ ON"));
    break;
    case 1:
      lcd.print(F("EQ OFF"));
    break;
  }
  
}

void powerUp() {

  audio.muteOn();

  lcd.clear();
  delay(50);

  lcd.setCursor(0, 0); lcd.print(F("    HI-FI STEREO    "));
  lcd.setCursor(0, 1); lcd.print(F("    Version 2.53    "));
  lcd.setCursor(0, 2); lcd.print(F("                    "));
  lcd.setCursor(0, 3); lcd.print(F("   Made in Ukraine  "));

  delay(500);

  lcd.setCursor(0, 1); lcd.print(F("                    "));
  lcd.setCursor(0, 2); lcd.print(F("      BOOTING       "));
  lcd.setCursor(0, 3); lcd.print(F("                    "));

  /*int steps = BOOT_DELAY / 50;
    for (int i=0; i<=steps; i++) {
    int j = map(steps, 0, steps, 0, 100);
    j = constrain(j, 0, 100);
    printBar(j);
    delay(50);
    }*/
  delay(BOOT_DELAY);

  audio.muteOff();

  lcd.clear();
  delay(50);

  lcd.setCursor(0, 0); lcd.print(F("                    "));
  lcd.setCursor(0, 1); lcd.print(F("                    "));
  lcd.setCursor(0, 2); lcd.print(F("      LOADING       "));
  lcd.setCursor(0, 3); lcd.print(F("                    "));

  bool relay_on = false;
  int volume = values[mode_volume];
  for (int i = 0; i <= volume; i++) {
    values[mode_volume] = i;
    sendPT2322Value(mode_volume, i);
    if (i == 10) {
      relay_on = true;
      digitalWrite(PIN_RELAY1, HIGH);
      digitalWrite(PIN_RELAY2, HIGH);
    }
    printBar(i);
    delay(50);
  }

  if (!relay_on) {
    relay_on = true;
    digitalWrite(PIN_RELAY1, HIGH);
    digitalWrite(PIN_RELAY2, HIGH);    
  }

  lcd.clear();
}

/**
   Restore values from EEPROM
*/
void restoreValues() {

  byte value;
  int addr;

  // volume / bass / treble / balance / channel
  for (int i = 0; i < NUM_MODES; i++) {
    addr = i + EEPROM_ADDRESS_OFFSET;
    value = EEPROM.read(addr);
    // defaults

    if (i == mode_channel && (value < 0 || value > 7)) {
      value = 0;
    } 
    if (i == mode_passthru && (value < 0 || value > 1)) {
      value = 0;
    }  
    if (i == mode_mono && (value < 0 || value > 4)) {
      value = 0;
    }    
    if (i != mode_channel && i != mode_passthru && i != mode_mono && (value < 0 || value > 100)) {
      value = (i == mode_balance) ? 50 : 0;
    }
    values[i] = value;
    prev_values[i] = value;
  }

  // mute switch
  //addr = NUM_MODES + EEPROM_ADDRESS_OFFSET;
  //byte _mute = EEPROM.read(addr);
  //now_mute = (_mute > 0) ? true : false;
}

/**
   Store value into the EEPROM
*/
void storeValue(int mode) {
  int addr = mode + EEPROM_ADDRESS_OFFSET;
  EEPROM.write(addr, values[mode]);
}
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

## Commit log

2013-04-14 Added new simple summator
    [amp_kt3102_summator_v_1_0.brd, amp_kt3102_summator_v_1_0.sch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]
2013-06-18 Added msgeq7 and pt2322 boards, updated firmware to work with these boards
    [amp_msgeq7_v_1_0.brd, amp_msgeq7_v_1_0.sch, amp_pt2322_v_1_0.brd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]
2013-12-30 project cleanup (removed all unused boards / libraries / resources)
    [amp_kt3102_summator_v_1_0.brd, amp_kt3102_summator_v_1_0.sch, amp_summator_v_1_0.brd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]
2019-02-19 Added interface board for 20x4 lcd, improved firmware for 20x4, refactored pt2322 board
    [amp_interface2_v_1_0.brd, amp_interface2_v_1_0.sch, amp_pt2322_v_1_0.brd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]
2019-02-28 Fixed tons of small bugs, switched to NewEncoder library, etc
    [AmpInterface2.ino]
2019-03-12 latest changes: fixed mute on/off
    [AmpInterface2.ino]
2019-04-13 Added input source switcher on PCF8574 + 74HC4051
2019-04-29 added mono/stereo switches
2019-04-30 bugfixes, reorganized menus and analog buttons control
    [AmpInterface2.ino]
2019-05-05 Added Reverse Stereo switch, fixed mute
    [AmpInterface2.ino]
2019-12-25 reverted board on TDA8425
    [amp_tda8425_v_1_0.brd, amp_tda8425_v_1_0.sch]

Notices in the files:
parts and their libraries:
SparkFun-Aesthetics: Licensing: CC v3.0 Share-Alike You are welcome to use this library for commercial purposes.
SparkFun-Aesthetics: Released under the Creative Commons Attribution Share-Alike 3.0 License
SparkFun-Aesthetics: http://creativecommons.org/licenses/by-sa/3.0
